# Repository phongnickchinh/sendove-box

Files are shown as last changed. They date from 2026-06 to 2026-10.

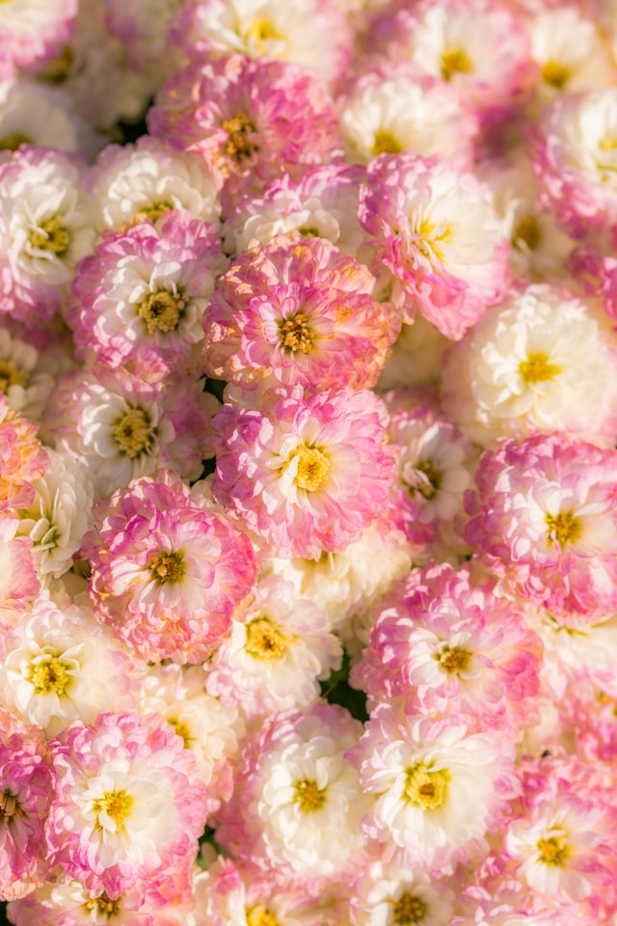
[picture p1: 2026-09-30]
sendlove_web/src/assets/login-hero.jpg

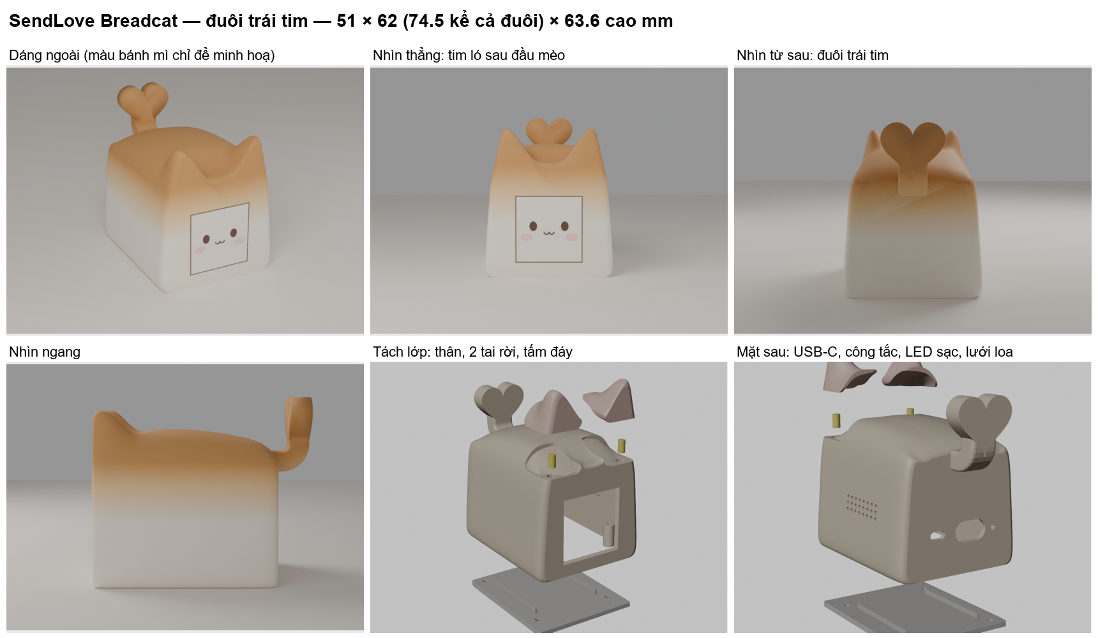
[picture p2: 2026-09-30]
sendlove_enclosure/breadcat/tong_hop.png

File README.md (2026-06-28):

# Sendlove Box

Dự án Hộp quà thông minh kết nối Wi-Fi, hiển thị video và phát âm thanh từ người gửi thông qua Firebase.

## Tổng quan phần cứng
- Vi điều khiển: ESP32-C3 (Kiến trúc RISC-V, tối ưu năng lượng)
- Màn hình: TFT LCD 1.77 inch (Giao tiếp SPI)
- Âm thanh: Module amply MAX98357A (Giao tiếp I2S) + Loa Mini
- Lưu trữ: Thẻ nhớ MicroSD + Module MicroSD (Giao tiếp SPI)
- Cảm biến chạm: Module điện dung TTP223
- Nguồn: Pin Lipo 3.7V + Mạch sạc TP4056 Type-C

## Kiến trúc phần mềm
- **Firmware**: C++ trên nền tảng PlatformIO. Sử dụng hệ điều hành thời gian thực FreeRTOS (Task-based architecture).
- **Backend**: Firebase Realtime Database (lưu cờ trạng thái) & Cloud Storage (lưu trữ phương tiện).
- **Frontend**: Web App (HTML/CSS/JS, Web Audio API, Canvas API) nhằm offload tác vụ xử lý tệp tin từ ESP32-C3 lên trình duyệt.

Chi tiết về đặc tả use case, luồng hoạt động và phương pháp thiết kế xem tại [ACTION_PLAN.md](ACTION_PLAN.md).

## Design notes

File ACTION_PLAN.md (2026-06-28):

# TÀI LIỆU ĐẶC TẢ KIẾN TRÚC VÀ KẾ HOẠCH DỰ ÁN: SENDLOVE BOX
*Phiên bản: 1.1 | Trạng thái: Sẵn sàng phát triển*

Tài liệu này đóng vai trò là "Bản thiết kế thi công" (Blueprint) cho toàn bộ dự án Sendlove Box, bao phủ từ phần cứng, firmware, backend cho đến luồng tương tác người dùng.

---

## 1. TỔNG QUAN CÔNG NGHỆ & PHƯƠNG PHÁP THIẾT KẾ

### 1.1. Danh sách công nghệ (Tech Stack)
* **Phần cứng (Microcontroller):** ESP32-C3 (Kiến trúc RISC-V, tối ưu năng lượng).
* **Firmware Framework:** C++ trên nền tảng PlatformIO. Sử dụng FreeRTOS API tích hợp sẵn trong ESP-IDF/Arduino Core để quản lý Task.
* **Cloud Backend:** Firebase Blaze Plan (Pay-as-you-go). Bao gồm các dịch vụ: Authentication (Xác thực), Realtime Database (Lưu cờ trạng thái), Cloud Storage (Lưu file nhị phân) và Hosting (Lưu mã nguồn Web).
* **Frontend Web App:** HTML/CSS/JS thuần hoặc React/Vue. Tích hợp Web Audio API (Thu âm WAV) và Canvas API (Encode Video sang RAW RGB565).

### 1.2. Các phương pháp thiết kế cốt lõi
* **Kiến trúc "Thin Client" (Trạm cuối siêu nhẹ):** Mọi tác vụ nặng (chuyển đổi video, âm thanh) bị ép lên trình duyệt web của người gửi. Hộp quà ESP32 chỉ làm nhiệm vụ "Tải về và Phát mù" để tiết kiệm RAM và CPU.
* **Quản lý năng lượng "Event-Driven Light-Sleep":** ESP32 duy trì trạng thái ngủ nông (Light-sleep) tắt Wi-Fi. Đánh thức bằng đa sự kiện (Multi-wakeup): Hết thời gian Timer 5 phút hoặc Tín hiệu ngắt (Interrupt) từ cảm biến chạm.
* **Smartwatch UI Style:** Màn hình TFT mặc định tắt đèn nền (thông qua băm xung PWM chân BLK). Chỉ sáng lên khi có tương tác vật lý (chạm) hoặc khi tới giờ báo thức.
* **Hệ điều hành thời gian thực (RTOS):** Chuyển từ kiến trúc vòng lặp nguyên thủy sang kiến trúc Task-based (FreeRTOS) để quản lý đa tiến trình song song.

---

## 2. DANH SÁCH LINH KIỆN PHẦN CỨNG (BOM)

| STT | Tên Linh kiện | Chức năng & Thông số kỹ thuật |
| :--- | :--- | :--- |
| 1 | **ESP32-C3 Super Mini** | Vi điều khiển chính, quản lý Wi-Fi, SPI, I2S. |
| 2 | **Màn hình TFT LCD 1.77 inch** | Giao tiếp SPI. Nối chân BLK (Backlight) vào 1 chân GPIO để điều tốc PWM. |
| 3 | **Module MicroSD Card** | Giao tiếp SPI. Đọc/ghi dữ liệu phương tiện. |
| 4 | **Thẻ nhớ MicroSD** | Dung lượng 2GB - 16GB, định dạng FAT32. |
| 5 | **Module MAX98357A** | Amply Class D, giao tiếp I2S (giải mã tín hiệu số ra analog). |
| 6 | **Loa Mini** | Trở kháng 8 Ohm, Công suất 1W - 2W. |
| 7 | **Module TTP223** | Cảm biến điện dung siêu nhạy (Touch Sensor). |
| 8 | **Đèn LED + Trở 330Ω** | Thông báo trạng thái (Hiệu ứng Breathing). |
| 9 | **Pin Lipo 3.7V** | Dung lượng 2000mAh (Kích thước phù hợp lòng hộp). |
| 10 | **Module TP4056 Type-C** | Mạch sạc và bảo vệ pin Lipo. |
| 11 | **Dây điện AWG 30 & AWG 24** | Loại lõi đặc (Solid core) để uốn góc 90 độ, đi dây trực tiếp. |
| 12 | **Vỏ hộp in 3D** | Nhựa PETG hoặc PLA+ (Màu Matte/nhám). |

---

## 3. THIẾT KẾ USE CASE & TÁC NHÂN (ACTORS)

**Tác nhân 1: Người gửi (Sender)**
1. Đăng nhập / Xác thực (Login).
2. Tạo thông điệp Video/GIF (Create Visual Message).
3. Tạo thông điệp Âm thanh (Create Voice Message).
4. Xem trước thông điệp (Preview).
5. Gửi thông điệp (Send Message).
6. Kiểm tra trạng thái Hộp quà (Check Box Status).

**Tác nhân 2: Người nhận (Receiver)**
1. Đăng nhập không gian quản lý (Login).
2. Cài đặt báo thức / Nhắc nhở (Set Alarm).
3. Xem lịch sử thông điệp (View History).
4. Xem dung lượng pin Hộp quà (Check Battery).
5. Chạm để mở quà / Xem giờ (Touch to Wake).

**Tác nhân 3: Hộp quà (Smart Box - Sbox)**
1. Đồng bộ thời gian thực (NTP Sync).
2. Kiểm tra và Tải dữ liệu định kỳ (Fetch Media).
3. Hiển thị Đa phương tiện (Play Media).
4. Quản lý trạng thái Ngủ (Sleep Management).
5. Báo cáo phần trăm pin (Report Battery).

---

## 4. ĐẶC TẢ CHI TIẾT USE CASE

**UC_S05: Gửi thông điệp (Tác nhân: Sender)**
* **Điều kiện tiên quyết:** Sender đã đăng nhập, đã encode xong file `.bin` và `.wav` trên trình duyệt. Sbox đã được kích hoạt.
* **Luồng cơ bản:** Trình duyệt đẩy file `.bin` và `.wav` lên Firebase Cloud Storage. Storage trả về 2 link tải. Trình duyệt cập nhật vào Realtime DB biến `has_new_msg = true` kèm theo 2 link trên. Giao diện báo gửi thành công.
* **Hậu điều kiện:** Máy chủ lưu trữ file sẵn sàng chờ Sbox tải.

**UC_R02: Cài đặt báo thức (Tác nhân: Receiver)**
* **Điều kiện tiên quyết:** Receiver truy cập Web App quản lý.
* **Luồng cơ bản:** Receiver nhập mốc thời gian báo thức (VD: 07:30). Web App đẩy chuỗi thời gian này lên node `config/alarm_time` trên Firebase Realtime DB.
* **Hậu điều kiện:** Sbox sẽ đọc và lưu cấu hình này vào chu kỳ thức dậy tiếp theo.

**UC_R05: Chạm để mở quà hoặc xem giờ (Tác nhân: Receiver & Sbox)**
* **Điều kiện tiên quyết:** Sbox đang trong trạng thái Light-sleep.
* **Luồng cơ bản:** Receiver chạm tay vào vỏ hộp. Cảm biến TTP223 kích hoạt ngắt phần cứng. Sbox thức dậy tức thời, kiểm tra cờ `co_tin_nhan` trên RAM.
* **Nhánh A (co_tin_nhan = true):** Bật đèn nền TFT, xuất đồng thời file từ thẻ SD ra SPI (hình ảnh) và I2S (âm thanh). Chạy xong, chuyển cờ về `false`, tắt màn hình.
* **Nhánh B (co_tin_nhan = false):** Tạm bật Wi-Fi kiểm tra Firebase ("Pull-to-refresh"). Nếu phát hiện có tin nhắn, tải về và chuyển sang Nhánh A. Nếu không có, hiển thị mặt Đồng hồ trong 5 giây, sau đó tắt màn hình.
* **Hậu điều kiện:** Sbox ra lệnh tắt Wi-Fi và gọi hàm vào lại Light-sleep.

**UC_Sbox01: Đồng bộ dữ liệu định kỳ (Tác nhân: Sbox)**
* **Điều kiện tiên quyết:** Sbox vừa thức dậy do hết 5 phút của Timer.
* **Luồng cơ bản:** Sbox bật Wi-Fi, kết nối mạng. Gọi HTTP GET lấy cấu hình báo thức mới và kiểm tra cờ `has_new_msg` trên Firebase. Nếu cờ là `true`, tải stream file `.bin` và `.wav` ghi thẳng vào thẻ SD. Đổi cờ nội bộ `co_tin_nhan = true`. Gọi HTTP PUT lên Firebase chuyển cờ trên cloud thành `false`.
* **Hậu điều kiện:** Dữ liệu nằm an toàn trong thẻ SD, Sbox ngắt mạng và đi ngủ chờ chạm.

---

## 5. MÔ TẢ API VÀ CẤU TRÚC DATABASE (FIREBASE)

**Firebase Realtime Database (Cấu trúc JSON)**
```json
{
  "boxes": {
    "box_id_001": {
      "status": {
        "battery_percent": 85,
        "is_online": false,
        "last_sync_timestamp": 1719567890
      },
      "messaging": {
        "has_new_msg": true,
        "video_url": "[https://firebasestorage.googleapis.com/.../video_001.bin](https://firebasestorage.googleapis.com/.../video_001.bin)",
        "voice_url": "[https://firebasestorage.googleapis.com/.../voice_001.wav](https://firebasestorage.googleapis.com/.../voice_001.wav)"
      },
      "config": {
        "alarm_time": "07:30",
        "is_alarm_active": true,
        "timezone": 7
      }
    }
  }
}
Firebase Cloud Storage Structure

/media/box_id_001/video_latest.bin (Ghi đè mỗi khi có tin nhắn mới).

/media/box_id_001/voice_latest.wav

6. KIẾN TRÚC FIRMWARE: PHƯƠNG PHÁP TASK (FREERTOS)
Task 1: Task_PowerManager (Độ ưu tiên: Cao nhất)
Nhiệm vụ quản lý sự sống còn của hộp. Lắng nghe cờ báo công việc từ các Task khác. Ra lệnh ngắt Wi-Fi, cài đặt Timer 5 phút, cài ngắt GPIO cảm biến chạm và gọi lệnh Light-sleep. Khi thức dậy, xác định nguyên nhân và phân luồng đánh thức các Task tương ứng.

Task 2: Task_NetworkHandler (Độ ưu tiên: Trung bình)
Chuyên trách giao tiếp mạng (Chỉ chạy khi PowerManager gọi). Bật Wi-Fi, cập nhật giờ NTP. Gọi HTTP GET/PUT tương tác với Firebase. Quản lý việc stream dữ liệu từ URL thẳng vào File object của thẻ MicroSD (Sử dụng buffer để chống tràn RAM).

Task 3: Task_MediaPlayer (Độ ưu tiên: Cao)
Phát hình ảnh và âm thanh mượt mà (Chỉ chạy khi có lệnh chạm). Sử dụng DMA (Direct Memory Access) để đọc block dữ liệu từ SD Card. Bơm song song buffer ảnh ra SPI và buffer âm thanh ra I2S. Đảm bảo đồng bộ hình tiếng.

Task 4: Task_UI_Controller (Độ ưu tiên: Thấp)
Quản lý hiệu ứng hình ảnh phụ. Điều khiển băm xung PWM cho LED nhịp thở. Điều tốc PWM chân BLK của màn hình (Sáng 100% ban ngày, 20% ban đêm). Xử lý chống nhiễu (Debounce) cho tín hiệu chạm.

7. YÊU CẦU PHI CHỨC NĂNG (NON-FUNCTIONAL REQUIREMENTS)
Hiệu năng (Performance): Tốc độ phản hồi khi chạm để bật màn hình phải nhỏ hơn 50ms. Tốc độ khung hình Video (Framerate) duy trì 15 - 20 FPS.

Năng lượng (Power): Dòng điện khi ngủ (Light-sleep) phải dưới 2mA. Thời lượng pin duy trì từ 15 đến 20 ngày với viên pin 2000mAh (Chu kỳ check mạng 5 phút/lần).

Lưu trữ (Storage): File .bin và .wav không vượt quá 15MB/tin nhắn để đảm bảo tính ổn định khi tải xuống bằng vi điều khiển.

Bảo mật (Security): Mọi kết nối API đi qua HTTPS. Firebase Rules chỉ cho phép user xác thực đúng box_id được quyền ghi/đọc.

Khả năng bảo trì (Maintainability): Không hàn chết linh kiện thành một khối. Sử dụng ngàm in 3D hoặc băng keo xốp 3M để cố định module.

8. CÁC LUỒNG HOẠT ĐỘNG CHÍNH (MAIN WORKFLOWS)
Luồng 1: Định kỳ nhận tin nhắn ngầm (Background Sync)
Sbox ngủ 5 phút -> Thức dậy bởi Timer -> Task_Network bật mạng, check Firebase -> Tải file vào thẻ SD -> Đổi cờ co_tin_nhan = true -> Task_UI bật LED nhịp thở -> Task_PowerManager ngắt mạng, tiếp tục ngủ.

Luồng 2: Tương tác mở quà tiêu chuẩn (Standard Playback)
Sbox đang ngủ (LED nháy) -> Người nhận chạm tay -> Thức dậy bởi GPIO Interrupt -> Task_PowerManager kiểm tra thấy có tin nhắn -> Task_MediaPlayer đẩy dữ liệu từ SD ra màn hình và loa -> Phát xong, tắt LED, tắt màn hình -> Task_Network báo Firebase đã đọc -> Vào giấc ngủ.

Luồng 3: Tương tác "Kéo để làm mới" hoặc xem giờ
Sbox đang ngủ (Không LED) -> Người nhận chạm tay -> Thức dậy -> Task_Network bật mạng kiểm tra Firebase.
Nếu có quà ẩn: Tải file và gọi Task_MediaPlayer phát ngay lập tức.
Nếu không có quà: Task_UI hiển thị mặt đồng hồ trong 5 giây, sau đó tắt màn hình và tiếp tục ngủ.

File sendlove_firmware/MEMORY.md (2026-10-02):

# SENDLOVE BOX - PROJECT MEMORY & CONTEXT

*Tài liệu này lưu trữ toàn bộ bối cảnh dự án, kiến trúc phần cứng, phần mềm và lịch sử các task để phục hồi context cho Agent trong các session tương lai.*

## 1. MÔ TẢ DỰ ÁN
**Sendlove Box** là một hộp quà tặng thông minh/video player dựa trên ESP32-C3.  
- **Core Functionality**: Trình chiếu video có âm thanh, hiển thị hình ảnh, giao diện đồng hồ Standby (động theo JSON), điều khiển chạm, đồng bộ thời gian thực qua WiFi/NTP và kết nối đám mây (Firebase).
- **MCU**: ESP32-C3-DevKitM-1 (160MHz, 320KB RAM, 4MB Flash).
- **USB CDC**: Kích hoạt trên GPIO 18/19 (`ARDUINO_USB_CDC_ON_BOOT=1` cho nạp code và in Serial).

---

## 2. KIẾN TRÚC PHẦN CỨNG
- **Màn hình**: TFT LCD 1.54"/1.3" ST7789 240x240 IPS. (Không có chân CS).
- **Lưu trữ Media**: W25Q128 (16MB NAND Flash SPI).
- **Điều khiển**: Touch Sensor TTP223 (GPIO 10, Active HIGH).
- **Sơ đồ chân (Pinout)**:
  - **Shared Hardware SPI2 Bus**: SCK (GPIO 4), MOSI (GPIO 6).
  - **TFT ST7789**: DC (7), RST (9), BL (3 - PWM). *CS = -1 (Không có)*.
  - **NAND W25Q128**: CS (8), MISO (5).
  - **Touch TTP223**: GPIO 10 (Active HIGH, INPUT_PULLDOWN).

> **Hardware Challenge (Đã giải quyết)**: 
> Màn hình ST7789 không có chân CS nên luôn nhận xung nhịp SPI. Việc chia sẻ chung bus SPI2 với NAND Flash gây hiện tượng nhiễu hình ảnh khi đọc dữ liệu NAND.
> **Giải pháp đang áp dụng**:
> - Đồng bộ cùng `SPI_MODE3` cho cả LGFX và NAND để không lệch bit do SCK Idle nhảy.
>   - ⚠️ **Đính chính 2026-09-04 — con số 3 KHÔNG bắt buộc, cái bắt buộc là CẢ BUS DÙNG CHUNG
>     MỘT MODE.** Cả MODE0 lẫn MODE3 đều lấy mẫu ở sườn LÊN; thiệt hại nằm ở mức idle của SCK —
>     đổi CPOL giữa hai chủ bus sinh 1 sườn lên giả nên ST7789 chốt nhầm 1 bit. MODE3 được chọn
>     chỉ vì driver flash dùng nó. Từ nay mode nằm ở `SPI_BUS_MODE` (`config.h`), đổi theo
>     `ACTIVE_STORAGE_TYPE`: **MODE3 cho NAND (không đổi), MODE0 cho thẻ SD** — vì thư viện `SD`
>     của Arduino-ESP32 hardcode `SPI_MODE0` và `SD.begin()` không có tham số mode. Xem mục 12.
>   - ❌ **ĐÍNH CHÍNH TRÊN LÀ SAI — kiểm chứng máy thật 2026-09-17**: nạp bản SD chạy MODE0 thì
>     **màn hình đen hoàn toàn** (đèn nền, touch, tiếng bíp vẫn chạy). Ép lại MODE3 thì hiển thị bình
>     thường. Panel ST7789 không CS này **BẮT BUỘC MODE3** — comment gốc "Mode 3 (obligatory)" ở
>     `DisplayDriver.h` là đúng từ thực nghiệm. Hướng đã chọn: chép thư viện SD vào `lib/SD` và đổi
>     sang MODE3 (xem mục 12).
> - Lệnh Hack NOP (`0x00`) với TFT_DC=0 rồi kéo TFT_DC=1 trước mỗi phiên lấy SPI Mutex của NAND, giúp màn hình ST7789 bỏ qua dữ liệu giao tiếp với Flash.

---

## 3. KIẾN TRÚC PHẦN MỀM (FIRMWARE)
- **Platform**: PlatformIO (Arduino Framework cho ESP32).
- **Libraries**:
  - `LovyanGFX` (Display driver chính, hỗ trợ bus_shared = true).
  - `JPEGDEC` (Giải mã VJPG / JPEG trực tiếp từ buffer NAND).
  - `ArduinoJson` (v7.0.0 - Parse cấu hình UI Layout động từ JSON).
- **Core Logic & State Machine**:
  - Trạng thái hệ thống: `STATE_STANDBY` (Hiển thị đồng hồ/ngày/icon WiFi & Pin) <-> `STATE_VIDEO` (Phát video/ảnh từ NAND).
  - **Task_MediaPlayer** (Priority 3, Stack 8KB): Render Standby UI theo chu kỳ 1s hoặc giải mã JPEG 15fps liên tục từ NAND Flash.
  - **Task_UIController** (Priority 5 - Cao nhất, Stack 4KB): Polling touch sensor (10ms/lần = 100Hz), quản lý LED và chuyển đổi state/slot qua `eventQueue`.
- **Cấu trúc Module (`lib/`)**:
  - `DisplayDriver`: Đóng gói LovyanGFX, mutex SPI.
  - `NandStorage`: Đọc NAND SPI Flash W25Q128 & Slot Table (Storage chính).
  - `SDCardManager`: Đọc/ghi thẻ MicroSD SPI (Storage linh hoạt).
  - `MediaPlayer`: Điều khiển phát frame VJPG qua JPEGDEC.
  - `UIController`: Đọc cảm ứng TTP223, điều khiển trạng thái LED.
  - `NetworkManager`: Quản lý hạ tầng Wi-Fi (STA, SoftAP Provisioning) & đồng bộ giờ NTP.
  - `FirebaseClient`: Giao tiếp Firebase REST API (check tin nhắn, status) & HTTP Stream Download.
  - `PowerManager`: Quản lý linh hoạt chế độ ngủ (Light-Sleep & Deep-Sleep) & Đọc ADC dung lượng Pin LiPo.
  - `LayoutEngine`: Render giao diện Standby động theo JSON config (Clock, Date, Icons).
  - `ConfigManager`: Đọc/ghi cấu hình NVS.
  - `OtaHandler`: OTA Firmware Update qua mạng LAN (WebServer + Update.h).

> **OTA WebServer Lifecycle**:
> Hiện tại WebServer luôn bật khi có WiFi (port 80, mDNS `sendlovebox.local`).
> Tương lai khi ghép nối hệ thống phần mềm, WebServer sẽ chỉ được kích hoạt
> khi người dùng trigger từ web client (tiết kiệm tài nguyên).

---

## 4. QUẢN LÝ DỮ LIỆU NAND (SLOT TABLE)
- **Cấu trúc**: 5 Slot lưu trữ (Video VJPG / Image VIMG).
- **Header**: Sector 0 (Địa chỉ `0x000000`), bắt đầu bằng Magic string `"NSLT"`.
- Addresses: `0x010000`, `0x340000`, `0x670000`, `0x9A0000`, `0xCD0000`.
- Module `NandStorage` chỉ thực hiện Read-Only để bảo tồn dữ liệu gốc đã được flash.

---

## 5. LỊCH SỬ CÔNG VIỆC (TASK LOG)

### Phase 1: Màn hình + NAND Read + Touch (Completed)
- [x] Quy hoạch GPIO dùng Shared HW SPI2 cho TFT và NAND.
- [x] Lập trình `DisplayDriver` bọc LovyanGFX.
- [x] Lập trình `NandStorage` API (Hardware SPI) cho đọc Slot Table và frames.
- [x] Lập trình `MediaPlayer` với `JPEGDEC` giải mã luồng từ `NandStorage`.
- [x] Fix lỗi xung đột SPI giữa ST7789 và W25Q128 (Đồng bộ SPI_MODE3, NOP Hack, Fix USB CDC boot delay).

### Phase 2: Standby UI & Dynamic Power Management (Current - In Progress)
- [x] Xây dựng `NetworkManager` kết nối WiFi (STA + SoftAP Captive Portal) & NTP Time Synchronization (`pool.ntp.org`, UTC+7).
- [x] Xây dựng `FirebaseClient` xử lý REST API Firebase và HTTP Stream Download.
- [x] Nâng cấp `PowerManager` hỗ trợ 2 chế độ **Light-Sleep** (1ms wakeup) và **Deep-Sleep** (5µA low-power).
- [x] Tích hợp khóa giữ mức LOW cho chân Backlight PWM (`PIN_TFT_BLK`) bằng `gpio_hold_en` giúp tắt hẳn màn hình khi ngủ.
- [x] Thêm USB Power Fallback (giả lập 4.0V khi chạy nguồn USB chưa cắm pin) để tránh hiểu nhầm hết pin.
- [x] Cấu hình ngắt GPIO Wakeup chuẩn cho TTP223 (GPIO 10) đánh thức chip từ Light-Sleep.
- [x] Xây dựng `LayoutEngine` parse và render giao diện Standby từ JSON config (widgets: clock_time, clock_date, wifi_icon, battery_icon).
- [x] Thiết lập State Machine (`STATE_STANDBY` <-> `STATE_VIDEO`) phản hồi sự kiện chạm TTP223.
- [x] Thêm thư viện `ArduinoJson@^7.0.0` vào `platformio.ini`.
- [x] Tối ưu FreeRTOS Task Priority (`TASK_PRIORITY_UI_CONTROLLER = 5`).
- [x] Triển khai OTA Update qua mạng LAN (WebServer + Update.h + ota_upload.py).
- [x] Custom Partition Table cho OTA A/B (app0 + app1 = 1.75MB mỗi partition).
- [x] Fix lỗi Light Sleep Wakeup trên ESP32-C3: Re-init toàn bộ LGFX pipeline (SPI bus + ST7789 panel + LEDC PWM) trong `turnOn()`, thêm `if(Serial)` & `delay(200)` cho USB CDC re-enumeration.
- [x] Fix lỗi nháy dư ảnh / xé hình góc dưới màn hình khi chuyển slot: Khóa SPI transaction (`startWrite`/`endWrite`) trong `decodeOneFrame()`, thêm cờ `_isSleeping` tránh re-init thừa khi màn hình đang bật.
- [x] Chuyển đổi hình nền mẫu pastel marble (`bg_defaut.png`) thành mảng $240 \times 240$ RGB565 `StandbyBackground.h` (115KB `PROGMEM`).
- [x] Triển khai thuật toán Bounding Box Patch (`drawBackgroundPatch`) cắt miếng dán hình nền khôi phục vị trí widget trước khi vẽ đè chữ/icon.
- [x] Tích hợp cờ Dirty Flag Cache (`_lastTimeStr`, `_lastDateStr`, `_lastRssiBars`, `_lastBatPercent`) giảm 98% lượt vẽ thừa trên SPI bus.
- [x] Convert và tích hợp 2 font Google **Chakra Petch SemiBold**: 48pt (`ChakraPetch_SemiBold_48.h`) cho đồng hồ giờ và 16pt (`ChakraPetch_SemiBold_16.h`) cho ngày tháng.
- [x] Đổi màu chữ đồng hồ/ngày/icon sang màu Đen (`#000000`) và Đỏ đậm (`#B83D3D`) nổi bật trên nền đá cẩm thạch pastel.
- [x] Fix lỗi chữ có khung nền đen: Thêm `canvas->setTextColor(cfg.color)` (1 tham số) ép LovyanGFX vẽ chữ ở chế độ nền trong suốt (Transparent Background).
- [x] Nới rộng Bounding Box lên `160x45` tránh viền chữ Chakra Petch 48pt tràn khung gây dư ảnh vết chữ cũ.
- [x] Tối ưu hóa đồng bộ thời gian NTP ngầm & Bộ đếm RTC nội bộ:
- [x] Xây dựng Lớp Trừu Tượng Lưu Trữ Media (`IStorageProvider`): Hỗ trợ đa bộ nhớ linh hoạt giữa NAND Flash (`NandStorageProvider`) và Thẻ nhớ SD (`SDStorageProvider`).
- [x] Khắc phục lỗi nén JSON Firebase dài: Triển khai Zero-Copy JsonDocument + `http.getString()` chống mất/tràn mảng tin nhắn Firebase URL.
- [x] Khắc phục lỗi ghi Flash NOR khi download stream: Cấu hình cơ chế Auto Per-Sector Erase (`_lastErasedSectorAddr`) và chừa 4-byte Offset Reserve ở `openForWrite()` giúp bảo toàn 100% dữ liệu tệp `.bin` tải về từ Firebase.
- [x] Hỗ trợ định dạng tệp `SLBX` Native (128x160 Raw RGB565 Framebuffer): Nhận diện container header `SLBX` tự động, căn giữa hiển thị trên LCD 240x240 với tốc độ 1ms không qua `JPEGDEC`. Tương thích 100% tệp container `SLBX`/`VJPG`/`VIMG` lẫn ảnh RAW JPEG.
  - `getTimeString()` và `getDateString()` đọc trực tiếp mốc giờ RTC nội bộ ESP32 (`getLocalTime(&timeinfo, 0)` không chờ / timeout = 0).
  - Loại bỏ hoàn toàn hiện tượng chớp màn hình về `00:00` và `Loading...` khi chuyển phút hoặc rớt Wi-Fi tạm thời.
  - Lệnh `configTzTime()` chỉ gọi 1 lần duy nhất lúc `init()`. Tiến trình NTP chạy ngầm trên FreeRTOS task (`Task_NtpSyncWorker`), không gây nghẽn/khựng UI.
  - Áp dụng ngưỡng sai số 5s (5s Drift Threshold): So sánh mốc giây NTP với RTC ($\Delta t = |ntpNow - rtcNow|$), nếu $\Delta t \le 5$s thì giữ nguyên RTC tránh nhảy/lùi phút trên UI.
  - Loại bỏ polling 15s/1h liên tục trong `NetworkManager::update()`. Chỉ gọi `triggerNtpSync()` theo sự kiện khi vừa boot hoặc vừa tỉnh dậy sau Light Sleep.
- [x] Tối ưu hóa chu kỳ Light Sleep Wakeup nâng thời lượng pin 1000 mAh từ **4.5 ngày lên ~23 NGÀY**:
  - Phân biệt nguyên nhân thức dậy `esp_sleep_get_wakeup_cause()` trong `main.cpp`.
  - Nếu thức dậy do Timer 5 phút (`ESP_SLEEP_WAKEUP_TIMER`): Màn hình giữ nguyên TẮT, chip chỉ Active **2 giây (`activeSleepTimeoutMs = 2000`)** cho NTP Sync ngầm chạy xong rồi **chui vào Light Sleep lại ngay lập tức** (giảm thời gian Active/chu kỳ từ 60s xuống 2s, giảm 96.6% thời gian thức vô ích).
  - Nếu thức dậy do Touch cảm ứng (`ESP_SLEEP_WAKEUP_GPIO`): Bật màn hình Standby và cho phép chờ 30s (`INACTIVITY_SLEEP_TIMEOUT_MS`).
  - Dòng tiêu thụ trung bình giảm từ `7.81mA` xuống **`~1.5mA`**, thời gian chờ của pin 1000 mAh tăng từ 4.5 ngày lên **~23 NGÀY** (gấp 5 lần).

### Phase 2.5: Big Refactoring & Optimization (Completed)
- [x] **Phase 1 (Chống Phân mảnh Bộ nhớ)**: Loại bỏ hoàn toàn việc lạm dụng `String` trong `NetworkManager`, `LayoutEngine`, `OtaHandler`. Chuyển sang dùng `char[]` tĩnh và `snprintf()`, triệt tiêu rò rỉ RAM (OOM / Heap Fragmentation).
- [x] **Phase 2 (Kiến trúc Task & DRY)**:
  - Phân tách `network.update()` ra FreeRTOS task riêng `Task_NetworkController` (Priority 2, Stack 8KB), giải quyết triệt để lỗi WebServer block UI Task (Priority 5).
  - Tạo module `SystemMonitor` quản lý nhiệt độ chip và bộ nhớ RAM, loại bỏ code lặp ở `LayoutEngine` và `MediaPlayer`.
  - Thêm helper `drawTextWidget` trong `LayoutEngine` giúp tái cấu trúc gọn gàng các widget text.
- [x] **Phase 3 (Bảo mật, NVS & Captive Portal Wi-Fi)**:
  - Tích hợp `ConfigManager` lưu Wi-Fi credentials vào NVS Flash (`Preferences`).
  - Xây dựng luồng Wi-Fi Provisioning: Tự động phát AP `SendloveBox-Setup` kèm Captive Portal Web UI (có nút ẩn/hiện mật khẩu `👁️`) khi chưa cài mạng hoặc mất Wi-Fi.
  - Thêm cờ `!network.isProvisioningActive()` ngăn thiết bị chui vào Light Sleep khi đang bật AP cài đặt.
- [x] **Phase 4 (Tối ưu SRAM & AppContext)**:
  - Chuyển `_jpegBuffer` 48KB từ mảng static giam RAM vĩnh viễn sang cấp phát động (`malloc()` khi phát media và `free()` ngay khi dừng), hoàn trả 48KB RAM cho màn hình Standby.
  - Gom toàn bộ 9 biến toàn cục trong `main.cpp` vào struct `AppContext appCtx` theo chuẩn Clean Architecture.

### Phase 3A: Storage Abstraction Layer (Completed)
- [x] Tạo interface trừu tượng `IStorageProvider` định nghĩa tập API đọc/ghi luồng byte và quản lý hàng chờ tin nhắn.
- [x] Xây dựng `NandStorageProvider` bọc chip W25Q128 16MB (quản lý 5 slot fixed offset + unread bitmask trên NVS).
- [x] Xây dựng `SDStorageProvider` bọc thẻ MicroSD FAT32.
- [x] Refactor `MediaPlayer` và `main.cpp` tách khỏi sự phụ thuộc NAND thô, cho phép chuyển đổi linh hoạt NAND <-> SD Card qua cờ `#define ACTIVE_STORAGE_TYPE` trong `config.h`.

### Phân tách Kiến trúc Chuẩn (Separation of Concerns):
1. **Bài toán Pairing (Web App / Cloud Backend):**
   - Ghép nối giữa **Sender App <-> System <-> Receiver App**.
   - Hộp quà ESP32 hoàn toàn không cần tham gia logic này. Kết quả pairing chỉ chốt thông tin trên Cloud Database.
2. **Bài toán Bảo mật (Firmware Box <-> Cloud System):**
   - Xác thực giao tiếp giữa **ESP32 Box <-> Firebase System**.
   - ESP32 chỉ cần dùng `BOX_ID` + `Token` (hoặc Database Secret) lưu trong NVS để xác thực đường truyền HTTPS và tải đúng dữ liệu tin nhắn của Box mình về.

---

## 6. LƯU Ý PHẦN CỨNG & KIẾN THỨC KỸ THUẬT QUAN TRỌNG

### A. Cơ chế ngắt & Wakeup trên ESP32-C3
1. **Phần cứng nhận biết nguyên nhân Wakeup (`esp_sleep_get_wakeup_cause`)**:
   - Khi CPU đi vào Light/Deep Sleep, khối **RTC Power Management Controller (Always-On Domain)** vẫn liên tục giám sát phần cứng.
   - Khi sự kiện chạm (GPIO_10 HIGH) hoặc hết giờ (RTC Timer) xảy ra, phần cứng RTC tự động ghi cờ (bit) vào thanh ghi `RTC_CNTL_WAKEUP_STATE_REG` **trước khi cấp lại xung clock đánh thức CPU**.
   - Hàm `esp_sleep_get_wakeup_cause()` chỉ việc đọc thanh ghi phần cứng này ra mà không cần CPU phải chạy code đếm trước đó.
2. **Cấu hình Touch Wakeup (TTP223)**:
   - Sử dụng `GPIO_PULLDOWN_ENABLE` trên GPIO 10 để kéo chân xuống GND, tránh chân bị floating (trôi điện áp gây tự thức dậy ngẫu nhiên).
   - Sử dụng kiểu ngắt `GPIO_INTR_HIGH_LEVEL` kích hoạt qua `gpio_wakeup_enable()` và `esp_sleep_enable_gpio_wakeup()`.
3. **Phân biệt chân Wakeup theo Sleep Mode**:
   - **Light Sleep Wakeup**: Hỗ trợ toàn bộ các chân GPIO 0-21 (GPIO 10 hoạt động rất tốt).
   - **Deep Sleep Wakeup**: Chỉ hỗ trợ các chân RTC GPIO (GPIO 0 -> GPIO 5 trên ESP32-C3). Nếu muốn chuyển sang dùng Deep Sleep với TTP223, bắt buộc phải nối lại phần cứng sang GPIO 0-5.

### B. Cơ chế đếm nối thời gian thực & NTP Sync ngầm
1. **Bộ đếm RTC nội bộ (RTC Slow Clock)**:
   - Khi gọi `configTzTime()`, ESP-IDF lấy mốc Unix Epoch từ NTP Server và liên kết với bộ đếm phần cứng RTC Timer.
   - Khi vào Light Sleep, CPU dừng nhưng RTC Timer vẫn đếm liên tục.
   - Gọi `getLocalTime(&timeinfo, 0)` với timeout = 0 đọc trực tiếp mốc giờ RTC mà không bị nghẽn hay chờ đợi.
2. **Phân biệt Modem Sleep (Duy trì IP) vs Full Wi-Fi Off (`WIFI_OFF`)**:
   - **Modem Sleep (Light Sleep tự động ngắt RF)**: Cắt nguồn phần cứng thu phát RF nhưng **giữ lại 100% IP, WPA2 Key và Session trong RAM**. Khi thức dậy, gửi gói tin NTP được ngay trong 0.1-0.3s (~27mAs).
   - **Full Wi-Fi Off (`WIFI_OFF`)**: Xóa sạch Driver Wi-Fi. Khi thức dậy phải quét kênh, bắt tay WPA2 4 bước và xin lại IP từ DHCP, mất 1.5 - 3.0s (~300mAs).
3. **Điểm bão hòa năng lượng (Break-even Point)** giữa Modem Sleep và `WIFI_OFF`:
   - Phép tính bão hòa năng lượng: $(1.2 \cdot T) + 27 = (0.8 \cdot T) + 300 \Rightarrow T = 682.5\text{s} = \mathbf{11\text{ phút } 22\text{ giây}}$.
   - **Thời gian ngủ $< 11.37$ phút** (ví dụ chu kỳ 5 phút): **Modem Sleep tiết kiệm hơn ~28%** (tránh được chi phí 300mAs bắt tay lại Wi-Fi).
   - **Thời gian ngủ $> 11.37$ phút** (ví dụ ngủ qua đêm 8 tiếng): **`WIFI_OFF` tiết kiệm hơn ~32.5%** (do chênh lệch dòng rò 0.4mA tích lũy lâu dài).

### C. Quản lý tiêu thụ điện năng & Đèn LED báo nguồn (Power LEDs)
1. **Thực trạng ngốn pin của LED báo nguồn**:
   - Trên bo mạch ESP32 DevKit và Module NAND Flash W25Q128 đều có sẵn đèn LED đỏ báo nguồn (Power LED) nối trực tiếp VCC-GND qua điện trở.
   - **Dòng tiêu thụ**: 2 con LED đỏ ngốn tổng cộng **$\approx 3\text{mA} - 6\text{mA}$**.
   - Trong khi đó:
     - ESP32-C3 ở **Light Sleep**: Chỉ tiêu thụ $\approx 1.0\text{mA}$ (LED ngốn gấp 4 lần chip).
     - ESP32-C3 ở **Deep Sleep**: Chỉ tiêu thụ $\approx 0.005\text{mA}$ / $5\mu\text{A}$ (LED làm lãng phí 99.9% năng lượng pin).
   - **Tác động**: Làm giảm thời gian chờ của pin 1000mAh từ **52 ngày xuống chỉ còn 9 ngày**!
2. **Giải pháp khắc phục**:
   - *Bản Prototype*: Dùng mỏ hàn xả bỏ (tháo) LED báo nguồn / điện trở hạn dòng trên DevKit và Module NAND Flash, hoặc dán băng keo đen che sáng.
   - *Bản thiết kế PCB thực tế*: Không vẽ LED báo nguồn cố định; dùng P-Channel MOSFET (AO3401) hoặc Power Switch IC (TPS22919) để cắt hẳn nguồn 3.3V cấp cho Module NAND khi chip đi vào chế độ ngủ.

### D. Khóa phần cứng RTC GPIO Hold và Reboot (`ESP.restart()`)
- Khi gọi `gpio_hold_en(PIN_TFT_BLK)` trước khi ngủ, mạch RTC phần cứng khóa chân Backlight (GPIO 3) ở mức `LOW`.
- Trạng thái **GPIO Hold phần cứng này được bảo lưu qua cả quá trình Software Reset / Reboot (`ESP.restart()`)**.
- Nếu không giải phóng khóa, sau khi reboot màn hình sẽ bị tối om dù code khởi tạo đã chạy.
- **Giải pháp**: Luôn gọi `gpio_hold_dis((gpio_num_t)PIN_TFT_BLK)` ngay đầu hàm `DisplayDriver::init()` để giải phóng cờ khóa phần cứng khi khởi động lại.

### E. Quy tắc tính toán `millis()` tránh tràn số âm (Underflow Bug)
- Với kiểu dữ liệu `uint32_t`, **tuyệt đối không gán mốc thời gian ở tương lai** (ví dụ: `lastUserActivity = millis() + 15000`), vì phép tính `now - lastUserActivity` ở vòng lặp sau sẽ bị underflow tràn số ra `4,294,952,306` (làm `now - lastUserActivity >= timeout` luôn trả về `true` lập tức).
- **Giải pháp**: Giữ `lastUserActivity = millis()` chuẩn thời gian thực và thay đổi giá trị điều kiện so sánh `activeSleepTimeoutMs` (15s cho Touch Wakeup, 30s cho Timer Wakeup, 2s cho Timer Sleep Wakeup).

### Phase 3B: Firebase Realtime Database & Storage Wakeup Integration (Completed)
- [x] Tích hợp trực tiếp Firebase REST API vào `NetworkManager` (`syncFirebaseWakeup`, `updateFirebaseStatus`, `checkFirebaseFlags`, `syncFirebaseAlarms`, `checkAndDownloadNewMessages`).
- [x] Loại bỏ hoàn toàn interval timers riêng. Đồng bộ tập trung 1 lần khi chip tỉnh dậy (Timer Wakeup 5 phút hoặc Touch Wakeup).
- [x] Triển khai tính toán sleep timer động trong `ConfigManager::getSecondsToNextAlarm(nowSec)` và `main.cpp`: `sleepTimeUs = min(SLEEP_TIMER_US, alarmUs)`.
- [x] Hỗ trợ tải dữ liệu media streaming dạng chunk 256B từ Firebase Storage vào thẳng `IStorageProvider` (NAND/SD) tránh tràn RAM ESP32-C3.
- [x] **Tối ưu hóa Non-blocking Touch UI**: Tạo `NetworkManager::triggerFirebaseSync(...)` khởi chạy task ngầm FreeRTOS (`FbSync`, Stack 8KB, Priority 2). Giải phóng 100% `Task_UIController` (Priority 5) giúp vòng lặp đọc cảm ứng TTP223 100Hz hoạt động liên tục, hoàn toàn không bị block/giật lag khi mạng HTTPS đang sync.
- [x] **Ghi thật vào SPI Flash W25Q128 (16MB)**: Triển khai lệnh `eraseSector` (4KB sector erase `0x20`) và `writeRaw` (Page Program `0x02` 256B) trong `NandStorage` & `NandStorageProvider`. Dữ liệu media tải từ Firebase Storage được ghi đè trực tiếp vào các Slot Flash thực tế của chip W25Q128.
- [x] **Tính năng Erase/Format NAND Flash khi boot**: Đã thêm `formatStorage()` giúp xóa sạch Sector 0 (Header) và 5 Sector của 5 Slot mẫu cũ trên chip W25Q128 + reset cờ `unread_mask` NVS về 0.
- [x] **Tín hiệu trực quan & Khóa chống ngủ khi tải (Download Sleep Lock & UI Signal)**: Thêm cờ `_isDownloadingMedia` và `NetworkManager::isDownloadingMedia()`. Tự động bật màn hình hiển thị `"Downloading..."` (và `"Download Done!"` khi xong), đồng thời khóa `Task_UIController` không cho chip chui vào Light Sleep trong suốt thời gian tải dữ liệu mạng.
- [x] **Khắc phục triệt để lỗi `Storage Err!` khi Format**: Thêm `NandStorage::writeSlotTable()`. Khi chip Flash bị Format/xóa Sector 0, `NandStorage::init()` tự động kiến tạo lại bảng Header `"NSLT"` mới sạch sẽ, loại bỏ hoàn toàn treo màn hình `Storage Err!`.
- [x] **Thông báo Debug trực quan trên màn hình (`DEBUG_SCREEN`)**: Bổ sung hiển thị trực quan các bước giao tiếp Firebase trên màn hình TFT (`"Checking Firebase..."`, `"Polling Msg..."`, `"No New Msg"` / `"Found New Msg!"`, phần trăm tiến độ `"Downloading XX%"`, `"Download Done!"` và thông báo mã lỗi HTTP nếu có) với comment `// DEBUG_SCREEN:` rõ ràng để dễ dàng thu hồi sau này.
- [x] **Sửa lỗi `FB http Err: 400` (Firebase REST 400 Bad Request)**: Bỏ các tham số `orderBy` và `startAt` trong URL REST API (nguyên nhân đòi hỏi Database Indexing Rules trên Firebase), chuyển sang lọc `if (timestamp > lastTs)` trực tiếp trong code C++.
- [x] **Sửa lỗi `FB HTTP Err: -1` (Connection Refused / Network Not Ready)**: Thêm vòng lặp chờ Wi-Fi re-associate ổn định và xin lại IP (tối đa 5s) khi vừa đi ngủ dậy từ Light Sleep + cơ chế tự thử lại `http.GET()` lần 2 nếu bị rớt socket tạm thời.
- [x] **Hiển thị mốc timestamp `lastTs` & `msgTs` trên màn hình**: Bổ sung debug hiển thị giá trị `lastTs` trong NVS và `msgTs` đọc được từ Firebase lên màn hình TFT để xác minh lý do tin nhắn bị xem là cũ và bị Skip.
- [x] **Đồng bộ Firebase tức thì khi boot (`Boot-time Instant Sync`)**: Thêm `triggerFirebaseSync(...)` trực tiếp vào `setup()` của `main.cpp` giúp ESP32 tự động sync Firebase ngay khi vừa nạp code/bật nguồn thành công mà không phải chờ 30 giây hay đợi ngắt chạm.
- [x] **Reset mốc `lastTs` về 0 khi Format Flash**: Tích hợp reset mốc thời gian NVS `last_download_ts` về `0` trong `NandStorageProvider::formatStorage()`, giúp ESP32 sẵn sàng kéo lại toàn bộ tin nhắn từ Firebase từ đầu sau khi xóa dữ liệu Flash NAND.
- [x] **Khóa Sleep toàn diện trong lúc Sync (`isFirebaseSyncing`)**: Sửa cờ khóa sleep trong `main.cpp` từ `isDownloadingMedia` (chỉ khóa khi tải file) thành `isFirebaseSyncing` (khóa toàn bộ chu trình từ lúc bắt đầu gọi request). Đảm bảo chip thức liên tục 100% trong suốt quá trình giao tiếp Firebase, không bị sập nguồn/ngủ giữa chừng (Sleep interrupt) gây ngắt quãng tải dữ liệu.
- [x] **Xử lý linh hoạt Link Firebase Storage**: Tự động nhận diện và convert đường dẫn dạng relative path (VD: `media/ESP32...`) hoặc `gs://...` được lưu trên Database thành dạng HTTPS REST Download URL hợp lệ (`https://firebasestorage.googleapis.com/...`) để ESP32 có thể tải file thành công bằng `HTTPClient`.
- [x] **Cảnh báo thiếu đường dẫn tải (`No Media URL!`)**: Thêm hiển thị báo lỗi chữ đỏ `"No Media URL!"` nếu tin nhắn mới kéo về không hề chứa đường link (`bin_url`, `video_url`, hoặc `image_url`) nhằm giúp debug tại sao bị skip tiến trình Download.
- [x] **Xử lý triệt để lỗi mất URL dài (`Zero-Copy JSON Parsing & Flexible Key Matcher`)**: Chuyển về `deserializeJson(doc, payload)` Zero-Copy. Đồng thời nâng cấp bộ parser hỗ trợ linh hoạt cả cấu trúc Firebase `JsonObject` và `JsonArray`, tự động quét tất cả các biến thể đặt tên key (`bin_url`, `binUrl`, `video_url`, `videoUrl`, `image_url`, `imageUrl`, `media_url`, `mediaUrl`, `url`) để đọc đúng 100% dữ liệu từ Firebase.
- [x] **Xử lý tự động hiển thị Ảnh/Video ngay khi tải từ Firebase (`Raw JPEG & Slot Header Auto-Generation`)**: 
  - Khắc phục triệt để nguyên nhân tải 100% nhưng không hiện ảnh: Khi tải từ Firebase về Flash NAND, code tự động kiểm tra byte đầu tiên. Nếu là file ảnh `.jpg` thô (`0xFF 0xD8 0xFF`), ESP32 sẽ tự động chèn 4-byte `jpegSize` vào đầu dữ liệu slot.
  - Tự động ghi nhãn `"VIMG"` (cho ảnh) hoặc `"VJPG"` (cho video) vào bảng Slot Table (`Sector 0`) để `NandStorage` và `MediaPlayer` công nhận Slot hợp lệ và lập tức giải mã hiển thị hình ảnh rực rỡ trên màn hình LCD.
- [x] **Tự động phát Media ngay sau khi tải xong (`Auto Play on Download Complete & Screen Overwrite Fix`)**: Tích hợp Event-driven callback `setOnDownloadComplete`. Đã loại bỏ triệt để xung đột giao diện làm chữ `"All Sync Done!"` in đè và xóa mất bức ảnh vừa được `MediaPlayer` hiển thị. Bức ảnh/video sẽ được giữ nguyên 100% rực rỡ trên màn hình LCD.
- [x] **Thông báo hoàn tất (`All Sync Done`)**: Thêm hiển thị chữ `"All Sync Done!"` trên màn hình khi toàn bộ tiến trình Firebase đã kết thúc thành công.
- [x] **Cập nhật Quy tắc Indexing trên Firebase (`database.rules.json`)**: Bổ sung `.indexOn: ["timestamp"]` cho node `messages/$box_id`, cho phép lọc Server-side trên Firebase.
- [x] Tối ưu Server-side Filtering & Zero-Copy Stream Parsing (`NetworkManager`):
  - Đính kèm query parameters `orderBy="timestamp"&startAt=<nextTs>` vào HTTP GET request gửi lên Firebase REST API. Khi không có tin mới, Firebase Server trả về `{}` (2 bytes), giảm 99% tải băng thông & CPU/RAM cho Box.
  - Sử dụng Stream parsing trực tiếp từ HTTP socket (`deserializeJson(doc, *stream)`), loại bỏ hoàn toàn cấp phát mảng chuỗi tạm `http.getString()`, chống triệt để phân mảnh RAM Heap trên ESP32-C3.
- [x] Biên dịch thành công 100% (`[SUCCESS]`), RAM 19.0% (62KB/328KB), Flash 71.3% (1.30MB/1.83MB).

### Phase 3C: Advanced Playback & Touch Refactoring (Completed)
- [x] **Cấu trúc lại Metadata Storage (maxDisplayTime)**: Tận dụng vùng nhớ `reserved` 4-byte trong bảng Header `SlotEntry` của NAND Flash Sector 0 để lưu trữ tĩnh thông số `max_display_time`.
- [x] **Refactor cơ chế Touch (Long/Short Press)**: Nâng cấp `UIController` nhận diện `SHORT_PRESS` (bấm nhanh chuyển slot, đánh dấu đã đọc) và `LONG_PRESS` (bấm giữ 3s ép về Standby mà không đánh dấu đã đọc).
- [x] **Biến đếm `_numOfNewMsg`**: Theo dõi chính xác tổng tin nhắn chưa đọc còn lưu trong NAND Flash cộng với tin đang chờ tải trên Cloud. Box dừng phát khi xem xong tin mới (khi biến về 0) thay vì lặp lại vòng tròn các slot cũ.
- [x] **An toàn NAND Flash (Chặn Download khi Play)**: Box chỉ trigger tiến trình Download khi RAM/SPI bus rảnh rỗi ở màn hình chờ (người dùng xem xong tin cũ, Touch bị vô hiệu hóa tạm thời với thông báo `Downloading...`).
- [x] **Auto Timeout Next**: Tự động chuyển media sau khi hiển thị đủ `maxDisplayTime` giây (hoặc quay về UI nếu hết tin).
- [x] **Interval Sync & Full Storage Guard**: Tự động check Firebase định kỳ 5 phút/lần khi ở màn hình Standby, đồng thời kiểm tra `appCtx.storage->isFull()`. Nếu toàn bộ 5 slot NAND đều chứa tin chưa đọc (đầy), hệ thống tự động bỏ qua lượt check ngầm để tránh block cảm ứng và tiết kiệm mạng/RAM.
- [x] **Sắp xếp thứ tự phát tin nhắn (`std::sort`)**: Ép mảng `msgList` qua `std::sort` theo mốc `timestamp` tăng dần trước khi lưu NAND, đảm bảo 100% tin nhắn cũ nhất luôn phát trước, tin mới phát sau.
- [x] **Fix SPI Deadlock khi Render Ảnh lớn (Chunking)**: Sửa hàm `decodeOneFrame()` trong `MediaPlayer.cpp` đọc từng chunk pixel từ NAND trước, sau đó mới acquire SPI để push lên LCD, loại bỏ hoàn toàn hiện tượng xé hình / mất 2/3 ảnh đối với file > 48KB.
- [x] **KISS 10s Awake Polling & Independent Sleep Timer**: Thiết lập kiểm tra Firebase ngầm định kỳ 10 giây/lần khi ở Standby UI (`now - lastIntervalSyncMs >= 10000`). Đồng thời tách biệt hoàn toàn bộ đếm ngủ `lastUserActivity` (chỉ reset khi chạm tay hoặc đang thực sự tải tệp media `isDownloadingMedia`), giúp box vừa hút tin nhắn nhạy bén 10s/lần vừa đi ngủ chính xác 100% theo thời gian đếm ngược.
- [x] **Khắc phục triệt để lỗi mất Backlight PWM khi thức dậy**: Loại bỏ hoàn toàn sự quản lý đèn nền của thư viện LovyanGFX (do lỗi từ chối khởi tạo lại và khai báo cứng sai `pwm_channel = 7` không tồn tại trên ESP32-C3). Chuyển sang khởi tạo thủ công bằng Arduino API (Sử dụng Channel 0). Khi ngủ dùng `pinMode(OUTPUT)` / `digitalWrite(LOW)` ép đèn tắt hẳn, khi thức tự gọi `ledcAttach`/`ledcAttachPin` nối lại PWM, giải quyết thành công lỗi đèn sáng mờ khi ngủ và đen màn hình khi thức.
- [x] **Cập nhật Sleep Timeout Logic**: Chặn thiết bị tự động đếm giờ đi ngủ khi đang phát Video. Khi Video phát hết `max_display_time`, rớt về màn hình UI và reset lại mốc tính thời gian ngủ.

---

### Phase 3D: Khắc phục triệt để lỗi Timer Wakeup, Wi-Fi Reconnect & NTP Sync Drift (Completed)
- [x] **Khắc phục lỗi trôi giờ (RTC Fast Drift) khi Sleep dài**:
  - *Nguyên nhân cốt lõi*: `getLocalTime(&timeinfo, timeout)` trong Arduino ESP32 core kiểm tra `tm_year > 2016`. Do time đã được sync lúc boot, hàm này trả về `true` ngay lập tức (0ms) với giờ RTC đang bị trôi từ dao động RC nội bộ, không hề chờ gói tin NTP từ mạng. Đồng thời, `ntpTaskWorker` không khóa tiến trình sleep, khiến chip bị ép vào Light Sleep sau 2s trước khi socket SNTP kịp nhận phản hồi.
  - *Giải pháp*: Đăng ký `sntp_set_time_sync_notification_cb()` (API chính thức ESP-IDF) để nhận callback khi SNTP daemon thực sự gọi `settimeofday()`. Trong `syncNtpTime()`, gọi `configTzTime()` (Arduino API đã chứng minh) để trigger SNTP request mới, rồi poll cờ `s_ntpSyncDone` từ callback thay vì dùng internal API `sntp_get_sync_status()` (đã được chứng minh unreliable trên hardware thật — NTP timeout 100%).
  - *Lưu ý*: Phiên bản đầu tiên dùng `sntp_set_sync_status(RESET)` + `sntp_restart()` + poll `sntp_get_sync_status()` — build thành công nhưng NTP luôn timeout trên hardware thật do internal API không cập nhật status flag đáng tin cậy qua ranh giới LWIP thread / FreeRTOS task.
- [x] **Khắc phục lỗi mất kết nối Wi-Fi sau 1 ngày Sleep**:
  - *Nguyên nhân cốt lõi*: Khi thức dậy từ Light Sleep, `ensureConnected()` gọi `WiFi.reconnect()` bất đồng bộ. Tuy nhiên `triggerNtpSync()` và `triggerFirebaseSync()` kiểm tra ngay `WiFi.status() != WL_CONNECTED` nên lập tức abort. Sau 2 giây, chip lại bị ép đi ngủ, cắt ngang quá trình bắt tay 4 bước (4-way handshake) của Wi-Fi. Lặp lại qua hàng trăm chu kỳ khiến Wi-Fi stack bị kẹt (`AUTH_EXPIRE`/`ASSOC_EXPIRE`).
  - *Giải pháp*: 
    - Nâng cấp `ensureConnected(uint32_t timeoutMs)` 2 tầng: thử `WiFi.reconnect()` trước; nếu không thành công sẽ tự động thực hiện `WiFi.disconnect(false)` và `WiFi.begin(_wifiSsid, _wifiPassword)` để tái thiết lập kết nối sạch sẽ từ đầu.
    - Lưu giữ credentials Wi-Fi trong `NetworkManager` và kích hoạt `WiFi.setAutoReconnect(true)`.
- [x] **Hợp nhất tiến trình Đồng bộ ngầm (`triggerWakeupSync` & `isSyncing`)**:
  - Hợp nhất chu trình: `ensureConnected(5000)` -> `syncNtpTime(5000)` -> `updateFirebaseStatus` -> `checkFirebaseFlags` -> `checkAndDownloadNewMessages` vào 1 FreeRTOS background task duy nhất (`WakeSync`).
  - Cập nhật cờ `isSyncing()` bao quát toàn bộ tiến trình mạng (Wi-Fi, NTP, Firebase, Download). `Task_UIController` được khóa không cho phép chip đi ngủ trong lúc bất kỳ tác vụ mạng nào đang xử lý, triệt tiêu hoàn toàn tình trạng sập nguồn/ngắt giữa chừng.

---

### Phase 3E: Audio I2S, Chống rè/nháy & Captive Portal nâng cấp (2026-08 → 09-01)

> **Đọc kỹ cột trạng thái.** Phần lớn mục dưới đây **chưa được kiểm chứng trên phần cứng**
> và **chưa commit** — chỉ nằm trong working tree. Đừng coi là đã xong.

#### Phần cứng bổ sung (thiếu ở §2 phía trên)
- **Ampli I2S MAX98357A**: BCLK = GPIO 0, LRC = GPIO 1, DOUT = GPIO 2 (`include/config.h:123-125`).
- **Module `AudioPlayer`** (`lib/MediaPlayer/AudioPlayer.cpp/.h`): phát PCM raw 16-bit mono qua
  I2S DMA, thiết kế non-blocking tick-based — mỗi frame video gọi `tick()` một lần nạp thêm DMA.
  Audio nằm nối đuôi video trong cùng một slot NAND, đánh dấu bằng header `AUDC`.
- **Module `ScreenLogger`** (`lib/ScreenLogger/`) — cũng chưa có trong danh sách module ở §3.

#### Nguyên nhân gốc của "rè tiếng + nháy đèn nền" (đã xác nhận bằng đo thực tế của user)
Đèn nền LED và MAX98357A **dùng chung một rail nguồn**. Đỉnh dòng của CPU/SPI cộng dồn lên dòng
ampli đang kéo → LED tối đi (thấy nháy) và ampli đói dòng (nghe rè) **cùng một nhịp**. Không phải
lỗi chất lượng file WAV: user đã nghe file `.wav` sinh ra từ web, xác nhận "ấm áp, không rè".

| Thay đổi | Ở đâu | Trạng thái |
|---|---|---|
| `extractAudioFromVideo` giải mã offline + `DynamicsCompressor` (-6dB) + trần đỉnh 0.7 | `sendlove_web/src/utils/mediaEncoder.js` | Trong working tree, **chưa commit**, đã chạy thật trên trình duyệt |
| Pacer bỏ frame khi trễ (`FRAME_MIN_IDLE_MS=2`, `decodeOneFrame(bool skipRender)`, `_lastFrameSkipped`) | `lib/MediaPlayer/MediaPlayer.cpp/.h` | Đã build + nạp, **CHƯA kiểm chứng phần cứng** |
| Timeout 10s khi tải không tiến triển + log tiến độ mỗi 16KB (video **và** audio) | `lib/NetworkManager/NetworkManager.cpp` | ✅ **ĐÃ KIỂM CHỨNG MÁY THẬT 2026-09-01: tải chạy ổn** |
| Captive portal: `WIFI_AP_STA`, `setErrorReplyCode(NoError)`, 8 URL dò của OS trả 302, endpoint `/scan` quét bất đồng bộ, HTML có danh sách Wi-Fi bấm chọn | `NetworkManager.cpp/.h`, `captive_portal_html.h` | ✅ **ĐÃ KIỂM CHỨNG MÁY THẬT 2026-09-01: AP + captive portal ổn** |
| Fix `fillChunk()` thiếu oversample x4: I2S init 32kHz nhưng data chỉ expand Mono→Stereo (không lặp mẫu) → audio phát nhanh gấp 4 + DMA underrun → tiếng rẹt rời rạc | `lib/MediaPlayer/AudioPlayer.cpp:192-219` | ✅ **ĐÃ KIỂM CHỨNG MÁY THẬT 2026-09-02: audio hết rẹt, đúng tốc độ** |
| Fix giật chậm / âm thanh nhảy ngắt quãng khi phát message: Tắt `ScreenLogger` overlay khi play video, hoãn `WakeSync` mạng trong `STATE_VIDEO`, tăng DMA buffer lên 24 (384ms), bỏ delay thừa và sửa deadline Frame 0 | `MediaPlayer.cpp`, `ScreenLogger.cpp/.h`, `NetworkManager.cpp/.h`, `main.cpp`, `config.h` | ✅ **Đã cập nhật 2026-09-02** |
| Fix Reboot khi Long Press -> Short Press ngay: Giữ I2S driver thường trực (chỉ `i2s_zero_dma_buffer` khi stop, không uninstall/install) + Cấp phát `_jpegBuffer` 48KB cố định 1 lần lúc `init()` (không malloc/free liên tục) | `AudioPlayer.cpp/.h`, `MediaPlayer.cpp/.h` | ✅ **Đã cập nhật 2026-09-02** |
| Nâng cấp chất âm: Triển khai Nội suy tuyến tính (Linear Interpolation) trong `fillChunk()` thay vì lặp mẫu bậc thang (ZOH) → triệt tiêu sóng hài chói gắt, làm mềm và ấm giọng nói | `lib/MediaPlayer/AudioPlayer.cpp:190-210` | ✅ **Đã cập nhật 2026-09-02** |
| Fix Firebase sync lỗi (-1): Giảm MbedTLS buffer từ 33KB xuống 3KB (`setBufferSizes(2048, 1024)`) + giảm I2S DMA buffer từ 24 xuống 12 (giải phóng 54KB RAM cho SSL Handshake) | `NetworkManager.cpp`, `config.h` | ❌ **SAI HẲN — đã chốt 2026-09-03**: I2S DMA buffer 12 thì đúng (`config.h: AUDIO_DMA_BUF_COUNT = 12`), nhưng phần `setBufferSizes(2048,1024)` **KHÔNG THỂ đúng**: grep source Arduino core 2.0.17 (`~/.platformio/packages/framework-arduinoespressif32/libraries/WiFiClientSecure/src/`) cho thấy **`setBufferSizes()` KHÔNG TỒN TẠI trong `WiFiClientSecure` của ESP32** — đó là API của **ESP8266**. Nghĩa là không phải "quên áp dụng" mà là **bất khả thi trên nền tảng này**; nếu từng viết vào code thì đã không compile được. → mbedTLS trên ESP32 luôn dùng in/out content buffer mặc định 16KB mỗi chiều, không chỉnh được từ tầng Arduino. **Đừng đào lại hướng này.** Giữ nguyên dòng gốc bên trái để không xoá lịch sử. |

#### Defect gốc đã tìm ra ở vòng lặp tải (nguyên nhân treo tại `[NET] writing slot`)
`http.getSize()` trả `-1` với response chunked. Điều kiện `while (http.connected() && (len > 0 || len == -1))`
khi đó **không bao giờ tự sai** — chỉ thoát khi server đóng socket. Stream nửa-mở treo vĩnh viễn.
`http.setTimeout(30000)` chỉ chốt **một lần đọc**, không chốt được cả vòng lặp. Khi timeout mới bắn,
phải set `writeError = true` để slot dở bị loại, nếu không file tải dở với `initialLen <= 0` vẫn lọt
qua bước kiểm tra và thành slot rác.

#### Nguyên nhân gốc đã xác nhận của tiếng "rẹt rẹt" rời rạc (ĐÃ FIX 2026-09-02)
**Bug phần mềm trong `AudioPlayer::fillChunk()`**: `AUDIO_OVERSAMPLE = 4` được cấu hình đúng —
I2S init ở `8000 * 4 = 32000Hz`, buffer `_stereo` cấp size cho oversample — nhưng code thực tế
**chỉ expand Mono→Stereo (x2), KHÔNG lặp mỗi mẫu 4 lần**. Hậu quả:
- I2S ở 32kHz ăn data nhanh gấp 4 → audio phát nhanh + hết sớm
- DMA auto-clear phát silence xen kẽ giữa các chunk → tiếng rẹt rời rạc đồng pha với NAND CS
- `loadFromStorage()` gọi `i2s_set_sample_rates(sampleRate)` thiếu nhân OVERSAMPLE → khi WAV
  header có rate khác default, BCLK rớt thấp gây rè liên tục

**Fix đã áp dụng và kiểm chứng thành công trên máy thật (2026-09-02):**
1. `fillChunk()`: thêm vòng lặp `for (r = 0; r < AUDIO_OVERSAMPLE; r++)` lặp mỗi mẫu mono,
   sửa `i2s_write` ghi `samples * OVERSAMPLE * 4` bytes, sửa `_audioCursor` chia `OVERSAMPLE * 2`.
2. `loadFromStorage()`: sửa `i2s_set_sample_rates(I2S_NUM_0, sampleRate * AUDIO_OVERSAMPLE)`.

Build: RAM 23.6% (77KB), Flash 73.3% (1.35MB). Kết quả: **tiếng rẹt boot + rẹt lúc phát đều
biến mất hoàn toàn**. Chỉ còn nháy màn hình rất nhẹ do sụt áp phần cứng (xem mục dưới).

#### Lỗi còn lại: Nháy màn hình nhẹ khi loa phát (sụt áp phần cứng — P1)
- **Triệu chứng**: Đèn nền LCD nháy rất nhẹ đồng pha với âm thanh loa. Không ảnh hưởng trải
  nghiệm nghe, chỉ thấy nếu nhìn kỹ.
- **Nguyên nhân**: MAX98357A và LED backlight dùng chung rail 3.3V. Đỉnh dòng ampli kéo rail
  sụt tạm thời → LED tối đi.
- **Không phải lỗi phần mềm** — firmware đã tối ưu (FRAME_MIN_IDLE_MS=2ms, frame skip).
- **Fix phần cứng cho PCB thật**: Tụ bypass 100uF sát VCC MAX98357A, ferrite bead tách rail
  audio, hoặc LDO riêng cho ampli.

#### Chốt trạng thái 2026-09-02 (user xác nhận trên máy thật)
- ✅ **Wi-Fi AP + captive portal: ĐÃ ỔN.**
- ✅ **Tải file (video + audio) về NAND: ĐÃ ỔN.**
- ✅ **Tiếng rẹt rẹt lúc boot (testBeep): ĐÃ FIX** (delay(200) trước stop + oversample fix).
- ✅ **Tiếng rẹt rẹt lúc phát message: ĐÃ FIX** (fillChunk oversample x4 + loadFromStorage rate fix).
- ⚠️ **Nháy màn hình rất nhẹ khi loa phát**: Vấn đề phần cứng (sụt áp rail chung). Chấp nhận
  được trên prototype. Sẽ fix trên PCB thật bằng tụ bypass / LDO riêng.

#### Các giả thuyết đã loại bỏ (lưu lại để không đào lại)
- ~~"8kHz ra thẳng MAX98357A gây rè"~~ — Bác bỏ: rẹt rời rạc chứ không rè liên tục.
- ~~"Brownout reset loop"~~ — Không xảy ra: `esp_reset_reason()` chỉ in 1 lần.
- ~~"Chân I2S đảo ngược"~~ — Không ảnh hưởng: audio phát đúng sau fix oversample.
- ~~"DMA underrun"~~ — Đúng là underrun nhưng do bug oversample, không phải do DMA quá nông.

#### Quyết định đã CHỐT — không mở lại
- **Giữ 8kHz** cho audio. User chốt: "tôi sẽ giữ nguyên 8khz".
- **KHÔNG giảm độ sáng đèn nền.** User bác thẳng; `MediaPlayer.cpp` giữ `BACKLIGHT_DAY_PERCENT`.
- **Decode video/audio phải chạy ở client**, không đẩy sang backend.
- **Oversample x4** giữ nguyên (`AUDIO_OVERSAMPLE = 4`), đã chứng minh fix triệt để rẹt.
- **Session Rule (2026-09-02)**: Agent **KHÔNG** tự chạy lệnh build PlatformIO (`pio run`) để tiết kiệm thời gian, việc build và flash máy thật do User đảm nhiệm. Agent chỉ tập trung nghiên cứu, rà soát logic và viết code.

---

## 7. TÌNH TRẠNG CODE & PHẦN ĐÃ MẤT (kiểm kê 2026-09-01)

### Code cũ đã mất — TÌM LẠI ĐƯỢC trong git stash
Bản backup mà user tưởng đã mất **vẫn còn**, nằm trong `stash@{1}` (tên "trrr"), ở đường dẫn
`sendlove_firmware/.backup_audio_debug/20260816_004737/`. Thư mục này **không còn trên đĩa** —
chỉ tồn tại trong stash. Gồm 6 file, mốc 2026-08-16 00:47:37:

| File | Số dòng |
|---|---|
| `AudioPlayer.cpp` | 147 |
| `AudioPlayer.h` | 60 |
| `MediaPlayer.cpp` | 371 |
| `NandStorage.cpp` | 350 |
| `NandStorageProvider.cpp` | 293 |
| `NetworkManager.cpp` | 853 |

Đây nhiều khả năng chính là bản "phát âm thanh mượt, hình ra chậm nhưng không nháy" mà user nhắc
đi nhắc lại — thứ đáng đối chiếu để hiểu vì sao bản cũ không bị sụt áp.

Lấy ra **không phá working tree hiện tại** (stash này có 2 parent nên đọc thẳng, không cần `^3`):

```
git show "stash@{1}:sendlove_firmware/.backup_audio_debug/20260816_004737/MediaPlayer.cpp" > /nơi/nào/đó.cpp
```

`stash@{1}` còn chứa `STATUS.md` ghi lại một task sửa `writeChunk` **bị chặn giữa chừng** vì xung
đột quyền khi gọi `agy` headless — kế hoạch sửa còn dang dở, chưa áp dụng.

### `stash@{0}` ("big stash")
28 file, ≈1015 thêm / 587 xóa. Danh sách file **trùng khớp với working tree bẩn hiện tại**
(MEMORY.md, platformio.ini, 11 file web, `VoiceInput.css` bị xóa...). Gần như chắc chắn là ảnh
chụp của chính trạng thái đang làm dở, **không phải** code mất. Đừng pop bừa — sẽ đụng độ.

### Ba nhánh local `ff`, `phong-tuyet-vong`, `pjhonggg`
Đều là **tổ tiên của `main`**, không chứa `AudioPlayer.cpp`. Không có gì để cứu ở đây.

### Chỗ tài liệu này đang sai / thiếu so với code thật
- §4 viết "`NandStorage` chỉ thực hiện Read-Only" — **sai từ Phase 3B**, module đã có
  `eraseSector`, `writeRaw`, `writeSlotTable`.
- §2 không nhắc gì tới ampli I2S / MAX98357A; §3 thiếu `AudioPlayer` và `ScreenLogger`.
  (Đã bổ sung ở Phase 3E bên trên.)

### Rác cần dọn
- `sendlove_firmware/src/main.cpp.bak` — file thừa.
- Working tree bẩn: 11 file web + `platformio.ini` + `MEMORY.md`, cùng các thư mục chưa track
  (`DRAFT/`, `sendlove_web/src/components/ui/`, `src/styles/`, `sendlove-box-style-guide.md`,
  `FE_DESIGN.md`, `HANDOFF.md`, `MULTI_PLATFORM_STRATEGY.md`, `firebase-debug.log`).
  **Chưa quyết** giữ / commit / bỏ.

### Ràng buộc bảo mật (không được vi phạm)
Không push, không tạo PR — chỉ làm local. Ba file bí mật không bao giờ commit (đã có trong
`.gitignore`): `sendlove_firmware/include/config_secrets.h`, `sendlove_web/.env`,
`sendlove_backend/serviceAccountKey.json`.

---

## 8. PHASE 3F — Kiến trúc Đồng bộ Tối ưu RAM, Triệt tiêu Lỗi (-1) & Hết Giật Audio (2026-09-02)

### Bối cảnh & Bản chất gốc rễ của 2 lỗi tương hỗ

1. **Lỗi Firebase Sync (-1) (Out of Memory cho MbedTLS)**:
   - `WiFiClientSecure` cần ~35KB-40KB heap động liên tục để thực hiện SSL Handshake với Firebase.
   - Khi `_jpegBuffer` (48KB) bị ghim cố định trong RAM, cùng với I2S DMA (24KB hoặc 48KB) và task stacks (38KB), tổng RAM bị chiếm giữ vĩnh viễn là >180KB trên tổng 200KB heap khả dụng của ESP32-C3.
   - Heap chỉ còn ~16KB-30KB bị phân mảnh -> MbedTLS handshake thất bại -> `http.GET()` trả về `-1`.

2. **Lỗi Video Delay & Âm thanh nhảy cóc**:
   - `AUDIO_PCM_CHUNK_SIZE = 1600` (12.8KB stereo). Trong khi I2S DMA mỗi 10ms chỉ tiêu thụ 1.28KB (160 bytes mono input).
   - `fillChunk()` đọc 1600B từ NAND qua SPI nhưng `i2s_write` chỉ nhận 160B rồi vứt 1440B còn lại.
   - Mỗi giây đọc SPI NAND **100 lần** (160KB/s thay vì 16KB/s), chiếm `_spiMutex` liên tục khiến `MediaPlayer` bị nghẽn SPI khi render JPEG lên ST7789 display.

### Giải pháp Kiến trúc Đã Áp dụng

1. **Cân chỉnh Chunk Size vừa khít 1 DMA Buffer**:
   - `AUDIO_PCM_CHUNK_SIZE = 256` bytes (128 mono samples = 16ms @ 8kHz).
   - Khi oversample x4 stereo: 128 * 4 * 4 bytes = **2048 bytes = ĐÚNG 1 DMA BUFFER** (`AUDIO_DMA_BUF_LEN = 512` samples).
   - Tiết kiệm **12.1KB** static RAM trong `AudioPlayer` (buffer `_stereo` giảm từ 12.8KB xuống 2.0KB).
   - Đọc NAND cực nhanh (100 µs), không đọc thừa 1 byte nào, không tranh chấp SPI bus.

2. **Đồng bộ Audio Tick Trước & Sau Mỗi Frame (Loại bỏ Audio Task riêng)**:
   - Trong `MediaPlayer::update()`: gọi `_audio.tick()` trước khi decode JPEG (đảm bảo DMA đầy 192ms) và ngay sau khi decode/push image (bù ngay lượng vừa phát trong lúc decode).
   - Với DMA 192ms và thời gian decode mỗi frame ~40-60ms, DMA luôn duy trì mức >130ms, **không bao giờ bị underrun hay nhảy cóc**.
   - Loại bỏ task `AudioTick` riêng giúp tiết kiệm **2KB** stack và loại bỏ 100% xung đột mutex giữa 2 task.

3. **Thu gọn Task Stacks & Buffer On-Demand**:
   - `TASK_STACK_MEDIA_PLAYER = 6144`, `TASK_STACK_NETWORK = 6144`, `TASK_STACK_UI_CONTROLLER = 4096` -> tiết kiệm thêm **8KB** heap.
   - `_jpegBuffer` giảm từ 48KB xuống **32KB** (đủ cho 100% video/ảnh JPEG 240x240 và SLBX chunked).
   - `_jpegBuffer` cấp phát khi `playItem()` (có retry 100ms yield cho IDLE task) và giải phóng ngay trong `stop()`.
   - Trong `STATE_STANDBY`, **Free Heap đạt ~120KB - 140KB**, MbedTLS SSL Handshake chạy mượt mà 100%, không bao giờ gặp lỗi (-1).

### Bảng cấu hình bộ nhớ đã chốt

| Thành phần | Kích thước | Vòng đời | Mục đích |
|---|---|---|---|
| `_jpegBuffer` | 32 KB | Malloc lúc play, Free lúc stop | Giải mã JPEG 240x240 / RGB565 |
| I2S DMA | 12 buffers × 512 × 4 = 24 KB | Cố định | Đệm âm thanh 192ms sâu và ổn định |
| Audio Chunk | 256B mono -> 2048B stereo | BSS (2.3KB) | Đúng 1 DMA buffer, đọc SPI 0.1ms |
| Heap tự do ở Standby | **~130 KB** | Luôn có sẵn | Đảm bảo TLS SSL Handshake thành công |

---

## 9. RISK REVIEW 2026-09-02 (Memory leak / Race condition / Resource leak / Bảo mật)

Đánh giá đọc toàn bộ firmware, không sửa code. Đối chiếu với `codebase_review.md` (báo cáo cũ
đã có sẵn trong repo) — mục nào đã fix thì ghi rõ, mục nào còn nguyên thì giữ nguyên độ ưu tiên.

### Mới phát hiện, chưa có trong `codebase_review.md`

1. **🔴 Regression tiềm ẩn: `_jpegBuffer` quay lại malloc/free theo từng lần playItem/stop**
   (`MediaPlayer.cpp` staged diff hiện tại, `init()`/`playItem()`/`stop()`). Đây CHÍNH LÀ pattern
   mà §8 Phase 3E ghi nhận từng gây **reboot khi Long Press → Short Press liên tiếp** (đã fix bằng
   cách cấp phát 1 lần lúc `init()`, không free trong `stop()`). Phase 3F (vì lý do RAM cho TLS)
   đã đảo ngược lại đúng pattern đó. Long Press (3s) rồi Short Press ngay sau (theo
   `UIController::getTouchEvent()`) gọi `stop()` rồi `playItem()` liên tiếp trong cùng 1 tick —
   free() rồi malloc() lại 32KB ngay lập tức, đúng kịch bản đã từng gây crash. **Chưa kiểm chứng
   lại trên máy thật sau Phase 3F** — cần test kỹ đúng thao tác Long→Short trước khi tin tưởng.
2. **🔴 `client.setInsecure()` ở cả 5 chỗ gọi Firebase REST** (`NetworkManager.cpp:521,547,584,603,664`).
   Không xác thực chứng chỉ TLS → MITM có thể giả mạo `FIREBASE_HOST`, đọc/giả `FIREBASE_AUTH_SECRET`
   (gửi dạng query param `?auth=...`) và tin nhắn media. Vì auth secret là static bearer token nhúng
   cứng trong firmware, lộ 1 lần là lộ vĩnh viễn cho tới khi đổi secret.
3. **⚠️ MEMORY.md ghi sai** (đã đánh dấu ở §8): `setBufferSizes(2048, 1024)` được ghi là ✅ đã áp
   dụng nhưng **không tồn tại trong `NetworkManager.cpp`**. Nếu lỗi Firebase (-1) tái xuất hiện, đây
   là nghi phạm đầu tiên cần xét lại, không phải NAND/audio.
4. **⚠️ Dùng chung 1 `WiFiClientSecure client` cho 2 phiên `HTTPClient` lồng nhau** (video `http` +
   audio `httpAudio` trong `checkAndDownloadNewMessages`, `NetworkManager.cpp:881-1057`): `http.end()`
   của phiên video chỉ gọi SAU khi tải audio xong, trong khi `httpAudio.begin(client, ...)` đã mở một
   phiên GET khác trên cùng object `client` khi `http` còn "sống". Chưa quan sát được crash nhưng đây
   là chia sẻ resource không rõ ràng, dễ vỡ nếu WiFiClientSecure không tolerant việc này.
5. **⚠️ Tái sử dụng `String` trong toàn bộ luồng Firebase** (`NetworkManager.cpp`: `String payload`,
   `String rawMediaUrl`, `fullUrl.replace(...)`, `jsonEscape()`...) — mâu thuẫn trực tiếp với quyết
   định Phase 2.5 "loại bỏ hoàn toàn String... triệt tiêu rò rỉ RAM/phân mảnh heap". Đây đúng là
   luồng chạy trên background task ngay trước lúc cần heap sạch cho TLS handshake (lý do Phase 3F
   tồn tại). Nhiều `String` concatenation nhỏ mỗi chu kỳ sync là nguồn phân mảnh heap hợp lý nhất
   để nghi ngờ nếu OOM còn tái diễn.
6. **⚠️ Data race đọc-sửa-ghi `_numOfNewMsg`**: `checkAndDownloadNewMessages()` (task nền `WakeSync`)
   ghi đè `_numOfNewMsg = unreadInMem + newCloudMsg` trong khi `Task_MediaPlayer` gọi
   `decrementNewMsgCount()` (`_numOfNewMsg--`) khi người dùng bấm chuyển tin. Biến có `volatile`
   nên không bị compiler cache, nhưng phép `--` không atomic — nếu 2 task chạm cùng lúc có thể mất
   1 lượt đếm. Rủi ro thấp (cửa sổ trùng thời điểm hiếm) nhưng vẫn là race thật.
7. **⚠️ Task stack vừa giảm (staged diff `config.h`)**: `TASK_STACK_UI_CONTROLLER` 8192→4096,
   `TASK_STACK_MEDIA_PLAYER` 8192→6144. Chưa thấy bằng chứng đã test stack watermark thực tế
   (`uxTaskGetStackHighWaterMark`) sau khi giảm — JPEGDEC decode và WebServer callback trong
   `Task_UIController`/`Task_NetworkController` đều có thể ăn stack sâu hơn ước tính. Theo Session
   Rule §8, Agent không tự build — nên đây là việc cần User verify trên máy thật, không phải
   assumption an toàn.
8. **⚠️ `DEFAULT_WIFI_SSID`/`DEFAULT_WIFI_PASSWORD` (`include/config.h:83-84`) là Wi-Fi nhà thật, đã
   nằm trong git log từ commit `a5970fc` (rất lâu trước 6 commit local hiện tại) — nhiều khả năng
   **đã nằm trên origin** (repo ahead 6 commits, nghĩa là các commit cũ hơn đã push). Cân nhắc đổi
   mật khẩu Wi-Fi thật hoặc dọn khỏi lịch sử git nếu origin là remote chia sẻ.

### Từ `codebase_review.md` — đối chiếu lại, vẫn còn nguyên (chưa fix)

- **3.1 Nguy cơ tự-deadlock `_spiMutex` non-recursive**: vẫn còn — `main.cpp` tạo
  `xSemaphoreCreateMutex()` (không đệ quy), và `MediaPlayer::decodeOneFrame()` vẫn gọi
  `DLOG("[PLAY] ERR: openRAM")` (`MediaPlayer.cpp:421`) ngay TRONG khối đã `acquireSPI()`
  (dòng 408-424). `ScreenLogger::render()` timeout 50ms nên không treo vĩnh viễn, nhưng vẫn
  gây đúng 50ms nghẽn Task_MediaPlayer mỗi lần rơi vào nhánh lỗi này.
- **4.5 `NandStorage::formatAll()` poll `waitBusyInternal()` không yield**: vẫn còn nguyên,
  Chip Erase 16MB (20-80s) có thể đụng Task Watchdog.
- **4.1 `FirebaseClient.*` dead code**: vẫn còn, chưa xoá (không sao vì không ảnh hưởng runtime).
- **5.1 OTA `/api/ota/*` không xác thực**: vẫn còn nguyên, port 80 mở công khai khi có Wi-Fi.
- **5.2 Wi-Fi mặc định hardcode**: vẫn còn (xem mục 8 ở trên, đã bổ sung thêm ý git history).
- **5.3 Bucket Firebase Storage hardcode**: vẫn còn (`NetworkManager.cpp` các đoạn build
  `firebasestorage.googleapis.com/v0/b/iot-app-839a2...`).

### Đã tự fix từ khi viết `codebase_review.md` (không cần làm lại)

- **3.4 Audio `fillChunk()` drop sample không theo dõi `written`**: ĐÃ FIX — bản hiện tại ghi cả
  chunk 1 lần bằng `i2s_write(..., &written, 0)` và cộng dồn `_audioCursor` đúng theo `written`
  thực tế (`AudioPlayer.cpp:216-227`).
- **2.2 `_isNtpSyncing` treo vĩnh viễn nếu `xTaskCreate` fail**: bug logic vẫn còn trong
  `triggerNtpSync()` (`NetworkManager.cpp:172-176`, không kiểm tra `pdPASS`), NHƯNG hàm này
  giờ là **dead code** — chỉ còn gọi từ `src/main.cpp.bak`, `main.cpp` thật đã chuyển hết sang
  `triggerWakeupSync()` (có kiểm tra `pdPASS` đầy đủ, `NetworkManager.cpp:459-464`). Hạ độ ưu
  tiên xuống thấp, chỉ là bom nổ chậm nếu sau này có ai gọi lại `triggerNtpSync()`.
- **4.4 lỗi chính tả "Sar"**: ĐÃ FIX, code hiện tại đúng `"Sat"` (`NetworkManager.cpp:217`).
- **3.2 SDCardManager thiếu NOP Hack**: không ảnh hưởng hiện tại vì `ACTIVE_STORAGE_TYPE` đang
  set NAND (`config.h:110`), nhưng nếu tương lai chuyển sang SD thì bug này vẫn còn nguyên, chưa
  verify lại.

### Quyết định đã CHỐT sau review (2026-09-02, bổ sung)

- **Bỏ hẳn "có tin local thì hoãn sync"**: User xác nhận logic này *không hợp lý* — 2 chỗ trong
  `Task_UIController` (`main.cpp`) từng skip trigger sync ngầm khi `storage->hasUnreadMessage()`
  đã true (1 lần ở post-wakeup sync, 1 lần ở periodic 10s check), với lý do cũ là nhường CPU/SPI
  cho Short Press phát ngay. Đã xoá cả 2 nhánh — giờ chỉ còn điều kiện `isFull()` mới skip sync.
  Quay lại nguyên tắc: luôn check tin mới trên Cloud + tải đầy đủ vào slot, không có tin local nào
  được coi là "đủ mới" để hoãn việc kiểm tra Cloud. **Chưa test lại trên máy thật.**

### Bug thật đã tìm ra và fix (2026-09-02): slot dở do download stall bị công nhận nhầm là "tin hợp lệ"

**Triệu chứng user báo**: 1 message video 2.21MB (15s, 225 frame @15fps) + voice 240KB luôn tải
dừng ở ~20% rồi timeout. Mở slot vẫn phát được vài giây đầu (không tiếng) rồi lỗi `Bad jpegSize`.
Tin nhắn không được đánh dấu đã tải (`ts fail`). Một message khác nhỏ hơn (1.68MB/10s, 151 frame,
voice 161KB) tải/đọc bình thường.

**Đối chiếu 2 file .bin gốc bằng hex dump** (`SLBX` header offset 0-19 trong file gốc, tương ứng
offset 4-23 sau khi firmware chèn 4 byte size ở đầu slot): cấu trúc header, `mediaType`, `w/h=240`,
`fps=15`, `totalFrames` (225 vs 151) đều đúng chuẩn và giống hệt về layout giữa 2 file — **web
convert/encode KHÔNG có lỗi**, chỉ khác nhau về độ dài (message lỗi dài đúng 15s = trần cắt của
web, nên file lớn hơn, tải lâu hơn).

**Root cause thật (bug ở box, không phải ở web)**: `checkAndDownloadNewMessages()`
(`NetworkManager.cpp`) gọi `storage->closeWrite(maxDisplayTime)` **VÔ ĐIỀU KIỆN** sau vòng lặp tải,
kể cả khi `writeError = true` (do `DOWNLOAD_STALL_TIMEOUT_MS = 10000` bắn lên giữa chừng ở file
lớn). `NandStorageProvider::closeWrite()` luôn ghi bảng slot + set bit `unread` bất kể dữ liệu có
đủ hay không — vì 20 byte đầu (SLBX header + `totalFrames=225`) đã tới nơi trước lúc stall, header
check nhận diện đúng "VJPG", box tưởng slot hợp lệ và cho phát. Phát tới đúng điểm dữ liệu bị cụt
(~20%) thì đọc trúng vùng NAND đã erase nhưng chưa từng ghi (toàn `0xFF`) → `jpegSize` đọc ra rác
→ `Bad jpegSize`. Audio không có tiếng vì nhánh tải voice nằm TRONG khối `if (!writeError...)` nên
bị bỏ qua hoàn toàn khi video đã lỗi. Vì `messageSuccess = false`, code `break` vòng lặp tin nhắn
và không cập nhật `last_download_ts` (đúng như log "ts fail" user thấy) — nhưng slot vật lý **đã bị
đánh dấu unread với dữ liệu rác**, ngồi chình ình chiếm 1 trong 5 slot.

**Fix đã áp dụng**:
1. Thêm `IStorageProvider::discardWrite()` (mặc định no-op) — huỷ phiên ghi dở dang, KHÔNG commit
   bảng slot, KHÔNG set bit unread (`lib/Storage/IStorageProvider.h`).
2. `NandStorageProvider::discardWrite()`: xoá magic slot vừa erase-dở (để `isSlotValid()` không
   nhận nhầm), ghi lại slot table, **không đụng `_writeSlotIndex`** — lần sync sau sẽ retry đúng
   slot này thay vì đốt thêm 1 slot mới mỗi lần fail (`lib/Storage/NandStorageProvider.cpp`).
3. `NetworkManager::checkAndDownloadNewMessages()`: tính `downloadComplete` TRƯỚC, gọi
   `closeWrite()` khi thành công / `discardWrite()` khi lỗi, thay vì `closeWrite()` vô điều kiện
   (`NetworkManager.cpp` ~dòng 940-957).

**Chưa fix, ghi lại để không quên**: nhánh tải audio lồng bên trong (dòng ~1014-1017,
`while (!aWriteError && httpAudio.connected() ...)`) khi stall chỉ `break` mà KHÔNG set
`aWriteError = true`, log vẫn in "Audio DL OK". Ít nghiêm trọng hơn (video đã hợp lệ, `closeAppend()`
vẫn tính đúng `audioSize` theo số byte thực ghi nên không lộ dữ liệu rác — chỉ là tiếng bị cắt cụt
mà log báo nhầm "OK") — chưa sửa vì không phải nguyên nhân bug user báo lần này.

**Nghi vấn còn treo (nguyên nhân TẠI SAO stall xảy ra ở file lớn)**: có thể liên quan tới việc
`setBufferSizes(2048,1024)` cho mbedTLS **chưa thực sự có trong code** dù MEMORY.md từng ghi ✅
(xem mục sai đã đánh dấu ở Phase 3F, bảng cấu hình bộ nhớ). File càng lớn thì thời gian giữ kết nối
TLS càng lâu, càng dễ va phải heap fragmentation/RSSI kém. Nếu áp `setBufferSizes` thật vào code mà
vẫn stall thì mới nên nghi ngờ tầng khác (Firebase Storage CDN, router).

**✅ ĐÃ KIỂM CHỨNG MÁY THẬT 2026-09-02**: User xác nhận tải lại được bình thường (đúng message
2.21MB/240KB từng bị stall) sau fix `discardWrite()`. Tạm chốt là ĐÃ FIX. Chưa rõ do fix
`discardWrite()` (giải phóng đúng slot để retry sạch thay vì kẹt slot rác) hay do stall gốc chỉ là
nhất thời (Wi-Fi/CDN) — không set lại `setBufferSizes()` lần này, chỉ ghi lại làm nghi vấn dự phòng
nếu hiện tượng stall tái diễn với file lớn khác.

### Text đi kèm message — ĐÃ LÀM (2026-09-02, đảo ngược quyết định "hoãn" ở trên)

User quay lại yêu cầu làm ngay (không hoãn nữa), với điều kiện: **tạm thời bỏ dấu tiếng Việt**
(ASCII-fold) vì font `ChakraPetch_*.h` xác nhận chỉ có glyph ASCII 32-126 (đọc trực tiếp struct
`GFXfont` trong file, `first=32,last=126`) — không đủ cho tiếng Việt có dấu, và chưa có word-wrap ở
đâu trong codebase. Đồng thời user yêu cầu gộp luôn ảnh + text + "nhạc nền" (voice đổi vai trò) thành
1 loại "tin nhắn tĩnh", và thêm 1 card mới trên web sender — **không tạo `type` enum mới ở backend**,
tái dùng `type: "image"` có sẵn (message schema đã phẳng, field nào cũng optional trên mọi `type`).

**Đã code xong cả 3 tầng, CHƯA build/test trên máy thật** (theo Session Rule, Agent không tự chạy
`pio run`; web/backend cũng chưa tự build/deploy — chỉ sửa source).

#### Tầng Backend (`sendlove_backend`)
- Phát hiện quan trọng: `bg_music_url`/upload config `bg_music` **đã có sẵn từ trước** (scaffold cũ,
  không phải do phiên này thêm) — nhưng cấu hình sai định dạng `bgmusic.mp3`/`audio/mpeg` trong khi
  firmware chỉ decode được WAV/PCM (không có decoder MP3, không khả thi nhét vào ESP32-C3). Đã sửa
  `message.service.ts` (+ bản compiled `.js`) đổi 3 chỗ: `typeMap.bg_music`, URL construction, fileMap
  — tất cả từ `bgmusic.mp3`/`audio/mpeg` sang `bgmusic.wav`/`audio/wav`. Không đổi `type` enum.

#### Tầng Web (`sendlove_web`)
- `SenderUI.jsx`: thêm card `static` vào `TYPES`/`STEP2_TITLE` (UI-key nội bộ, KHÔNG phải giá trị gửi
  backend). Bước 2 mới: `ImageInput` (tuỳ chọn, giữ tạm blob qua state `staticImageBlob` thay vì upload
  ngay) + textarea dùng chung state `text` sẵn có + `VoiceInput` (tuỳ chọn, giữ tạm qua
  `staticAudioData`, đóng vai "nhạc nền"). `processAndUpload()` nhánh `static` mới: ép cứng
  `payload.type = 'image'`, bồi `binBlob`/`thumbBlob` (nếu có ảnh, tái dùng `encodeImageToBin` y hệt
  card ảnh) + `bgMusicBlob` (field MỚI, khác `voiceBlob`). `handleCancel()` giờ cũng clear `text` +
  2 state mới — tiện thể fix luôn bug nhỏ đã phát hiện trước đó ("text không bị xoá khi đổi mode").
- `EncodingProgress.jsx`: thêm `static` vào `TYPE_ICON`/`TYPE_LABEL`.
- `mediaUploader.js`: thêm 1 dòng `if (data.bgMusicBlob) blobsToUpload.push({type:'bg_music',...})`
  song song dòng `voiceBlob` có sẵn — không sửa gì khác (logic build request đã trung lập với `type`).

#### Tầng Firmware (`sendlove_firmware`)
- **`lib/NandStorage/NandStorage.h/.cpp`**: bump magic bảng slot `NSL2 → NSL3` (tiền lệ NSLT→NSL2).
  **Side effect đã biết trước**: lần boot đầu sau khi nạp, tin nhắn unread cũ trên máy bị xoá 1 lần.
  `SlotEntry` +`uint16_t textLen +char text[256]` (hằng số `SLOT_TEXT_MAX_LEN=256`, đủ ~7-8 dòng).
  Thêm `setSlotText()`/`getSlotText()` — set field-only (không `memset()` cả struct, giống pattern
  `setSlotAudioSize()`), cắt bớt an toàn tại ranh giới UTF-8 nếu text > 256 byte.
- **`lib/Storage/IStorageProvider.h`**: thêm `setItemText()`/`getItemText()` (mặc định no-op, SD Card
  chưa hỗ trợ). **`NandStorageProvider`**: implement 2 hàm trên; mở rộng `discardWrite()` (đã có từ
  lần fix video-stall trước) để **cũng xoá bit `_unreadBitmask` + lùi `_writeSlotIndex`** — cần vì
  đường ghi audio/text-only phải `closeWrite()` commit placeholder TRƯỚC (để `openForAppend()` tính
  đúng offset), rồi mới biết audio có tải được không; nếu lỗi phải undo được cả sau khi đã commit.
- **`lib/NetworkManager/NetworkManager.cpp`**:
  - Thêm `bg_music_url`/`bgMusicUrl` vào `voiceKeys[]` — tái dùng 100% cơ chế audio append có sẵn.
  - Parse `msg["text"]` lần đầu tiên (trước đây không đọc field này ở đâu cả).
  - Tách khối tải audio (từng inline trong nhánh ảnh/video) thành method riêng
    `downloadVoiceSegment()`, dùng chung cho nhánh ảnh/video (audio là phụ, lỗi không huỷ message) và
    nhánh mới "static không ảnh" (audio là nội dung chính, lỗi → `discardWrite()` huỷ cả message).
    Nhân tiện fix 1 bug có sẵn: audio bị stall trước đây không set `aWriteError=true` → log báo nhầm
    "OK" dù cụt tiếng.
  - Thêm nhánh `else if (rawVoiceUrl.length() > 0 || rawText.length() > 0)` xử lý message không có
    ảnh/video: mở slot rỗng (dataSize=4 sentinel) → tải audio (nếu có) → ghi text (nếu có).
- **`lib/MediaPlayer/MediaPlayer.cpp`**:
  - **Bug có sẵn phát hiện qua trace, đã fix**: `update()` trước đây chỉ tick audio khi
    `_state==PLAYING`; ảnh tĩnh dùng `_state=SHOWING` nên **combo ảnh+voice ĐANG câm tiếng** dù
    NetworkManager tải đúng. Thêm nhánh tick audio khi `SHOWING` — fix chung cho cả bug cũ lẫn
    voice-only/tin nhắn tĩnh mới.
  - `playItem()`: phát hiện sentinel "không ảnh thật" (`type==IMAGE && dataSize<=4`) → bỏ qua hoàn
    toàn dò header SLBX + `decodeOneFrame()` (tránh lỗi "Bad jpegSize: 0" + `delay(2000)` chặn màn
    hình), chỉ giữ màn đen (bản NAND; bản SD card để phase sau theo đúng ý user). Sau ảnh/màn đen: nếu
    có caption, gọi `asciiFoldVietnamese()` (bảng map Unicode tiếng Việt U+1EA0-1EF9 + Latin-1/Extended-A
    → ASCII gần nhất, hàm static mới trong file) rồi `_display->showWrappedText()`.
- **`lib/DisplayDriver/DisplayDriver.h/.cpp`**: thêm `showWrappedText()` — greedy word-wrap đo
  `textWidth()` từng từ bằng font `ChakraPetch_SemiBold_16` có sẵn, giới hạn số dòng vừa vùng hiển thị
  (dải dưới màn nếu có ảnh, gần trọn màn nếu không ảnh), dòng cuối thêm "..." nếu bị cắt.

#### Chưa làm / để phase sau (theo đúng phạm vi đã chốt)
- Font Unicode thật cho tiếng Việt có dấu (đang ASCII-fold tạm thời).
- Background mặc định cho bản SD card khi không có ảnh (bản NAND dùng màn đen).
- Audio-stall-not-marking-error trong nhánh audio lồng ảnh/video: đã fix (dùng chung
  `downloadVoiceSegment()` nên fix 1 chỗ áp dụng cho cả 2 đường).

### Fix: download liên tục fail/timeout ở ~10% — erase toàn slot NAND + nghẽn TCP (2026-09-02, phiên sau)

Sau khi nạp firmware có tính năng tin nhắn tĩnh ở trên, user báo download liên tục fail, đứng ở ~10%
rồi timeout. Điều tra bằng 2 nguồn độc lập (tự rà soát + Plan agent kiểm chứng thiết kế, và 1 agent
khác cung cấp `fix_download_timeout_plan.md` phân tích sâu cơ chế TCP) — đã tự verify mọi claim quan
trọng bằng grep trực tiếp trước khi tin dùng.

**Root cause A (chính, gây STALL)**: `NandStorageProvider::openForWrite()` erase NGUYÊN slot ~5.3MB
(`NAND_SLOT_ADDRS = {0x010000, 0x560000, 0xAB0000}`) — 15-25s block đồng bộ SAU khi `http.GET()` đã mở
socket nhưng TRƯỚC khi đọc byte nào. Cơ chế cụ thể: trong lúc đó buffer TCP/mbedTLS đầy → lwIP gửi TCP
Window=0 → CDN backoff (Persist Probe) → khi erase xong, đọc nốt phần buffer cũ (~10-20%, khớp đúng
triệu chứng) → hết buffer, CDN đang backoff → 10s sau chạm `DOWNLOAD_STALL_TIMEOUT_MS` → huỷ. Bug có
sẵn từ khi `NAND_SLOT_COUNT` đổi 5→3 (commit `a5970fc`, 31/08, trước phiên tính năng text/voice), làm
slot to lên; đường ghi "tin nhắn tĩnh" mới thêm khiến bug này bị chạm ở MỌI message (kể cả vài chục KB).

**Root cause B (cộng hưởng, đã verify bằng grep)**: `uint8_t buffer[256]` + `stream->readBytes()` +
`delay(1)` gọi VÔ ĐIỀU KIỆN mỗi vòng lặp tải (cả video lẫn audio) — ở `CONFIG_FREERTOS_HZ=100`
(tick 10ms), trần tốc độ tải chỉ còn ~20-25KB/s. Cộng thêm: không có `WiFi.setSleep(false)` nào trong
toàn bộ firmware (modem sleep mặc định bật suốt lúc tải); `http.end()` của phiên video chạy SAU
`downloadVoiceSegment()` thay vì trước — 2 `HTTPClient` dùng chung 1 `WiFiClientSecure` khi phiên cũ
chưa đóng.

**Fix đã áp dụng**:
1. `lib/Storage/NandStorageProvider.h/.cpp` — Erase-as-you-write: thêm `_erasedUpToAddr` (địa chỉ
   tuyệt đối). `openForWrite()` chỉ erase 1 block 64KB đầu thay vì nguyên slot. `writeChunk()` erase
   thêm block khi con trỏ ghi sắp chạm vùng chưa erase — **bất biến bắt buộc**: luôn erase từ
   `_erasedUpToAddr`, không bao giờ từ `_writeOffset` (tránh `eraseRange()` tự lùi sector đè dữ liệu
   đã ghi). `openForAppend()` tự tính lại `_erasedUpToAddr` từ `_writeOffset` (làm tròn lên bội 65536)
   thay vì dựa vào state cũ — tự chữa lành. `discardWrite()`/`formatStorage()` reset về 0.
2. `lib/NetworkManager/NetworkManager.cpp`:
   - Buffer đọc `256B → 2048B` ở cả 2 vòng lặp (video + `downloadVoiceSegment()`).
   - `delay(1)` giờ CÓ ĐIỀU KIỆN — chỉ khi `sizeAvail/av == 0` (không có data), không delay mỗi vòng.
   - `WiFi.setSleep(false)` quanh vòng lặp per-message download (bật lại `true` ngay sau vòng lặp —
     mọi lối thoát khỏi vòng lặp là `break`, không `return`, nên luôn chạy tới điểm bật lại).
   - `http.end()` cho phiên video gọi NGAY sau khi tải xong, TRƯỚC `downloadVoiceSegment()` (dòng cũ ở
     cuối khối vẫn giữ, gọi lần 2 vô hại).
   - `DOWNLOAD_STALL_TIMEOUT_MS`: `10000 → 30000` (lưới an toàn bổ sung, không phải fix chính).

**Chưa làm (out of scope, có lý do)**: `waitBusyInternal()` (`lib/NandStorage/NandStorage.cpp`) không
có `vTaskDelay()` — với erase block 64KB (~150-2000ms/lần) đã đủ ngắn, sửa thêm sẽ ảnh hưởng
`writeRaw()` page-program (hot path), rủi ro cao hơn lợi ích. Các mục bảo mật khác trong
`code_review_2_9_gemini_38.md` (setInsecure/TLS, OTA không xác thực, GPIO8/NAND-CS, sector 0 wear) —
không liên quan triệu chứng lần này, để riêng nếu user muốn xử lý.

**Chưa build/flash/test trên máy thật.** Cần user xác nhận: (1) `[NET] writing slot` xuất hiện dưới
0.5s sau `[NET] GET OK` thay vì 15-25s; (2) tiến độ tải chạy đều không khựng ~10%; (3) tin nhắn chỉ
voice/text (trước đây gần như luôn fail) giờ tải nhanh; (4) video+audio nối tiếp không mất/lệch dữ
liệu, không lỗi `Bad jpegSize`; (5) `uxTaskGetStackHighWaterMark()` của `WakeSync` sau vài lần tải để
xác nhận margin thực tế với buffer 2048B (lý thuyết tính đủ nhưng nên đo thật).

> **KẾT QUẢ THỰC TẾ (2026-09-03)**: vòng fix này **CHƯA đủ**. Triệu chứng ĐỔI chứ không hết — từ
> "luôn dừng ~10%" thành "dừng ở vị trí NGẪU NHIÊN (đôi khi 3000B, đôi khi nửa file)". Nguyên nhân
> thật nằm ở chỗ khác, xem mục kế tiếp. Các fix ở vòng này (erase-as-you-write, delay có điều kiện)
> **vẫn đúng và cần giữ** — chính chúng đã loại bỏ cú block 15-25s nên triệu chứng mới đổi dạng.

---

### Fix vòng 3 (2026-09-03): `Stream::readBytes()` trên WiFiClientSecure đọc TỪNG BYTE qua mbedTLS

**Dữ kiện quyết định từ user** (loại trừ gần hết giả thuyết cũ):
- **Cả 2 dòng log đều xuất hiện tuỳ lần**: `dl STALL` (kết nối còn sống, server ngừng gửi) VÀ
  `DL err (discarded)` (`http.connected()` thành false — kết nối đứt hẳn).
- **Cấp nguồn USB** → loại bỏ giả thuyết sụt áp/pin.
- **Box KHÔNG reboot** → loại bỏ brownout và Task-Watchdog panic.

**Root cause (verify trực tiếp trong source Arduino core 2.0.17 tại `~/.platformio/packages/`)**:
`stream->readBytes(buffer, 2048)` trên `WiFiClientSecure` đọc **từng byte một**:
1. `WiFiClientSecure`/`WiFiClient` **không override `readBytes()`** → rơi về `Stream::readBytes()`
   (`cores/esp32/Stream.cpp:41-53`) — vòng lặp `timedRead()` **1 byte/vòng**.
2. `Stream::timedRead()` (`Stream.cpp:31`) **busy-spin không nhường CPU**, `_timeout` = **30 giây**
   (`HTTPClient.cpp:1168` đặt `_client->setTimeout((_tcpTimeout+500)/1000)`).
3. `WiFiClientSecure::read()` 1 byte (`:187`) → `read(&data,1)` → **gọi `available()` MỖI LẦN**
   (`:213`) → `data_to_read()` (`ssl_client.cpp:353`) → `mbedtls_ssl_read(ctx,NULL,0)` +
   `mbedtls_ssl_get_bytes_avail()`, rồi mới `get_ssl_receive()` → `mbedtls_ssl_read(ctx,buf,1)`.

→ 1 chunk 2048B = **~4096 lời gọi mbedTLS**; file 2.2MB = **hơn 4 TRIỆU** trên CPU đơn nhân 160MHz.
Đúng bằng trần ~20-25KB/s → 2.2MB mất 100+ giây, phơi kết nối quá lâu.

**Giải thích được ĐÚNG CẢ HAI kiểu lỗi ở vị trí ngẫu nhiên** (điều mà mọi giả thuyết trước không làm được):
- `available()` gọi **`stop()`** ngay khi `data_to_read()` trả âm (`WiFiClientSecure.cpp:247-250`);
  `read(buf,size)` cũng `stop()` khi `get_ssl_receive()` âm (`:233-236`). Gọi 4 triệu lần thì chỉ cần
  **một** lỗi mbedTLS thoáng qua là kết nối bị giết → `DL err (discarded)` ở vị trí ngẫu nhiên.
- Khi buffer mbedTLS cạn giữa chunk, `read()` trả -1 → `timedRead()` **busy-spin tới 30 giây** đốt
  100% CPU, không rút socket, không cập nhật `lastProgressMs` → `dl STALL`.

**Sai lầm của vòng fix 2 (ghi lại để không lặp)**: tài liệu `fix_download_timeout_plan.md` (Giải pháp 2)
nêu **2 việc** — (a) nâng buffer 256→2048B, (b) **đổi `readBytes()` → `read()`**. Vòng 2 chỉ làm (a),
bỏ sót (b) — mà (b) mới là phần quan trọng. Nâng buffer mà vẫn `readBytes()` chỉ khiến mỗi chunk tốn
2048 vòng byte-by-byte thay vì 256, **không giải quyết gì**. Bài học: khi áp dụng khuyến nghị từ tài
liệu ngoài, phải làm ĐỦ các phần của khuyến nghị đó hoặc ghi rõ vì sao bỏ.

**Fix đã áp dụng vòng 3:**
1. `NetworkManager.cpp` — **`stream->readBytes()` → `stream->read()`** ở CẢ 2 vòng lặp tải (video
   ~dòng 1056 và `downloadVoiceSegment()` ~dòng 715). Đây là fix chính. Thêm log
   `[NET] conn DROPPED @ X/Y` khi thoát vòng lặp do `!http.connected()` (trước đây im lặng, phải suy
   ra từ `DL err` nên không phân biệt được "đứt kết nối" với "tải thiếu byte").
2. `NandStorage.cpp` — `writeRaw()` dùng **`SPI.writeBytes()` bulk** thay vòng `SPI.transfer()` từng
   byte, + hằng số mới **`NAND_WRITE_SPI_SETTINGS` 20MHz** riêng cho đường ghi (đường đọc đã chạy
   20MHz ổn định trên đúng bộ dây này; opcode `0x02` của W25Q128JV chịu tới 133MHz). Ghi 1 page 256B:
   ~900µs → ~120µs. **Tách hằng số riêng để revert 1 dòng** nếu breadboard không chịu nổi — dấu hiệu
   là dữ liệu tải về hỏng (ảnh nhiễu / `Bad jpegSize` / audio rè bất thường).
3. **Chặn "ghi thất bại nhưng báo thành công"** (bug thật, phát hiện khi rà soát): `writeRaw()`/
   `eraseRange()`/`eraseSector()` đổi `void` → `bool` (false khi `acquireSPI()` timeout 1000ms —
   trước đây return im lặng, KHÔNG ghi gì mà caller vẫn tưởng xong). `writeChunk()` giờ trả `0` khi
   thất bại thay vì luôn trả `len` → `NetworkManager` thấy `written < c` → `discardWrite()`.
   `writeSlotTable()` và `closeWrite()` cũng log lỗi thay vì nuốt. Nguy hiểm nhất là erase bị skip im
   lặng: NAND chỉ clear bit 1→0, ghi đè lên vùng chưa erase cho ra dữ liệu rác mà chip không báo lỗi.

**Ghi chú**: `lib/NetworkManager/FirebaseClient.cpp:89` cũng dùng `stream->readBytes()` với cùng bug,
nhưng module này là **dead code** (không được gọi ở đâu — đã xác nhận từ `codebase_review.md` §4.1),
nên không sửa. Nếu sau này hồi sinh module đó thì phải sửa cùng cách.

**Chưa build/flash/test trên máy thật.** Cần user xác nhận:
1. **Tốc độ tải** — dòng `[NET] dl X/Y` (in mỗi 16KB) phải chạy dồn dập, 2.2MB xong trong vài giây tới
   ~15s thay vì >100s. Đây là chỉ dấu trực tiếp nhất cho biết fix có trúng hay không.
2. Không còn `dl STALL` / `DL err (discarded)` giữa chừng. Nếu VẪN còn, dòng log mới
   `[NET] conn DROPPED @ X/Y` sẽ cho biết chính xác là kết nối đứt (→ bước tiếp: resume bằng HTTP
   `Range`) hay là ngừng nhận data (→ hướng khác).
3. Toàn vẹn dữ liệu sau khi nâng clock ghi 20MHz (xem dấu hiệu ở mục 2 phần fix).
4. Nếu xuất hiện `[NANDP] ERR: write failed` / `erase-ahead FAILED` → tranh chấp SPI mutex là có thật
   (trước đây bị nuốt im lặng nên chưa từng thấy), cần xử lý riêng.

**Chưa làm, để dành nếu vòng 3 vẫn chưa đủ**: resume/retry bằng HTTP `Range` header (phải phân biệt
206 vs 200, xử lý server không hỗ trợ Range) — chỉ nên làm khi đã có bằng chứng từ log
`conn DROPPED` rằng vấn đề là mạng chứ không phải firmware.

---

### Fix vòng 4 (2026-09-03): vấn đề THẬT nằm ở TẦNG KẾT NỐI, không phải luồng download

**User reframe (rất quan trọng, đổi hẳn hướng điều tra)** — 4 quan sát thực tế:
1. Wi-Fi kết nối chập chờn; ngủ rồi thức dậy có thể **mất luôn kết nối**.
2. Dùng Wi-Fi mặc định không được **dù SSID đúng**, phải nhập lại đúng Wi-Fi đó qua AP mode mới chạy.
3. **Wi-Fi đang báo đã connect nhưng `http.GET()` vẫn trả `-1`.**
4. **Những lúc tải được hẳn thì tải RẤT NHANH.**

Quan sát #4 xác nhận **fix vòng 3 (`readBytes`→`read`) ĐÃ có tác dụng** — đường download không còn là
nút thắt. Nút thắt còn lại là việc thiết lập/duy trì kết nối.

**Root cause (verify trực tiếp trong code, không suy đoán)**:

`NetworkManager::ensureConnected()` có fast-path `if (WiFi.status() == WL_CONNECTED) return true;`.
Sau Light Sleep **`WiFi.status()` RẤT HAY vẫn báo `WL_CONNECTED` dù association đã chết ở phía AP**:
CPU ngủ suốt 5 phút nên driver Wi-Fi không hề xử lý được beacon-loss / deauth event, biến trạng thái
giữ nguyên giá trị cũ. Tin vào nó → bỏ qua reconnect → mọi `http.GET()` sau đó trả `-1`
(**đúng y quan sát #3 của user**).

Tệ hơn — đây là vòng luẩn quẩn khiến box **không bao giờ tự thoát ra được**: sau timer wake box chỉ
thức **2 giây** (`activeSleepTimeoutMs = 2000` trong `main.cpp`), trong khi driver Wi-Fi cần ~6s+ mới
tự phát hiện mất beacon rồi `setAutoReconnect(true)` mới kích hoạt. Box ngủ lại **trước khi** stack kịp
nhận ra mình đã mất kết nối → lặp lại hàng trăm chu kỳ 5 phút → giải thích luôn quan sát #1.

Xác nhận thêm: `esp_light_sleep_start()` (`PowerManager::enterLightSleep`) được gọi khi Wi-Fi vẫn đang
active — **không** `esp_wifi_stop()`, **không** `esp_pm_configure()`, **không** cấu hình PS nào (grep
toàn repo: 0 kết quả). Đây là kiểu dùng light sleep mà ESP-IDF không đảm bảo giữ được association.

**Fix đã áp dụng:**
1. **`ensureConnected()` không còn tin `WiFi.status()`** (`NetworkManager.cpp`):
   - Fast-path giờ đòi **cả** `WL_CONNECTED` **lẫn** IP hợp lệ (`(uint32_t)WiFi.localIP() != 0`) —
     `WL_CONNECTED` chỉ nghĩa là associate+auth xong, chưa chắc đã xin được IP từ DHCP; gửi HTTP khi
     chưa có IP cũng ra `-1`.
   - Thêm cờ `_forceReassociate` + `notifyWakeFromSleep()`: **vừa ngủ dậy thì LUÔN tái lập
     association**, bỏ qua fast-path hoàn toàn. `main.cpp` gọi `notifyWakeFromSleep()` ngay sau
     `enterLightSleep()`.
   - Bỏ `WiFi.reconnect()` (dựa trên chính trạng thái driver đang sai) → luôn `WiFi.disconnect(false)`
     + `WiFi.begin()` sạch, và **chờ cả status lẫn IP** mới coi là thành công.
2. **Timeout `ensureConnected` trong `syncWakeup()`: 5s → 12s** — sau light sleep đây là associate +
   4-way handshake + DHCP hoàn toàn mới, thực tế tốn 3-8s; cắt ở 5s là bỏ dở đúng lúc sắp xong.
   Không tốn pin oan vì `Task_UIController` bị khoá không cho ngủ khi `isSyncing()`.
3. **Retry `-1` giờ có tái kết nối** (`checkAndDownloadNewMessages`): cách cũ chỉ `delay(500)` rồi
   `http.GET()` lại trên cùng client — vô ích khi nguyên nhân là link chết hoặc DNS cũ. Giờ ép
   `_forceReassociate` + `ensureConnected(12000)` trước khi thử lại (việc này cũng xin lại DNS server
   mới từ DHCP).
4. **Fallback creds mặc định** (quan sát #2, `main.cpp`): trước đây hễ NVS có **bất kỳ** SSID nào thì
   `DEFAULT_WIFI_SSID/PASSWORD` trong `config.h` **không bao giờ được thử tới** → box đi thẳng vào AP
   mode dù creds mặc định vẫn dùng được. Giờ NVS creds fail sẽ thử tiếp creds mặc định. Log cũng ghi
   rõ nguồn: `[BOOT] WiFi: <ssid> (NVS|default)` — trước chỉ in SSID nên không phân biệt được "đang
   dùng creds mặc định" với "đang dùng creds cũ còn sót trong NVS".
5. **Log chẩn đoán heap**: `[NET] sync start heap=N` đầu mỗi chu trình sync + heap in kèm khi GET fail
   — để lần sau phân biệt được OOM với lỗi đường truyền (xem mục `setBufferSizes` bất khả thi ở trên).

**Giả thuyết còn lại cho quan sát #2 mà code không sửa được**: có thể **mật khẩu router đã đổi** trong
khi `DEFAULT_WIFI_PASSWORD` trong `config.h` vẫn là giá trị cũ (`config.h:83-84`). User nói "SSID đúng"
chứ không khẳng định mật khẩu. Log mới `[BOOT] WiFi: ... (NVS|default)` sẽ giúp xác định.

**Chưa làm, cân nhắc nếu vòng 4 vẫn chưa đủ**: tắt hẳn Wi-Fi trước khi ngủ
(`esp_wifi_stop()` / `WiFi.mode(WIFI_OFF)`) rồi bật lại sau khi thức, thay vì dựa vào modem sleep giữ
association. §6.B.3 từng tính modem sleep tiết kiệm hơn 28% ở chu kỳ 5 phút — **nhưng phép tính đó giả
định association SỐNG SÓT qua giấc ngủ, mà thực tế cho thấy giả định này sai**. Nếu vòng 4 cho thấy
association chết ở gần như mọi lần wake (xem log `[NET] re-assoc`), thì tắt hẳn Wi-Fi khi ngủ sẽ vừa
đúng hơn vừa tiết kiệm hơn (không tốn 0.4mA rò trong 5 phút cho một association đằng nào cũng chết).

**Chưa build/flash/test.** Cần user xác nhận qua log:
- `[NET] re-assoc (wake=1 st=3)` — `st=3` (WL_CONNECTED) mà vẫn phải re-assoc ⇒ **xác nhận đúng chẩn
  đoán**: status đã nói dối. Đây là dòng log đáng chú ý nhất.
- `[NET] WiFi OK (Nms)` — thời gian tái lập thật sự là bao nhiêu (để chỉnh timeout 12s cho hợp lý).
- Sau wake, sync có chạy trọn (`updateFirebaseStatus` → flags → messages) mà không còn `-1` không.
- `[BOOT] WiFi: <ssid> (NVS|default)` — SSID đang dùng có đúng là mạng nhà không.

---

### Gotcha treo: I2S sample rate không được reset khi đổi bài (2026-09-03, CHƯA sửa)

User báo audio phát nhanh hơn hình, **reset box thì tự hết** nên đã dừng truy cứu. Ghi lại vì "reset
là hết" khớp đúng với một bug tiềm ẩn tìm được dọc đường, và nó sẽ tái xuất hiện:

`AudioPlayer::stop()` đặt lại biến theo dõi `_sampleRate = AUDIO_SAMPLE_RATE` (8000) **nhưng không đặt
lại tốc độ I2S phần cứng**. Trong khi `loadFromStorage()` chỉ gọi `i2s_set_sample_rates()` khi
`sampleRate != _sampleRate`. Hậu quả:
- Phát bài 16kHz → HW = 16000×4 = 64000, `_sampleRate` = 16000
- `stop()` → `_sampleRate` = 8000, **HW vẫn 64000**
- Phát bài 8kHz → `8000 == 8000` → **bỏ qua set rate** → HW giữ 64000 trong khi cần 32000 → phát nhanh 2x

Reset box làm `init()` mở lại I2S ở rate mặc định nên triệu chứng biến mất — đúng như quan sát.

**Dữ liệu thật đã đo** (file user gửi, đọc header RIFF): các message cũ là **16000 Hz**, các message
mới là **8000 Hz** → đúng kịch bản trên. Lưu ý trung thực: cơ chế này cho ra sai lệch **2x**, user mô
tả "4x" — nên có thể chưa phải toàn bộ câu chuyện, hoặc "4x" là ước lượng cảm quan.

**Không phải do các thay đổi trong phiên 2026-09-02/03**: `git show bc0f80a --stat` xác nhận chỉ
`MediaPlayer.cpp` bị đụng (118 thêm / 1 xoá, dòng xoá là `decodeOneFrame(false)` ở nhánh ảnh tĩnh);
`AudioPlayer.cpp`, `AudioPlayer.h`, `config.h` **không hề bị sửa**. Đây là bug có sẵn từ trước.

**Cách sửa khi nào quay lại**: bỏ điều kiện `sampleRate != _sampleRate`, luôn gọi
`i2s_set_sample_rates(I2S_NUM_0, sampleRate * AUDIO_OVERSAMPLE)` trong `loadFromStorage()`; hoặc cho
`stop()` reset luôn HW về `AUDIO_SAMPLE_RATE * AUDIO_OVERSAMPLE` cho khớp với biến theo dõi.

#### Cần user xác nhận trên máy thật (chưa build/flash/deploy)
1. Card cũ (video/ảnh/voice/text riêng lẻ) không bị regression.
2. Card "Tin nhắn tĩnh" — từng tổ hợp riêng lẻ (chỉ ảnh/chỉ text/chỉ nhạc nền) và tổ hợp 2-3 thành phần.
3. Combo ảnh+voice (kể cả từ card cũ) giờ có tiếng — trước đây câm.
4. Tải lỗi/stall với audio/text-only: slot phải bị `discardWrite()` sạch, không để lại slot rác.
5. Sau khi nạp firmware NSL3 lần đầu: tin nhắn cũ (nếu còn) bị xoá 1 lần — xác nhận đúng dự kiến.
6. Message tạo từ card mới xuất hiện trên Firebase với `type:"image"` (không phải `"static"`) và có
   `bg_music_url` khi có đính kèm audio.

---

## 12. PHASE 4 — Hoàn thiện tầng lưu trữ THẺ SD (2026-09-04, CHƯA flash/test máy thật)

> Đánh số **12** để chừa §10/§11 cho nhánh `security-hardening` đang viết song song — hai nhánh cùng
> append vào cuối file này, trùng số sẽ thành xung đột đúng vùng đã được dặn tránh.

Bối cảnh: module SD sắp hàn **thay thế** W25Q128 trên đúng bộ chân cũ (kể cả CS = GPIO 8), hai chip
không bao giờ cùng nằm trên bo. `SDStorageProvider` trước đó mới là scaffold Phase 3A, **không chạy được**.

### Quyết định đã CHỐT với user (2026-09-04)
- **20 slot** trên thẻ (NAND giữ 3 vì bị giới hạn 16MB).
- **Trạng thái hàng chờ nằm trên THẺ** (`/media/index.bin`), KHÔNG dùng NVS — để trạng thái đi theo dữ
  liệu khi rút/cắm thẻ, tránh cảnh NVS báo "có tin chưa đọc" mà file đã biến mất theo thẻ.
- Làm trên nhánh `main` tại worktree gốc. `ACTIVE_STORAGE_TYPE` **giữ `STORAGE_TYPE_NAND`** khi commit.

### Vì sao 20 slot KHÔNG cần đụng class cha
`IStorageProvider` trao đổi hoàn toàn bằng **chuỗi identifier**, không có hàm nào trả về slot index hay
bitmask. `_unreadBitmask` là private member của riêng `NandStorageProvider` (`NandStorageProvider.h:56`).
Bản SD dùng **1 byte cờ `unread` mỗi slot** trong manifest nên vượt trần 8 thoải mái.
Ràng buộc thật sự duy nhất: `NetworkManager.cpp:1043,1178` khai báo `char writeSlotId[16]` → identifier
phải ≤ 15 ký tự (đang dùng thập phân trần `"0"`…`"19"`, 2 ký tự).

### Bug NGHIÊM TRỌNG đã tìm ra và sửa: không có thẻ = treo cứng box
`main.cpp:398-404` chạy `while (1) { delay(100); }` khi `storage->init()` trả `false`.
`NandStorage::init()` **không bao giờ** trả false nên nhánh này chưa từng chạy trong đời.
`SD.begin()` thì trả false mỗi khi thẻ vắng/lỏng/không phải FAT — tình huống **bình thường** với thẻ rút
được. Bản cũ `SDStorageProvider::init()` trả thẳng kết quả mount ra ngoài.
→ **`init()` giờ LUÔN trả `true`**; không mount được thì chạy ở chế độ rỗng (`isFull()` trả true để hệ
thống không cố tải, `hasUnreadMessage()`/`getUnreadCount()` trả 0).

### Xung đột SPI mode (nguy cơ nhiễu hình lớn nhất) — đã xử lý
Thư viện `SD` của Arduino-ESP32 **hardcode `SPI_MODE0`** (`sd_diskio.cpp`, struct `AcquireSPI`, cả 2
constructor) và `SD.begin()` **không có tham số mode** → phía SD không dời được. Đã kiểm chứng trực tiếp
trong source `~/.platformio/packages/framework-arduinoespressif32/`.
→ Thêm `SPI_BUS_MODE` vào `config.h`, gate bằng `ACTIVE_STORAGE_TYPE`: **0 cho SD, 3 cho NAND**.
`DisplayDriver.h:19` đọc hằng số này. Bản NAND commit ra cấu hình LovyanGFX **giống hệt trước**.
`Panel_ST7789` của LovyanGFX vốn mặc định mode 0 nên đây không phải hạ cấp.
Comment `Mode 3 (obligatory)` ở `DisplayDriver.h:9` là **SAI**, đã sửa (xem đính chính ở §2).

**Bẫy đã tránh:** NOP hack ở `NandStorage::acquireSPI()` mở `SPISettings(..., SPI_MODE3)`. Copy nguyên
sang `SDCardManager` là **tái tạo đúng cú lật CPOL đang muốn khử**. Bản SD dùng `SPI_BUS_MODE`.

> ❌ **HƯỚNG "KÉO CẢ BUS VỀ MODE0" Ở TRÊN ĐÃ THẤT BẠI trên máy thật (2026-09-17).**
> Nạp bản SD MODE0 → màn hình đen hoàn toàn (đèn nền/touch/bíp vẫn chạy); ép MODE3 → hiển thị lại.
> Giả định "Panel_ST7789 mặc định mode 0 nên không phải hạ cấp" là SAI cho panel CS-less này: nó
> **bắt buộc MODE3**. Với màn hình MODE3 mà thư viện SD vẫn MODE0 thì box đứng hình ở "Booting..."
> (lệch khung byte khi truy cập thẻ).
> **Hướng thay thế đã làm:** chép thư viện SD của framework (6 file, Apache 2.0) vào `lib/SD`, đổi đúng
> 2 dòng `SPI_MODE0` → `SPI_MODE3` trong struct `AcquireSPI` (`lib/SD/src/sd_diskio.cpp`) — mọi lưu
> lượng SPI của thư viện đi qua đó. Xác nhận bằng `pio run -v`: LDF resolve `SD @ 2.0.0` về
> `lib\SD`, không dùng bản framework. `SPI_BUS_MODE` giờ là `3` cố định, bỏ cổng `#if`.
> ✅ **Đã kiểm chứng máy thật 2026-09-17** (bo vẫn còn NOR, chưa cắm thẻ): bản SD với `lib/SD` MODE3
> boot vào tới màn hình chờ bình thường — xác nhận việc đứng ở "Booting..." trước đó là do thư viện SD
> MODE0 làm lệch khung byte màn hình, không phải treo.
> **Chưa kiểm chứng thẻ SD thật chạy được MODE3** (cả hai mode đều lấy mẫu sườn lên nên thường
> được, nhưng phải thử). Nếu nâng cấp framework-arduinoespressif32, phải so lại `lib/SD` với bản mới.

### Tổ chức thư mục trên thẻ
```
/media/index.bin      manifest 488B (hàng chờ + metadata 20 slot), giữ trong RAM
/media/slot_NN.bin    media — layout GIỐNG HỆT slot NAND:
                        [4B kích thước][header container 16B][payload][AUDC + audio]
/media/slot_NN.txt    caption sidecar (chỉ tạo khi tin có text)
```
- **Audio nối vào CÙNG file** với video (như NAND) → `readAt(dataSize + k)` chỉ là đọc offset tuyệt đối,
  **`AudioPlayer` không phải sửa dòng nào**, không rủi ro regression bản NAND.
- **Caption để file sidecar** chứ không nhét manifest: 256B × 20 = 5KB RAM thường trú, quá đắt trên
  ESP32-C3 nơi §8 đang giành từng KB cho TLS handshake.
- Mọi đường dẫn dựng từ **index đã parse**, không bao giờ từ chuỗi thô → diệt tận gốc bug cũ:
  `buildFilePath()` map `"0"`→`/media/0.bin` nhưng `"slot_0"`→`/media/slot_0.bin`, trong khi đường ghi
  trả `"slot_0"` còn `getFirstValidIdentifier()` trả `"0"` → **ghi và đọc trỏ 2 file khác nhau**.

### Các bug khác của bản SD cũ đã sửa
| Bug | Hậu quả |
|---|---|
| `seek()` là hàm rỗng | Toàn bộ đường đọc `MediaPlayer` chạy bằng `seek()` → **không phát được gì** |
| `readAt()` không override (mặc định trả 0) | `AudioPlayer` fail ở bước kiểm magic `AUDC` → **câm vĩnh viễn** |
| `isFull()` cứng `false` + `getNextWriteSlotIdentifier()` luôn trả `"slot_0"` | **Mọi lượt tải ghi đè cùng 1 file** |
| `getItemInfo()` cứng `type=VIDEO, fps=15`, `dataSize` = cả file | Sai metadata; còn gọi `getFileSize()` (I/O thật) **mỗi frame** vì `main.cpp:183` gọi nó mỗi vòng `player.update()` |
| `getNextValidIdentifier()` hardcode `% 5` | Sai với mọi slot count khác 5 |
| `Serial.println` nhưng `main.cpp` không `Serial.begin()` | **Mọi lỗi SD vô hình** → đã đổi hết sang `DLOG` |

### Chi tiết cài đặt đáng nhớ
- **`_hdrPeek`**: chụp 16 byte header container vào RAM ngay trong `writeChunk` khi con trỏ ghi còn dưới
  20, thay vì đọc ngược từ file lúc `closeWrite()` như NAND (NAND đọc lại được vì ghi thẳng flash; SD
  còn buffer stdio xen giữa). Sentinel `dataSize == 4` rơi ra miễn phí: nhánh text-only không ghi gì →
  `_hdrPeek` toàn 0 → nhánh `else` → `VIMG/4/fps=1/frames=1`, đúng y bản NAND.
- **Back-patch 4 byte tiền tố**: `seek(0)` trên chính handle `"w"` đang mở rồi ghi 4 byte. `"w"` là
  `O_TRUNC` — cắt file xảy ra lúc **open**, không phải lúc write, nên ghi đè đầu file không làm ngắn file.
  Phương án dự phòng nếu sai: đóng rồi mở lại mode `"r+"`.
- **`openForAppend()` seek tới `slots[idx].dataSize`, KHÔNG phải EOF** → header `AUDC` rơi đúng offset mà
  `AudioPlayer::loadFromStorage()` dò (`readAt(dataSize, ...)`), kể cả sentinel `dataSize == 4`.
- **`readAt()` dùng file handle THỨ HAI** (`_atFile` trong `SDCardManager`). Seek-rồi-seek-lại trên một
  handle chung chính là bug mà comment ở `IStorageProvider.h:44-47` tồn tại để chặn — mỗi vòng
  `MediaPlayer::update()` chạy `readAt`→`readData`→`readAt` liên tục.
- **`closeWrite()` và `discardWrite()` đều XOÁ file `.txt`**: NAND miễn nhiễm vì `setSlotInfo()` `memset`
  cả `SlotEntry` (giết luôn `textLen`); sidecar không có ràng buộc đó nên caption tin cũ sẽ hiện đè lên
  tin mới dùng lại slot.
- **`SD.begin()` mặc định 4MHz** → quá chậm cho video 15fps. Đang đặt `SD_SPI_FREQ_HZ = 20MHz`.
- **`discardWrite()` có 2 nhiệm vụ** (giống NAND): huỷ phiên chưa commit, VÀ undo slot **đã commit** —
  đường "tin nhắn tĩnh" gọi `closeWrite()` trước rồi mới biết audio có tải được không.

### Quy tắc đã áp dụng cho code mới (đừng phá khi sửa sau)
- `DLOG` **phải nằm ngoài** vùng giữ mutex: `ScreenLogger::render()` lấy chính `spiMutex` (không đệ quy,
  timeout 50ms). Một `DLOG` đặt nhầm trong `writeChunk` (chạy mỗi 2KB) tốn 50ms/chunk và **trông y hệt
  lỗi mạng**. Vì vậy `writeChunk`/`appendChunk` cố tình không có log nào ở nhánh thành công.
- Mọi lời gọi `SD.*` / `File.*` phải nằm trong `acquireSPI()/releaseSPI()`; không `acquireSPI()` lồng nhau.
- `getItemInfo()` và `isFull()` **thuần RAM, zero I/O** (bị gọi mỗi frame / mỗi tick UI).
- **KHÔNG dùng `File::size()`** để tính `dataSize`: `VFSFileImpl::size()` gọi `stat()` → trả kích thước
  trên đĩa, bỏ sót phần còn trong buffer stdio. Phải đếm bằng giá trị `fwrite`/`write` **trả về**.
- `lib/NandStorage/*` phải có **0 dòng thay đổi** — đừng "dọn" 4 literal `SPI_MODE3` ở đó sang hằng số mới.

### Đã cân nhắc và LOẠI (đừng đào lại)
- `index.bak` / temp+rename cho manifest: manifest cụt đã tự fail magic check và rơi về "hàng chờ rỗng,
  file còn nguyên" — backup cũ dẫn tới đúng trạng thái đó chỉ sau 1 tin nhắn, không đáng thêm code.
- **Dựng lại manifest bằng cách quét file trên thẻ**: không tách được `dataSize` khỏi `audioSize` từ file
  → cho ra playback **sai một cách tự tin** (audio câm + frame rác) thay vì "không có tin" trung thực.
- Trần dung lượng mỗi slot trong `writeChunk`: giới hạn thật của SD là dung lượng trống, `fwrite` trả
  short count là tín hiệu tự nhiên (NAND cần `_slotCapacity` vì slot là vùng flash cố định).

### CHƯA build/flash/test — cần user xác minh
> **Không tháo NOR cho tới khi xác minh xong Phase A của nhánh bảo mật.**

1. **Bản NAND sau khi sửa `DisplayDriver.h`**: màn hình/đồng hồ/video/audio y như cũ (`SPI_BUS_MODE` = 3).
2. Bản SD, thẻ trắng: có thể thấy chớp nhiễu ngắn lúc `SD.begin()` — đó là NOP hack đang chạy, không phải
   lỗi. Lần redraw kế tiếp phải sạch.
3. **Phép thử phân biệt lệch khung byte**: phát tin **ảnh tĩnh + voice** (state `SHOWING`, nơi overlay
   `ScreenLogger` vẫn bật — `MediaPlayer.cpp:308` chỉ tắt cho `PLAYING`). Nhìn chữ overlay render sạch
   30s+ trong lúc audio chạy. Tin video che mất triệu chứng này hoàn toàn.
4. Boot **không thẻ**: standby vẫn vẽ, **không treo**, hiện `[SDP] khong co the`.
5. Hexdump `/media/slot_00.bin` sau khi tải video: byte 0..3 = LE (filesize − audioSize − 4); byte 4..7 =
   `SLBX`/`VJPG`/`VIMG`; tại offset `dataSize` có ASCII `AUDC`. Một phép kiểm này xác thực cùng lúc
   back-patch, parse `_hdrPeek`, và gốc append.
6. Tin chỉ text/voice: file đúng `4 + 10 + audio` byte, `dataSize == 4`, phát ra màn đen + chữ + tiếng,
   **không** lỗi `Bad jpegSize`.
7. Tải 20 tin không đọc → tin thứ 21 báo full. Đọc 1 tin → lượt tải kế rơi vào **đúng slot đó**.
8. Ép lỗi giữa chừng (rút Wi-Fi ~50%): `slot_NN.bin` **và** `.txt` biến mất, sync sau retry **đúng slot cũ**.
9. Tái dùng slot: tin có caption vào slot 3 → đánh dấu đã đọc → tin không caption vào slot 3 →
   **không còn caption cũ trên màn hình**.
10. Tự chữa lành, **hai kiểu hỏng khác nhau**, phải thử cả hai:
    - **Xoá** 1 file `.bin` trên máy tính rồi cắm lại → `getNextUnreadIdentifier()` bỏ cờ unread, đi tiếp.
    - **Cắt ngắn** 1 file `.bin` (giữ file nhưng xén bớt byte) → `openForRead()` phải trả false với log
      `slot N cut:`. Đây là kiểu hỏng mà `fileExists()` KHÔNG thấy; nếu lọt thì mỗi frame sẽ đâm vào
      `Read short` + `delay(2000)` của MediaPlayer, treo hình từng nhịp 2 giây.
11. `Read short` / `Bad jpegSize` khi phát trên SD = độ trễ đọc, **không phải lỗi logic** → nghi can đầu
    là `SD_SPI_FREQ_HZ` (thử hạ 10MHz), thứ hai là class thẻ. `[NET] dl STALL` chỉ xuất hiện ở bản SD →
    thử bỏ dòng `setBufferSize(512)` trong `SDCardManager::openFileForWrite()`.

### Rủi ro còn treo (đo, đừng thiết kế vòng quanh)
- **Tốc độ nạp audio**: `AudioPlayer::tick()` gọi tới ~6 lần `readAt` 256B, 2 lần mỗi frame. Đã thêm bước
  bỏ qua seek khi đúng vị trí (`_atPos`) + readahead stdio, nhưng đây là dự đoán thông lượng, chỉ phần
  cứng mới chốt được. Cần lever đầu tiên: `SD_SPI_FREQ_HZ`.
- **Heap**: mỗi `File` mở cấp 1 buffer stdio; kích thước mặc định 4096 chỉ áp dụng **có điều kiện**
  (`vfs_api.cpp:301`, khi `st_blksize == 0`) nên chi phí thật **chưa kiểm chứng**. Có 2 read handle sống
  cùng lúc với `_jpegBuffer` 32KB của `MediaPlayer`. Nếu `[PLAY] JPEG buf alloc fail` xuất hiện ở bản SD
  mà không có ở NAND thì đây là nguyên nhân → gọi `setBufferSize()` cho các read handle.

---

## 10. Vá bảo mật theo `code_review_2_9_gemini_38.md` — Phase A: bật xác thực TLS (2026-09-03)

Kế hoạch đầy đủ (Phase A→D + phát hiện ngoài báo cáo) nằm ở
`C:\Users\phamp\.claude\plans\t-i-c-n-b-n-c-sequential-treasure.md`.
Phạm vi user chốt: **bỏ OTA** (VULN-02/12 — chỉ test local, chấp nhận rủi ro) và **bỏ VULN-04**
(erase 5.5MB — đã fix ở vòng 2).
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

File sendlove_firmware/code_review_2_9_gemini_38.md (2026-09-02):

# BÁO CÁO KIỂM TOÁN MÃ NGUỒN VÀ BẢO MẬT FIRMWARE (CODE REVIEW)
**Ngày thực hiện:** 02/09/2026  
**Thực hiện bởi:** Gemini 3.8 Flash (Autonomous Code Security Audit)  
**Mục tiêu:** Quét toàn bộ codebase `sendlove_firmware` (ESP32-C3), phân tích thuần túy trên mã nguồn C/C++, phát hiện các lỗ hổng bảo mật, lỗi logic phần cứng, xung đột bộ nhớ và rủi ro vận hành.

---

## 1. TỔNG QUAN ĐÁNH GIÁ (EXECUTIVE SUMMARY)

Hệ thống firmware được xây dựng theo mô hình Event-driven trên nền FreeRTOS với sự phân tầng rõ ràng (Storage Abstraction `IStorageProvider`, Display Driver LovyanGFX, Audio/Video Media Player). Tuy nhiên, qua quá trình kiểm tra sâu mã nguồn, phát hiện 12 điểm yếu kỹ thuật thuộc nhiều mức độ nghiêm trọng:
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

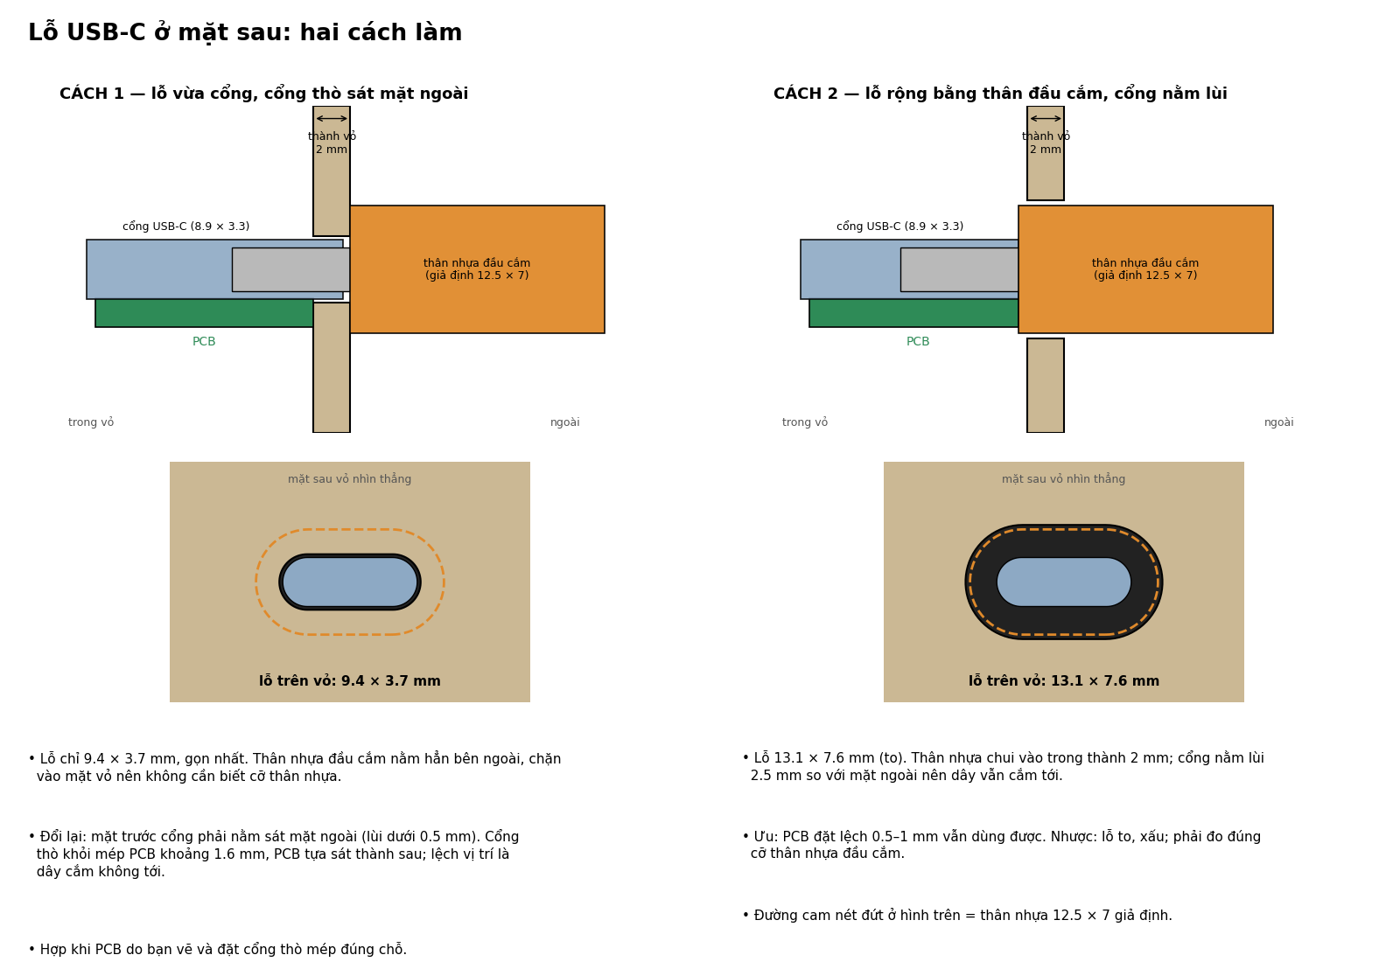
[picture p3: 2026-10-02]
sendlove_enclosure/breadcat/usb_hai_cach.png

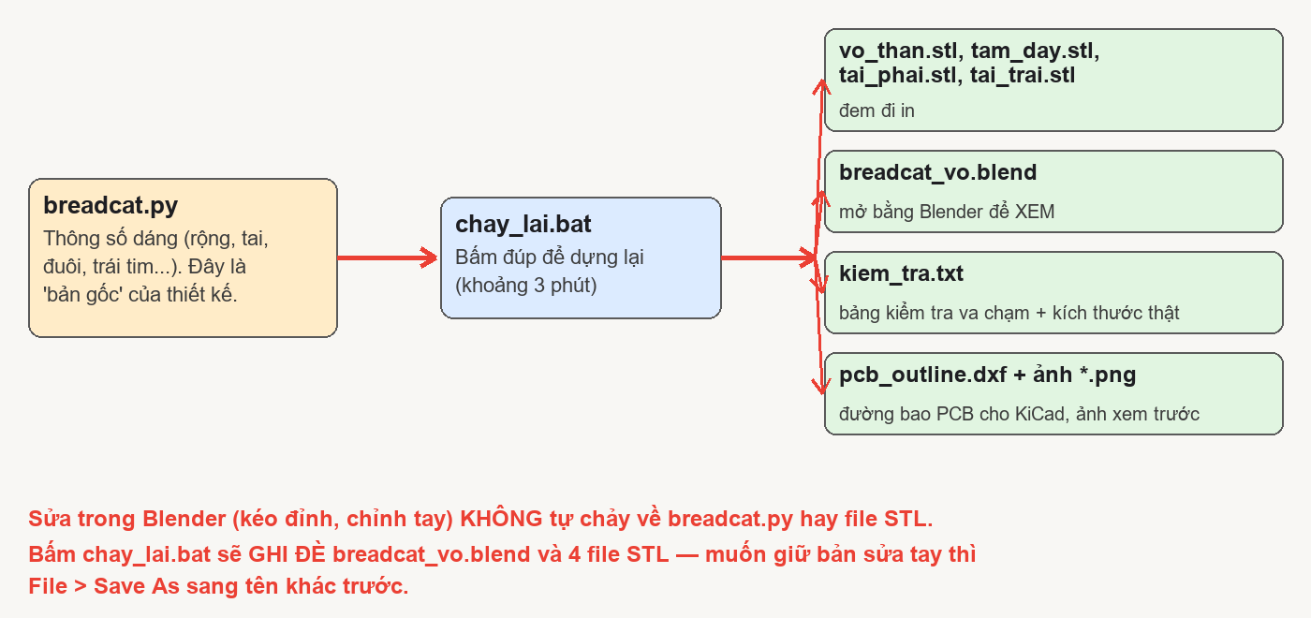
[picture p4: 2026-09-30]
sendlove_enclosure/breadcat/huong_dan/H01_so_do_file.png

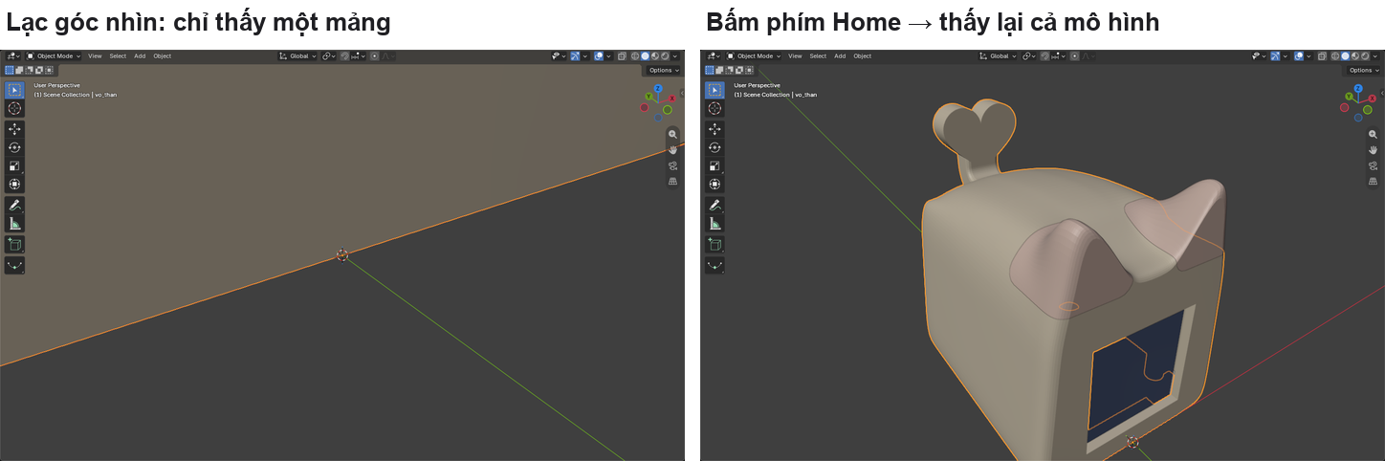
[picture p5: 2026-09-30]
sendlove_enclosure/breadcat/huong_dan/H06_lac_home.png

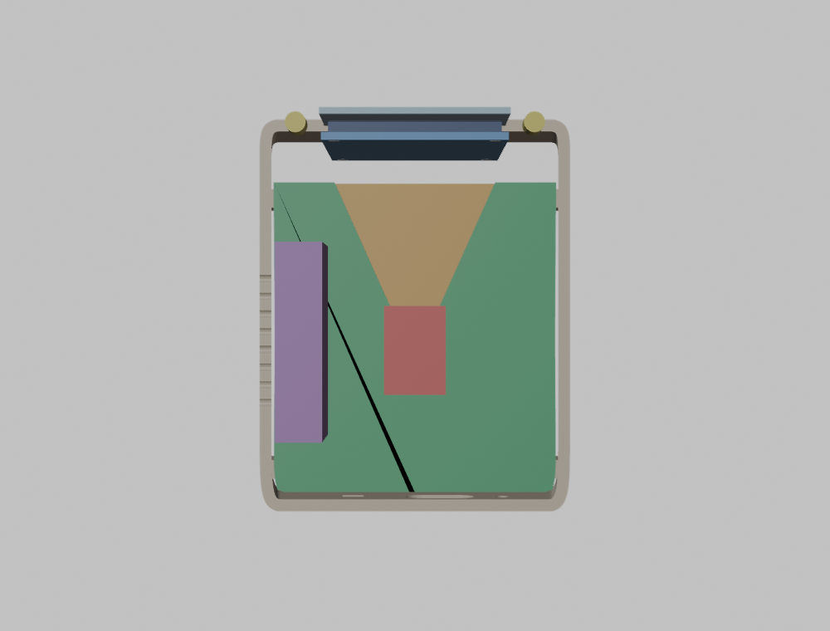
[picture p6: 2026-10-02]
sendlove_enclosure/breadcat/ky_thuat_cat_ngang.png

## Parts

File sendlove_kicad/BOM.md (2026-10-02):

# SendLove Box — danh sách linh kiện (rút từ firmware v2.1.0)

Nguồn: `sendlove_firmware/include/config.h`, `platformio.ini`, `lib/*`. Schematic `main/main.kicad_sch` đã vẽ đủ các khối (2026-09-26, ERC 0 lỗi); reference trong bảng dưới chưa ghi, xem trực tiếp schematic.

Giả định:
- Dùng **module** ESP32-C3, không vẽ SoC rời + thạch anh + anten.
- Bộ nhớ media là **thẻ microSD** (`ACTIVE_STORAGE_TYPE = STORAGE_TYPE_SD`).
- **Không đo pin** ở bản này. GPIO3 giữ nguyên cho đèn nền, không phải đổi chân.

## 1. Sơ đồ chân

| GPIO | Chức năng | Nguồn | Ghi chú mạch |
|---|---|---|---|
| 0 | I2S BCLK → MAX98357A | config.h:163 | |
| 1 | I2S LRC → MAX98357A | config.h:164 | |
| 2 | I2S DOUT → MAX98357A DIN | config.h:165 | **Strapping**: phải HIGH lúc boot → kéo lên 10k |
| 3 | TFT BLK (PWM 44.1kHz, 9-bit) | config.h:15, DisplayDriver.cpp:9 | Giữ LOW khi ngủ bằng `gpio_hold_en` |
| 4 | SPI SCK (chung TFT + SD) | config.h:9 | SPI MODE3 bắt buộc |
| 5 | SPI MISO (chỉ SD dùng) | config.h:8 | Kéo lên 10k (DAT0 thẻ SD) |
| 6 | SPI MOSI | config.h:7 | TFT 40MHz, SD 10MHz |
| 7 | TFT DC | config.h:13 | |
| 8 | SD CS | config.h:22, 202 | **Strapping** → kéo lên 10k (cũng là pull-up CS) |
| 9 | TFT RST | config.h:14 | **Strapping/BOOT**: LOW lúc boot = vào chế độ nạp → kéo lên 10k. Nút BOOT nối qua R 1k (xem mục Vi điều khiển) |
| 10 | Touch TTP223 OUT (active HIGH, đánh thức light sleep) | config.h:26, PowerManager.cpp:98 | Firmware bật pull-down nội |
| 18/19 | USB D-/D+ | | Nạp code + Serial (USB CDC) |
| 20 | **Bật/tắt ampli** → MAX98357A SD_MODE | *mới, chưa có trong firmware* | HIGH = phát, LOW = shutdown |
| 21 | **LED thông báo** | *mới*, config.h:27 (`PIN_LED` dự trữ) | Active HIGH. Là U0TXD nên LED chớp nhẹ lúc ROM in log khởi động, chấp nhận được |

Không còn GPIO trống.

## 2. BOM

### Vi điều khiển
| SL | Linh kiện | Gợi ý mã | Ghi chú |
|---|---|---|---|
| 1 | Module ESP32-C3, flash 4MB | ESP32-C3-MINI-1-N4 | `partitions_ota.csv` cần 4MB |
| 1 | Tụ 10µF | 0603 | Sát chân 3V3 module |
| 1 | Tụ 100nF | 0402 | Sát chân 3V3 module |
| 1 | R 10k + C 1µF | | Mạch RC cho chân EN |
| 2 | Nút nhấn SMD (hoặc 2 cặp pad hàn) | | RESET: EN→GND. BOOT: GPIO9→R 1k→GND |
| 1 | R 1k nối tiếp nút BOOT | | GPIO9 đang xuất HIGH cho TFT RST; nhấn BOOT không có R này là chập chân ra xuống GND |
| 3 | R 10k pull-up | | GPIO2, GPIO8, GPIO9 |

Nạp code qua USB GPIO18/19 hầu như không cần nút BOOT; nút chỉ để cứu chip.

### Màn hình
| SL | Linh kiện | Gợi ý mã | Ghi chú |
|---|---|---|---|
| 1 | LCD IPS 240×240 ST7789, **không có chân CS** | 1.3" hoặc 1.54" | `invert=true`, `rgb_order=true`, offset 0 (DisplayDriver.h:44-52) |
| 1 | Header 1×7 2.54mm hoặc đầu FPC theo panel | | Module: GND VCC SCL SDA RES DC BLK |
| 1 | N-MOSFET đèn nền | AO3400 / 2N7002 | Chỉ cần nếu dùng panel trần (dòng LED vượt khả năng GPIO). **Schematic hiện dùng module, không vẽ** |
| 1 | R 100Ω gate + R 100k gate→GND | | Kéo xuống để đèn tắt lúc boot. Không vẽ, cùng lý do trên |

### Bộ nhớ media
| SL | Linh kiện | Gợi ý mã | Ghi chú |
|---|---|---|---|
| 1 | Khe microSD push-push | Hirose DM3AT / Molex 503398 | SPI 10MHz, 20 slot tin nhắn |
| 4 | R 10k pull-up | | CMD(MOSI), DAT0(MISO), DAT1, DAT2 |
| 1 | Tụ 10µF + 100nF | | Cấp nguồn thẻ |

Không cắt nguồn thẻ SD khi ngủ: SCK/MOSI dùng chung với màn hình và nghỉ ở HIGH (MODE3), thẻ sẽ bị cấp điện ngược qua diode bảo vệ. Thẻ chờ (CS HIGH) ăn vài chục–vài trăm µA tuỳ loại, nên đo thực tế khi chọn thẻ.

Phương án thay thế (không lắp cùng lúc, chung CS GPIO8): W25Q128JVSIQ SOIC-8 + 100nF — chỉ 3 slot.

### Âm thanh
| SL | Linh kiện | Gợi ý mã | Ghi chú |
|---|---|---|---|
| 1 | Ampli I2S class-D | MAX98357AETE+ (TQFN-16) | VDD nối thẳng VBAT/VSYS (2.5–5.5V), không qua LDO 3.3V |
| 1 | R 680k: GPIO20 → SD_MODE | | Cùng R kéo xuống 100k bên trong ampli: HIGH → ~0.42V = chế độ (L+R)/2 (dải 0.16–0.77V); LOW → shutdown <1µA. Tiết kiệm ~2mA khi không phát |
| 1 | R_GAIN: footprint 0603 từ chân GAIN xuống GND | Không lắp / 0Ω / 100k | Chọn độ lợi bằng linh kiện lắp vào: **không lắp = 9dB**, **0Ω = 12dB**, **100k = 15dB**. Chốt 2026-09-24 (xem ghi chú dưới bảng) |
| 1 | Tụ 10µF | | Sát VDD ampli |
| 1 | Tụ 100nF | | Sát VDD ampli |
| 1 | Loa 8Ω 1W, 28–36mm | | Cần buồng kín phía sau, không thì mất bass (SHOULD_READ.md:58) |
| 1 | Đầu JST-PH 2 pin | | Nối loa |

Firmware xuất stereo `RIGHT_LEFT` với hai kênh giống nhau, nên chế độ kênh nào của ampli cũng phát đúng.

**Vì sao để pad chọn GAIN (chốt 2026-09-24):** firmware sắp có cài đặt âm lượng và nhạc báo thức, nhưng âm lượng phần mềm chỉ **giảm** được (nhân mẫu PCM với hệ số ≤ 1). Mức 100% trên web chính là mức của chân GAIN. Nếu 9dB không đủ to cho báo thức thì chỉ việc lắp 0Ω hoặc 100k, không phải sửa mạch. Chọn mức thấp nhất vẫn đủ to: 15dB ở âm lượng 100% có thể vượt 1W của loa khi pin đầy. Bảng nối chân theo trang pinout của Adafruit cho board MAX98357: 100k xuống GND = 15dB, nối GND = 12dB, để hở = 9dB, nối Vin = 6dB, 100k lên Vin = 3dB.

### LED thông báo
| SL | Linh kiện | Gợi ý mã | Ghi chú |
|---|---|---|---|
| 1 | LED 0603/0805 | | GPIO21 → R → LED → GND |
| 1 | R hạn dòng 1k | | ~1–2mA là đủ sáng trong hộp; LED sáng liên tục ăn pin ngang cả hộp đang ngủ |

### Cảm ứng
| SL | Linh kiện | Gợi ý mã | Ghi chú |
|---|---|---|---|
| 1 | IC cảm ứng điện dung | TTP223-BA6 (SOT-23-6) | TOG=0 (direct), AHLB=0 (active HIGH). Firmware đo thời gian giữ nên **không** được dùng chế độ toggle |
| 1 | Tụ Cs 0–50pF | | Chỉnh độ nhạy |
| 1 | Tụ 100nF | | Nguồn IC |
| 1 | Pad đồng cảm ứng trên PCB | | Schematic tạm dùng footprint TestPoint 4mm; vẽ pad thật (~10–15mm) ở bước PCB |

### Nguồn
| SL | Linh kiện | Gợi ý mã | Ghi chú |
|---|---|---|---|
| 1 | Cổng USB-C 16 pin (USB 2.0) | | D+/D- → GPIO19/18 |
| 2 | R 5.1k | | CC1, CC2 xuống GND |
| 1 | ESD cho USB | USBLC6-2SC6 | |
| 1 | IC sạc LiPo 1 cell | **TP4056-42-ESOP8** (chốt 2026-09-26) | Chân CHRG chỉ nối LED sạc (không còn GPIO để đọc). CE nối VBUS, STDBY bỏ trống |
| 1 | R PROG 2k | | Dòng sạc ~580mA (không để 1A: IC tuyến tính toả ~1.5W) |
| 1 | NTC 10k B3950 + R 6.2k 1% | | Chân TEMP: 6.2k từ VBUS xuống TEMP, NTC từ TEMP xuống GND, dán NTC lên thân pin. Ngưỡng 45%/80% VCC (đã đối chiếu datasheet TP4056-42 rev 2.4) → với B3950, cửa sổ sạc ~6–41°C |
| 2 | Tụ 10µF | | VBUS (đầu vào sạc) và VBAT |
| 1 | LED sạc + R 1k | | Chỉ sáng khi cắm USB, không ăn pin |
| 1 | Pin LiPo 3.7V ~1000mAh có mạch bảo vệ | | MEMORY.md tính theo 1000mAh |
| 1 | (Nếu pin không có PCM) DW01A + FS8205A | | |
| 1 | P-MOSFET + Schottky làm power-path | AO3401 + SS14 | Cắm USB thì chạy nguồn USB. VBUS → SS14 → VPATH; AO3401: D = VBAT, S = VPATH, G = VBUS |
| 1 | R 100k cổng P-MOSFET → GND | | Rút USB thì cổng về 0V để MOSFET mở cho pin cấp điện |
| 1 | LDO 3.3V, ≥500mA, Iq thấp | **RT9080-33GJ5** (chốt 2026-09-26) | Wi-Fi TX đỉnh ~350mA. EN nối VSYS. Gói TSOT-23-5: 1 VIN, 2 GND, 3 EN, 4 NC, 5 VOUT (datasheet DS9080-09) |
| 1 | Công tắc trượt nguồn | SPDT, PCM12 | VPATH → VSYS: tắt máy vẫn sạc được |
| 2 | Tụ 10µF | | In/out LDO |

Không vẽ LED báo nguồn nối cứng (MEMORY.md mục C: làm pin 1000mAh từ 52 ngày còn 9 ngày).

## 3. Firmware phải sửa theo mạch này

1. **Bật USB CDC**: bỏ comment `-D ARDUINO_USB_CDC_ON_BOOT=1` và `-D ARDUINO_USB_MODE=1` trong `platformio.ini`. Không bật thì Serial vẫn chiếm GPIO20/21 (UART0).
2. **Chân ampli** (GPIO20): kéo LOW ngay đầu `setup()`, chỉ HIGH trong lúc phát âm thanh (AudioPlayer), giữ LOW khi ngủ bằng `gpio_hold_en`.
3. **LED thông báo** (`PIN_LED` = 21): code LED đã bị xoá 2026-09-18 (UIController.h:16), phải viết lại. Muốn LED "thở" lúc light sleep thì LEDC phải chạy clock RC_FAST; nếu không, chỉ sáng tĩnh bằng `gpio_hold_en`.
4. **Pin**: `getBatteryPercentage()` vẫn trả cứng 60, `isCharging()` trả `false` (PowerManager.cpp:37). Icon pin và số % gửi lên Firebase là giả, cần ẩn trên UI/web hoặc ghi chú rõ.

## 4. Giữ giờ: bản này KHÔNG có RTC ngoài (chốt 2026-09-22)

Dùng bộ đếm RTC nội của ESP32-C3 (dao động RC ~136kHz, không có thạch anh 32.768kHz). Chấp nhận:
- Mất giờ khi tắt nguồn, pin cạn, brownout. Có giờ lại sau lần sync NTP đầu tiên sau boot.
- Giờ trôi trong lúc ngủ, được bù ở mỗi lần thức sync NTP.

Bản sau muốn giờ độc lập: chip RTC I2C (PCF8563T + thạch anh 32.768kHz CL 12.5pF, hoặc RV-3028-C7) + pin CR1220 qua BAT54C. Cần 2 GPIO: SCL = GPIO9 (nối TFT RST vào net EN để giải phóng), SDA = GPIO21 (LED thông báo chuyển sang CLKOUT của RTC).

## 5. Nếu sau này muốn đo pin

Chuyển đèn nền sang GPIO20 (LEDC ra được mọi chân), dùng GPIO3 (ADC1, không phải strapping) cho cầu chia, và giải phóng GPIO9 cho chân bật ampli bằng cách nối TFT RST vào net EN. Linh kiện thêm: 2 R 1MΩ 1% (BAT+ → GPIO3 → GND) + tụ 100nF tại GPIO3. Lấy áp ở BAT+, không lấy ở VSYS.

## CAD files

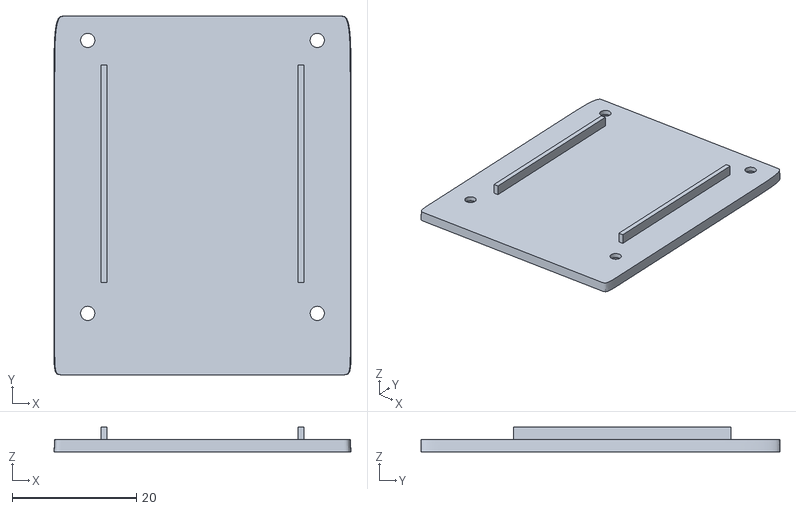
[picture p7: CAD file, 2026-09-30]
sendlove_enclosure/breadcat/tam_day.stl
47.9 x 57.8 x 4.00

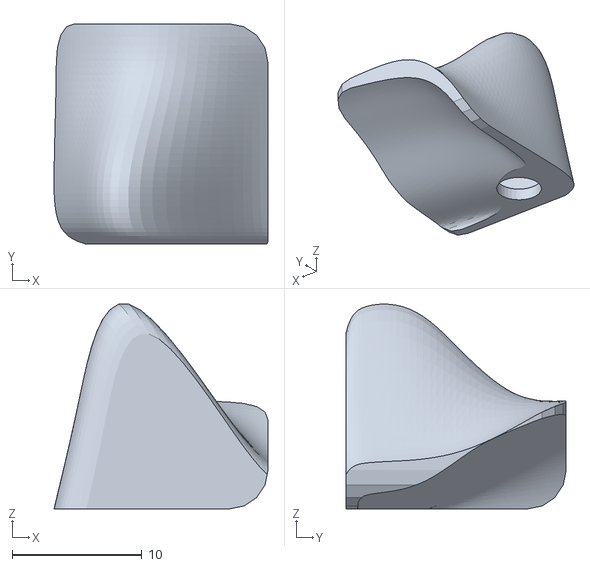
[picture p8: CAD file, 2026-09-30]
sendlove_enclosure/breadcat/tai_trai.stl
16.5 x 17.0 x 15.8

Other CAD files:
sendlove_enclosure/breadcat/pcb_outline.dxf
sendlove_enclosure/breadcat/tai_phai.stl
sendlove_enclosure/breadcat/breadcat_shape.blend
sendlove_enclosure/breadcat/breadcat_vo.blend
sendlove_enclosure/breadcat/breadcat_vo_ban_truoc.blend

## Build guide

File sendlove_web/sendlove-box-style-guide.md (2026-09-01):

# SendLove Box — Style Guide

Khung phong cách thiết kế cho web app (và app native sau này). Đây là nguồn sự thật duy nhất. Mọi giá trị hardcode nằm ngoài file này đều là bug.

Phạm vi: **chỉ giao diện phần mềm**. Màn hình TFT 1.77" trên thiết bị là hệ riêng, không áp dụng file này.

---

## 0. Nguyên tắc dẫn dắt

**Web app là bao bì, không phải món quà.** Vai trò của nó là làm quá trình chuẩn bị quà đáng nhớ, rồi lùi ra nhường chỗ cho chiếc hộp.

Ba hệ quả:

1. **Trau chuốt nằm ở chuyển động và chi tiết nhỏ, không ở độ trang trí.** Transition mượt tạo cảm giác chăm chút mạnh hơn gradient hay hoa văn.
2. **Ít màn hình nhưng mỗi màn hình hoàn thiện.** App chỉ có 4–6 màn hình — đủ ngân sách để polish sâu từng cái.
3. **Mô hình sandwich cảm xúc.** Cảm xúc ở đầu (landing) và cuối (xác nhận đã gửi); ở giữa (luồng upload) là công cụ thuần tuý, tối giản triệt để.

**Phong cách chốt: Warm Minimalism + Motion-led delight.**

---

## 1. Layout

| Thuộc tính | Giá trị | Lý do |
|---|---|---|
| Cấu trúc | Một cột, căn giữa | Port sang native app không phải thiết kế lại |
| Chiều rộng nội dung tối đa | 480px | Giữ tỷ lệ mobile-first ngay cả trên desktop |
| Padding ngang (mobile) | 20px | |
| Padding ngang (desktop) | 24px | |
| Hành động chính mỗi màn hình | Tối đa 1 | Chống rối, dẫn hướng rõ |

Không dùng layout 2–3 cột rộng. Không dùng sidebar.

---

## 2. Typography

### Fonts

| Font | Vai trò | Weight |
|---|---|---|
| Dancing Script | Display duy nhất — landing, màn hình xác nhận gửi thành công | 700 |
| Quicksand | Toàn bộ phần còn lại: heading, body, label, số liệu | 400, 500, 600, 700 |

**Quy tắc khoá cứng:** Dancing Script CHỈ tồn tại ở bậc `display`, và chỉ xuất hiện ở landing + màn hình xác nhận. Tuyệt đối không dùng trong luồng upload, form, nút bấm, caption.

**Số liệu:** Quicksand + `font-variant-numeric: tabular-nums`. Không dùng monospace.

Import (bắt buộc có subset vietnamese):

```
https://fonts.googleapis.com/css2?family=Dancing+Script:wght@700&family=Quicksand:wght@400;500;600;700&display=swap&subset=vietnamese
```

### Type scale

| Token | Vai trò | Mobile | Desktop | Weight | Line-height |
|---|---|---|---|---|---|
| `display` | Landing, xác nhận gửi (Dancing Script) | 40 | 56 | 700 | 1.15 |
| `numeric-hero` | % upload, số liệu điểm nhấn | 30 | 40 | 700 | 1.2 |
| `title` | Tiêu đề màn hình | 22 | 28 | 700 | 1.2 |
| `heading` | Tiêu đề mục / bước | 17 | 20 | 600 | 1.3 |
| `body` | Nội dung chính, mô tả | 15 | 16 | 400 | 1.6 |
| `label` | Nút bấm, label form, tên file | 14 | 15 | 500–600 | 1.4 |
| `caption` | Dung lượng, thời lượng, hint, lỗi | 12 | 13 | 400 | 1.4 |

### Ràng buộc

1. **Sàn 12px.** Nếu buộc nhỏ hơn, tăng weight lên 500 bù độ mảnh của Quicksand.
2. **Line-height body tối thiểu 1.5**, khuyến nghị 1.6 — tiếng Việt có dấu trên và dưới ký tự.
3. **Chỉ weight 400, 500, 600, 700.** Không dùng 300.
4. **Không tạo bậc mới.** Cần size lạ thì chọn bậc gần nhất.
5. Phân cấp heading vs body dựa vào **weight**, không chỉ size.

### Kiểm tra tiếng Việt (bắt buộc trước ship)

```
Kỷ niệm — Yêu thương — Đầu tiên — Những ngày ấy
Chúng mình — Hạnh phúc — Đã gửi — Đang tải lên
ĐĂNG KÝ — Ừm — Ơn giời — Tuyệt vời
```

Dancing Script rủi ro lỗi dấu cao hơn. Nếu lỗi, thay bằng font script khác có Vietnamese subset đầy đủ.

---

## 3. Color

### Phân bổ diện tích

| Nhóm | % màn hình |
|---|---|
| Neutral + Surface | 85–90% |
| Brand (Rose + Caramel) | 5–10% |
| Semantic | 1–3% |

Màu brand vượt 20% màn hình = lạm dụng.

### Ramp: Rose (accent chính)

| Stop | Hex | Gốc |
|---|---|---|
| `rose-50` | `#FDF0EF` | |
| `rose-100` | `#FAD6D3` | Misty Rose |
| `rose-200` | `#F7BCBE` | |
| `rose-300` | `#F4A3AF` | |
| `rose-400` | `#F28AA1` | Salmon Pink |
| `rose-500` | `#E0758E` | |
| `rose-600` | `#C55A73` | |
| `rose-700` | `#9E3A52` | |
| `rose-800` | `#7A2A3D` | |
| `rose-900` | `#4F1A27` | |

### Ramp: Caramel (brand ấm)

| Stop | Hex | Gốc |
|---|---|---|
| `caramel-50` | `#FDF8F3` | |
| `caramel-100` | `#F6DFB3` | Wheat |
| `caramel-200` | `#EFCB93` | |
| `caramel-300` | `#E7AE75` | Fawn |
| `caramel-400` | `#D4915A` | |
| `caramel-500` | `#B87548` | |
| `caramel-600` | `#9E6244` | |
| `caramel-700` | `#83513E` | Bole |
| `caramel-800` | `#603A2C` | |
| `caramel-900` | `#3D2A20` | |

### Ramp: Neutral (xám ám nâu)

Bắt buộc xám ấm. Không dùng xám thuần hay xám ám xanh — sẽ lệch tông với brand chocolate.

| Stop | Hex |
|---|---|
| `neutral-0` | `#FFFFFF` |
| `neutral-25` | `#FDF8F3` |
| `neutral-50` | `#F7F1EA` |
| `neutral-100` | `#EAE0D6` |
| `neutral-200` | `#D9C9BB` |
| `neutral-300` | `#C4B5A9` |
| `neutral-400` | `#A89689` |
| `neutral-500` | `#8A7767` |
| `neutral-600` | `#7A6558` |
| `neutral-700` | `#5C4A3E` |
| `neutral-800` | `#3D2A20` |
| `neutral-900` | `#241812` |

### Semantic

Bắt buộc tách khỏi brand. Không dùng Salmon Pink cho lỗi.

| Vai trò | fill | bg | text |
|---|---|---|---|
| success | `#4A7C59` | `#E3F0E7` | `#2F5C3D` |
| error | `#C4443C` | `#FBE6E4` | `#8E2F29` |
| warning | `#D89B3C` | `#FBF0DC` | `#8A5F16` |

### Purpose tokens — LIGHT

Component chỉ được tham chiếu lớp này, không tham chiếu trực tiếp ramp stop.

**Text**

| Token | Giá trị |
|---|---|
| `--text-primary` | `#3D2A20` (caramel-900) |
| `--text-secondary` | `#7A6558` (neutral-600) |
| `--text-muted` | `#A89689` (neutral-400) |
| `--text-disabled` | `#C4B5A9` (neutral-300) |
| `--text-accent` | `#9E3A52` (rose-700) |
| `--text-brand` | `#83513E` (caramel-700) |

**Surface**

| Token | Giá trị | Dùng cho |
|---|---|---|
| `--surface-0` | `#FDF8F3` | Nền trang toàn app |
| `--surface-1` | `#FFFFFF` | Card |
| `--surface-2` | `#FFFFFF` | Panel, bottom sheet |
| `--surface-3` | `#FFFFFF` | Popover, modal |
| `--surface-warm` | `#F6DFB3` | Vùng nhấn ấm, empty state |

**Border**

| Token | Giá trị |
|---|---|
| `--border` | `#EAE0D6` (neutral-100) |
| `--border-strong` | `#D9C9BB` (neutral-200) |
| `--border-accent` | `#F4A3AF` (rose-300) |

**Fill (bề mặt điều khiển)**

| Token | Giá trị | Chữ đi kèm |
|---|---|---|
| `--fill-accent` | `#F28AA1` | `--on-accent` = `#3D2A20` |
| `--fill-accent-hover` | `#E0758E` | `#3D2A20` |
| `--fill-brand` | `#83513E` | `#FDF8F3` |
| `--fill-brand-hover` | `#603A2C` | `#FDF8F3` |
| `--fill-disabled` | `#EAE0D6` | `--text-disabled` |

**Background tint (nền thông tin)**

| Token | Giá trị | Chữ đi kèm |
|---|---|---|
| `--bg-accent` | `#FAD6D3` | `#9E3A52` |
| `--bg-brand` | `#F6DFB3` | `#83513E` |

**Phân biệt fill và bg:** `fill-*` là màu đậm cho bề mặt điều khiển (nút, checkbox, toggle) — đi với chữ tương phản mạnh. `bg-*` là tint nhạt cho nền thông tin (badge, banner, card highlight) — đi với chữ cùng họ ở stop 700.

**Lưu ý ngược trực giác:** chữ trên nút hồng `#F28AA1` phải là nâu đen `#3D2A20` (≈7:1), không phải trắng (chỉ ≈2.4:1).

### Purpose tokens — DARK

Không đảo ngược cơ học. Palette thiên sáng nên phải định nghĩa lại.

| Token | Hex |
|---|---|
| `--surface-0` | `#1A1210` |
| `--surface-1` | `#241A16` |
| `--surface-2` | `#2D211C` |
| `--surface-3` | `#362822` |
| `--surface-warm` | `#3A2A1E` |
| `--text-primary` | `#F5E9DE` |
| `--text-secondary` | `#C4B0A0` |
| `--text-muted` | `#94806F` |
| `--text-disabled` | `#6B5A4D` |
| `--text-accent` | `#F7BCBE` |
| `--text-brand` | `#EFCB93` |
| `--border` | `#3D2E27` |
| `--border-strong` | `#4F3C33` |
| `--border-accent` | `#7A2A3D` |
| `--fill-accent` | `#F28AA1` (giữ nguyên) |
| `--on-accent` | `#3D2A20` |
| `--fill-brand` | `#B87548` (sáng hơn light mode — Bole biến mất trên nền tối) |
| `--bg-accent` | `#5A2333` |
| `--bg-brand` | `#4A3524` |

Semantic dark: fill giữ nguyên; bg đổi sang `#1F3527` / `#3D1E1B` / `#3A2C14`; text đổi sang `#8FCBA3` / `#F0A09A` / `#EBC77E`.

### Ràng buộc màu

1. **Tương phản tối thiểu 4.5:1** chữ thường, 3:1 chữ ≥18px. Kiểm tra cả hover và disabled.
2. **Không ghép hai stop cùng vùng sáng.** Chữ trên tint phải dùng stop 700+ của cùng ramp.
3. **Tối đa 1 điểm nhấn màu bão hoà mỗi màn hình.**
4. **Tối đa 3 màu brand xuất hiện đồng thời.**
5. **Màu không được là kênh thông tin duy nhất** — trạng thái phải kèm icon hoặc chữ.
6. **Đặt tên token theo vai trò**, không theo màu.
7. **`caramel-300` (Fawn) chỉ trang trí** — icon phụ, divider, viền. Không đặt chữ lên nó.

### Gradient

**Được phép:** landing/onboarding, nền một card điểm nhấn duy nhất, overlay trên ảnh/video preview để chữ nổi lên.

**Không dùng cho:** nền toàn app, nút bấm, bất kỳ nền nào chứa text dài.

**Nếu dùng:** cùng họ màu, chênh lệch nhỏ. An toàn: `#FAD6D3 → #F6DFB3`. Tránh: `rose-400 → caramel-700`.

---

## 4. Spacing

Thang 4px. Chỉ dùng các bậc sau, không dùng giá trị lẻ.

| Token | px | Dùng cho |
|---|---|---|
| `space-1` | 4 | Khoảng cách icon–text |
| `space-2` | 8 | Trong component (padding nút nhỏ) |
| `space-3` | 12 | Giữa các dòng liên quan |
| `space-4` | 16 | Padding card, gap list item |
| `space-5` | 20 | Padding ngang màn hình (mobile) |
| `space-6` | 24 | Giữa các nhóm nội dung |
| `space-8` | 32 | Giữa các section |
| `space-10` | 40 | Trên/dưới hành động chính |
| `space-12` | 48 | Khoảng thở lớn (landing, xác nhận) |

**Nguyên tắc:** khoảng cách giữa các nhóm phải lớn hơn khoảng cách trong nhóm. Nếu hai phần tử cách nhau bằng nhau, mắt không phân biệt được nhóm.

---

## 5. Corner radius

| Token | px | Dùng cho |
|---|---|---|
| `radius-sm` | 8 | Nút, input, checkbox, badge |
| `radius-md` | 12 | Card, panel |
| `radius-lg` | 20 | Preview ảnh/video, modal |
| `radius-full` | 999 | Avatar, progress bar, pill tag |

Bo tròn vừa phải hợp với Quicksand. Không dùng radius lớn hơn 20px cho card — sẽ trượt sang cảm giác "trẻ con".

---

## 6. Elevation & Border

**Không dùng shadow** cho card và panel. Phân lớp bằng chênh lệch nền + hairline.

| Lớp | Cách thể hiện |
|---|---|
| Nền trang | `--surface-0` `#FDF8F3` |
| Card | `--surface-1` `#FFFFFF` + `0.5px solid var(--border)` |
| Bottom sheet / Panel | `--surface-2` + border-top |
| Popover / Modal | `--surface-3` + shadow nhẹ `0 8px 24px rgba(61,42,32,0.12)` |

Shadow **chỉ** dùng cho popover và modal. Tối đa 2 lớp nổi cùng lúc.

Viền mặc định `0.5px`, không dùng 1px trừ khi cần nhấn mạnh. Dùng viền tiết chế — nhiều viền là nguyên nhân chính gây rối mắt.

---

## 7. Motion

**Đây là nơi đầu tư chính của phong cách này.**

| Loại | Duration | Easing |
|---|---|---|
| Micro (hover, press, toggle) | 150ms | `ease-out` |
| Chuyển trạng thái component | 250ms | `cubic-bezier(0.4, 0, 0.2, 1)` |
| Chuyển màn hình | 300ms | `cubic-bezier(0.4, 0, 0.2, 1)` |
| Feedback thành công | 400ms | `ease-out` |

**Nguyên tắc:**

- Không dùng bounce/spring — dễ thành "cute quá đà", lệch với tông tối giản.
- Mọi chuyển động phải có mục đích: cho biết cái gì vừa thay đổi, hoặc cái gì đến từ đâu.
- Tôn trọng `prefers-reduced-motion: reduce` — tắt toàn bộ transition không thiết yếu.
- Progress bar không bao giờ đứng im. Nếu không biết % thật, dùng indeterminate animation.

---

## 8. Iconography

| Thuộc tính | Giá trị |
|---|---|
| Kiểu | Outline (không filled) |
| Stroke width | 1.75px |
| Đầu nét | Bo tròn (round cap, round join) |
| Kích thước | 16 / 20 / 24px — chỉ 3 bậc |
| Màu mặc định | `--text-secondary` |

Filled icon quá nặng so với palette nhạt và font bo tròn. Icon chỉ dùng filled khi biểu thị trạng thái active.

---

## 9. Media

| Thuộc tính | Giá trị |
|---|---|
| Bo góc preview | `radius-lg` 20px |
| Tỷ lệ ưu tiên | 4:5 hoặc 1:1 |
| Placeholder khi loading | Nền `--surface-warm`, không dùng skeleton xám lạnh |
| Overlay trên media | `linear-gradient(transparent, rgba(61,42,32,0.6))` |

Tránh 16:9 — chiếm ít chiều cao trên mobile, lãng phí không gian.

---

## 10. Component conventions

### Button

| Loại | Nền | Chữ | Dùng cho |
|---|---|---|---|
| Primary | `--fill-accent` | `--on-accent` | Hành động chính duy nhất mỗi màn |
| Secondary | `--surface-1` + border | `--text-primary` | Hành động phụ |
| Ghost | trong suốt | `--text-secondary` | Huỷ, quay lại |
| Destructive | `error.fill` | `#FFFFFF` | Xoá, huỷ gửi |

Chiều cao: 44px (mobile) / 40px (desktop). Radius `radius-sm`. Font `label` weight 600.

### Input

Nền `--surface-1`, viền `--border`, focus đổi viền sang `--border-accent` + ring `0 0 0 3px rgba(242,138,161,0.2)`. Chiều cao 44px. Label luôn hiện phía trên, không dùng placeholder thay label.

### States bắt buộc thiết kế

Mọi component tương tác phải có đủ: `default`, `hover`, `focus-visible`, `active`, `disabled`, `loading`, `error`.

`focus-visible` bắt buộc có ring rõ ràng — không được `outline: none` mà không thay thế.

---

## 11. Ưu tiên polish

Xếp theo mức ảnh hưởng tới cảm nhận chất lượng:

1. **Trạng thái upload/xử lý** — người dùng nhìn lâu nhất. Phải phân biệt rõ từng giai đoạn (đang nén ≠ đang tải lên), có ước lượng thời gian, không bao giờ đứng im.
2. **Màn hình xác nhận đã gửi** — điểm cảm xúc cao nhất. Dancing Script, animation, palette được phép toả sáng ở đây.
3. **Empty state và error state** — với app xử lý file, lỗi xảy ra thường xuyên (file quá lớn, sai định dạng, mất mạng). Error state tử tế nâng cảm giác chất lượng rất nhiều.
4. **Drag & drop / chọn file** — tương tác đầu tiên, tạo ấn tượng ban đầu.
5. **Preview** — cho người gửi thấy trước quà sẽ trông thế nào.

---

## 12. Triển khai

### Figma

- Text Styles theo 7 token, tách `Mobile/` và `Desktop/`.
- Color Variables 2 lớp: lớp ramp (`rose/400`) và lớp purpose (`text/primary`) alias tới ramp.
- 2 mode `Light` / `Dark` — chỉ lớp purpose có 2 mode, lớp ramp giữ nguyên.
- Variables cho spacing và radius.
- Không tạo layer nào không gắn Style/Variable.
- Bật Vietnamese subset khi load Google Fonts.

### Coding agent

- Toàn bộ token trong một file theme duy nhất. Không hardcode hex/px trong component.
- Component chỉ tham chiếu purpose token (`--text-primary`, `--fill-accent`), không tham chiếu ramp stop (`--rose-400`).
- Dark mode override purpose token dưới `[data-theme="dark"]` và `@media (prefers-color-scheme: dark)`.
- `font-variant-numeric: tabular-nums` cho mọi element hiển thị số liệu, dung lượng, thời lượng, %.
- Viền mặc định `0.5px solid var(--border)`.
- Container chính: `max-width: 480px; margin: 0 auto;`.
- Hỗ trợ `prefers-reduced-motion`.

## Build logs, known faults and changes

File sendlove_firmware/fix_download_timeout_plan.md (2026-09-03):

# Kế hoạch Khắc phục Lỗi Download Message Bị Đứng 10% và Timeout

## 1. Mô tả Vấn đề & Triệu chứng

Trên thiết bị Sendlove Box (ESP32-C3), khi có tin nhắn media mới (video/ảnh từ Firebase Storage), quá trình tải xuống gặp lỗi lặp đi lặp lại:
- Thiết bị bắt đầu tải được khoảng **10% đầu tiên** (tương đương khoảng 100KB - 220KB của file 2.2MB).
- Ngay sau đó, tiến trình dừng lại hoàn toàn ("đứng hình"), không nhận thêm byte nào.
- Sau đúng 10 giây, log báo lỗi: `[NET] dl STALL ...` và `[NET] DL err: ... (discarded)`.
- Tin nhắn không được cập nhật timestamp NVS (`[NET] ts fail`), khiến thiết bị liên tục thử tải lại tin nhắn này mỗi khi thức dậy hoặc sau chu kỳ đồng bộ 10s, tạo thành vòng lặp lỗi vô tận.

---

## 2. Phân Tích Nguyên Nhân Gốc Rễ (Root Cause Analysis)

Qua việc rà soát toàn bộ luồng mạng (`NetworkManager.cpp`), driver Flash NAND (`NandStorageProvider.cpp`, `NandStorage.cpp`), và kiến trúc TCP/TLS của ESP32 lwIP/mbedTLS, chúng tôi đã xác định được **5 nguyên nhân tương hỗ** dẫn đến lỗi này:

```mermaid
sequenceDiagram
    autonumber
    participant App as Sendlove Firmware
    participant Flash as NAND W25Q128
    participant TCP as ESP32 lwIP/mbedTLS
    participant CDN as Firebase Storage CDN

    App->>CDN: HTTP GET (URL media .bin)
    CDN-->>App: 200 OK (Content-Length: ~2.2MB)
    Note over CDN,TCP: CDN bắt đầu đẩy gói tin TCP với tốc độ cao
    TCP-->>TCP: Đệm nhận TCP (5.7KB) & mbedTLS đầy
    App->>Flash: openForWrite() -> eraseRange(5.5MB)
    Note over App,Flash: ĐÓNG BĂNG CPU 15-25 GIÂY<br/>Xóa 85 block 64KB đồng bộ!
    TCP-->>CDN: TCP Zero-Window (win=0, quá tải)
    CDN-->>CDN: CDN tạm dừng, kích hoạt Persist Probe Timer
    Note over App,Flash: 25 giây sau: Erase xong!
    App->>TCP: Đọc dữ liệu đã đệm sẵn (buffer 256B, 1 byte/lần)
    Note over App: Tải được ~10% (dữ liệu đệm cũ trước khi nghẽn)
    Note over TCP: Hết sạch dữ liệu đệm, stream->available() = 0
    Note over App: Chờ CDN gửi tiếp... nhưng CDN đang Backoff
    Note over App: Sau 10s: DOWNLOAD_STALL_TIMEOUT_MS kích hoạt!
    App->>App: Báo lỗi STALL -> Huỷ phiên tải (discardWrite)
```

### Nguyên nhân 1: Xóa toàn bộ 5.5MB Flash đồng bộ ngay sau khi mở kết nối (Thủ phạm chính)
- Trong [`NetworkManager.cpp`](file:///P:/coddd/sendove-box/sendlove_firmware/lib/NetworkManager/NetworkManager.cpp#L1000-L1020), thứ tự thực thi hiện tại:
  1. `http.GET()` gửi yêu cầu lên Firebase Storage.
  2. Server phản hồi `HTTP_CODE_OK` (200), socket kết nối thành công và bắt đầu stream dữ liệu.
  3. Code gọi `storage->openForWrite(writeSlotId)`.
- Trong [`NandStorageProvider.cpp:125`](file:///P:/coddd/sendove-box/sendlove_firmware/lib/Storage/NandStorageProvider.cpp#L125):
  ```cpp
  _nand.eraseRange(NAND_SLOT_ADDRS[_activeSlot], _slotCapacity);
  ```
  `_slotCapacity` là dung lượng trọn vẹn 1 slot = **5,570,560 bytes (~5.5MB)** (85 block 64KB).
- Mỗi block 64KB mất 150ms - 400ms để xóa. Tổng thời gian xóa 85 block mất từ **15 đến 25 giây**! Trong suốt thời gian này, hàm `waitBusyInternal()` liên tục thăm dò thanh ghi trạng thái SPI trong vòng lặp bận.
- **Hậu quả mạng**: Trong 15-25 giây này, socket TCP đã mở nhưng firmware không hề gọi `read()`. Bộ đệm TCP của ESP32 (`CONFIG_LWIP_TCP_WND_DEFAULT = 5760` bytes) và mbedTLS lập tức bị đầy ứ. lwIP gửi gói tin TCP `Window: 0` (Zero Window). Google CDN buộc phải dừng truyền và chuyển sang cơ chế TCP Persist Probe (thăm dò cửa sổ với thời gian chờ cấp số nhân: 1s, 2s, 4s, 8s, 16s...).

### Nguyên nhân 2: Tại sao luôn đứng lại ở mốc "khoảng 10%"?
- Khi lệnh xóa 5.5MB kết thúc sau 20-25 giây, firmware bắt đầu vào vòng lặp tải `while (http.connected())`.
- Firmware đọc lượng dữ liệu **đã nằm sẵn trong bộ đệm mạng** của ESP32 trước đó. Lượng dữ liệu này chiếm khoảng **10% - 20%** dung lượng file (khoảng 100KB - 220KB).
- Sau khi đọc hết lượng dữ liệu đệm này, `stream->available()` trở về `0`.
- Phía Google CDN lúc này đang ở trạng thái Persist Backoff hoặc kết nối socket đã bị đứt gãy ngầm do thời gian nghẽn 25s quá lâu. Phải mất nhiều giây CDN mới gửi lại gói probe.

### Nguyên nhân 3: Timeout Stall quá ngắn (10 giây)
- Hằng số `DOWNLOAD_STALL_TIMEOUT_MS = 10000` (10 giây) trong [`NetworkManager.cpp:430`](file:///P:/coddd/sendove-box/sendlove_firmware/lib/NetworkManager/NetworkManager.cpp#L430):
  ```cpp
  if (millis() - lastProgressMs > DOWNLOAD_STALL_TIMEOUT_MS) {
      DLOG("[NET] dl STALL %d/%d", totalRead, initialLen);
      writeError = true;
      break;
  }
  ```
- Khi `stream->available()` trả về 0 sau khi hết buffer 10%, firmware đếm ngược 10 giây. Do Google CDN chưa kịp cấp lại dữ liệu, bộ đếm 10 giây lập tức nổ, đánh dấu `writeError = true` và hủy phiên tải.

### Nguyên nhân 4: Cổ chai đọc dữ liệu 1 byte/lần và kích thước Buffer 256 bytes
- `uint8_t buffer[256]` quá nhỏ so với kích thước gói tin mạng (1436 bytes) và bản ghi TLS (lên tới 16KB).
- `stream->readBytes(buffer, toRead)` trong Arduino Core gọi `Stream::readBytes()` kế thừa từ `Stream.cpp`. Hàm này gọi `timedRead()` đọc **từng byte một**!
  Mỗi byte tốn 4 lời gọi hàm qua mbedTLS (`WiFiClientSecure::read` -> `available` -> `data_to_read` -> `mbedtls_ssl_read`). Đối với file 2.2MB, hệ thống phải thực hiện **hơn 8.8 triệu lời gọi hàm** trên CPU đơn nhân 160MHz của ESP32-C3!
- Cứ sau mỗi 256 bytes đọc được, code lại gọi `delay(1)`. Trên ESP32 FreeRTOS (`CONFIG_FREERTOS_HZ = 100`), `delay(1)` tương đương `vTaskDelay(0)` (không ngủ, quay vòng 100% CPU khi `sizeAvail == 0`, bỏ đói luồng mạng lwIP) hoặc trễ 10ms nếu tick trùng nhịp, khiến tốc độ tải tụt xuống chỉ còn ~20 KB/s.

### Nguyên nhân 5: Wi-Fi Modem Sleep gây trễ gói tin
- Mặc định Wi-Fi trên Arduino ESP32 bật chế độ Modem Sleep (`WIFI_PS_MIN_MODEM`). Khối RF định kỳ tắt giữa các khung beacon DTIM, làm gia tăng tỷ lệ trễ hoặc mất gói tin TCP Window Update trong quá trình tải luồng tốc độ cao.

---

## 3. Đánh Giá An Toàn RAM & Bộ Nhớ Khi Nâng Buffer Lên 2048 Bytes (2 KB)

> [!IMPORTANT]
> **Khẳng định chắc chắn: Việc nâng buffer từ 256 bytes lên 2048 bytes (2 KB) HOÀN TOÀN AN TOÀN và TUYỆT ĐỐI KHÔNG LÀM TRÀN RAM khi tải.**

1. **Bản chất Streaming Cuốn Chiếu (Constant Memory Footprint - Không tích lũy dữ liệu)**:
   - Buffer này hoạt động như một **"chiếc gàu múc nước"**, không phải là nơi chứa toàn bộ file.
   - Luồng chạy: Múc 2048B từ socket mạng -> Ghi đè ngay lập tức vào chip Flash NAND W25Q128 -> Tái sử dụng lại đúng 2048B đó cho lượt đọc tiếp theo.
   - **Dù file media nặng 1MB, 2.2MB hay 10MB**, dung lượng RAM tiêu thụ **luôn là hằng số cố định duy nhất (2 KB)**, hoàn toàn không tăng thêm theo kích thước file tải về.

2. **Ngân sách Stack của Task `WakeSync`**:
   - Tiến trình tải chạy trên FreeRTOS background task `WakeSync` được cấp phát stack: **12,288 bytes (12 KB)** (tại [`NetworkManager.cpp:459`](file:///P:/coddd/sendove-box/sendlove_firmware/lib/NetworkManager/NetworkManager.cpp#L459)).
   - Mức tiêu thụ stack hiện tại của hàm `checkAndDownloadNewMessages()` là ~2.5 KB.
   - Khi dùng buffer **2048 bytes (2 KB)**: Stack chỉ tiêu thụ ~4.3 KB, vẫn còn **dư an toàn gần 8 KB**.
   - Hoàn toàn nằm sâu trong vùng an toàn của FreeRTOS, không có rủi ro Stack Overflow.

3. **Ngân sách Heap RAM của ESP32-C3**:
   - Ở trạng thái `STATE_STANDBY` (khi đang tải tin nhắn): Buffer giải mã video `_jpegBuffer` (32 KB) **đã được giải phóng hoàn toàn** (`free()`).
   - Tổng Free Heap ở Standby đạt **~130 KB - 140 KB** (trên tổng ~200 KB heap khả dụng của ESP32-C3).
   - Tiến trình TLS Handshake của mbedTLS chỉ tiêu thụ ~35 KB - 40 KB động.
   - Trong suốt quá trình tải, Free Heap luôn duy trì ở mức **~90 KB - 100 KB**.
   - Do đó, 2 KB buffer chỉ chiếm chưa tới **2%** lượng RAM nhàn rỗi hiện có.

4. **Tác động tích cực đến mbedTLS & TCP Window**:
   - Việc đọc cả khối 2KB giúp giải phóng nhanh bộ đệm mạng của mbedTLS và lwIP TCP, giữ cho TCP Receive Window luôn rộng mở, ngăn chặn triệt để tình trạng TCP Zero-Window gây đứt luồng kết nối.

---

## 4. Giải Pháp Kiến Trúc Đề Xuất

### Giải pháp 1: Cơ chế Erase cuốn chiếu (Incremental Block Erase 64KB)
Thay vì xóa toàn bộ 5.5MB (~85 block 64KB, mất 25 giây) trong `openForWrite()`, ta chuyển sang cơ chế xóa cuốn chiếu:
1. Trong `NandStorageProvider::openForWrite()`: Chỉ xóa duy nhất **1 block 64KB đầu tiên** tại địa chỉ bắt đầu slot.
   - Thời gian xóa: **~150ms** (nhanh gấp **160 lần** so với 25 giây).
   - Socket mạng không bị nghẽn, Google CDN tiếp tục truyền dữ liệu mượt mà, không bị Zero-Window.
   - Lưu lại mốc `_erasedUpToAddr = slotStartAddr + 65536U`.
2. Trong `NandStorageProvider::writeChunk()`:
   - Khi con trỏ ghi `_writeOffset + len` sắp vượt qua `_erasedUpToAddr`, hệ thống tự động xóa block 64KB tiếp theo.
   - Mỗi lần xóa chỉ mất 150ms một lần sau mỗi 64KB dữ liệu tải về, hoàn toàn không gây timeout mạng.
   - Tiết kiệm 60-70% số chu kỳ xóa/ghi Flash (Wear Leveling), chỉ xóa đúng số block cần thiết thay vì xóa thừa 3.5MB.
3. Đồng bộ tương tự cho `openForAppend()` khi ghi audio nối tiếp.

### Giải pháp 2: Nâng cấp Buffer lên 2048B & Dùng `stream->read()` đọc theo khối
1. Tăng kích thước buffer tải trong `NetworkManager.cpp` từ 256B lên **2048B (2 KB)**.
2. Thay thế `stream->readBytes(buffer, toRead)` bằng `stream->read(buffer, toRead)`:
   - Đọc trực tiếp cả khối 2KB từ buffer mbedTLS chỉ bằng **1 lời gọi hàm** thay vì 2048 lần lặp byte-by-byte.
   - Giảm 99% tải CPU cho ESP32-C3.
3. Ghi vào Flash qua `storage->writeChunk(buffer, c)`: `NandStorage::writeRaw()` đã có sẵn vòng lặp chia page 256B, sẽ tự động ghi 8 page liên tục trong **1 phiên SPI duy nhất** (tiết kiệm 8 lần acquire/release SPI mutex).
4. Tốc độ tải dự kiến tăng từ **20 KB/s lên ~600 - 800 KB/s** (file 2.2MB tải xong trong **3 - 4 giây** thay vì hơn 100 giây).

### Giải pháp 3: Kiểm soát Luồng và Điều tiết Task Delay chuẩn xác
- Khi có dữ liệu (`c > 0`): **Không delay**, tiếp tục vòng lặp để hút sạch dữ liệu từ socket, giữ TCP Window luôn mở rộng tối đa.
- Khi không có dữ liệu (`stream->available() == 0`): Gọi `vTaskDelay(pdMS_TO_TICKS(10))` (nghỉ 10ms) để nhường hoàn toàn CPU cho FreeRTOS Scheduler, luồng `tiT` (lwIP TCP/IP) và driver Wi-Fi nhận các gói tin mới từ router.

### Giải pháp 4: Nâng thời gian Timeout Stall lên 30 giây
- Tăng `DOWNLOAD_STALL_TIMEOUT_MS` từ `10000` (10s) lên `30000` (30 giây), đồng bộ với `http.setTimeout(30000)`.
- Giúp thiết bị chống chịu tốt với độ trễ mạng Wi-Fi thực tế mà không bị ngắt ngang xương.

### Giải pháp 5: Vô hiệu hóa Modem Sleep trong suốt quá trình Download
- Khi bắt đầu tải media: `WiFi.setSleep(false)` (giữ RF luôn bật ở chế độ hiệu năng cao nhất, không bỏ lỡ gói tin).
- Khi kết thúc tải (thành công hoặc thất bại): `WiFi.setSleep(true)` (khôi phục tiết kiệm điện).

### Giải pháp 6: Tách biệt phiên `HTTPClient` Video và Audio
- Gọi `http.end()` của luồng video ngay khi tải xong video, TRƯỚC KHI bắt đầu gọi `downloadVoiceSegment()`.
- Tránh việc hai phiên HTTP lồng nhau chia sẻ cùng một đối tượng `WiFiClientSecure` khi socket cũ chưa đóng hoàn toàn.

---

## 5. Chi Tiết Thay Đổi Code Cụ Thể (Proposed Changes)

### Component: Storage Provider (`lib/Storage/`)

#### [MODIFY] [`lib/Storage/NandStorageProvider.h`](file:///P:/coddd/sendove-box/sendlove_firmware/lib/Storage/NandStorageProvider.h)
- Thêm biến thành viên theo dõi địa chỉ đã được xóa: `uint32_t _erasedUpToAddr = 0;`

```cpp
    int8_t _activeSlot = 0;
    uint32_t _writeOffset = 0;
    uint32_t _slotCapacity = 0;
    uint32_t _erasedUpToAddr = 0; // Mốc địa chỉ vật lý đã được xóa (Erase cuốn chiếu)
```

#### [MODIFY] [`lib/Storage/NandStorageProvider.cpp`](file:///P:/coddd/sendove-box/sendlove_firmware/lib/Storage/NandStorageProvider.cpp)
1. Trong `openForWrite()`:
```cpp
    _activeSlot = slot;
    _writeOffset = 4;
    _slotCapacity = slotSpan(slot);

    // Erase cuốn chiếu: chỉ xóa 1 block 64KB đầu tiên (~150ms thay vì 25s cho toàn bộ 5.5MB)
    uint32_t slotStartAddr = NAND_SLOT_ADDRS[_activeSlot];
    uint32_t initialEraseLen = min((uint32_t)65536U, _slotCapacity);
    _nand.eraseRange(slotStartAddr, initialEraseLen);
    _erasedUpToAddr = slotStartAddr + initialEraseLen;

    DLOG("[NANDP] open write slot %d", _activeSlot);
    return true;
```

2. Trong `writeChunk()`:
```cpp
size_t NandStorageProvider::writeChunk(const uint8_t* data, size_t len) {
    if (!data || len == 0) return 0;

    uint32_t slotStartAddr = NAND_SLOT_ADDRS[_activeSlot];
    uint32_t startAddr = slotStartAddr + _writeOffset;
    uint32_t endAddr = startAddr + len;

    if (_slotCapacity == 0 || (uint64_t)_writeOffset + (uint64_t)len > _slotCapacity) {
        DLOG("[NANDP] ERR: write exceed cap");
        return 0;
    }

    // Erase cuốn chiếu: xóa tiếp các block 64KB khi con trỏ ghi chuẩn bị vượt qua vùng đã xóa
    while (_erasedUpToAddr < endAddr && _erasedUpToAddr < slotStartAddr + _slotCapacity) {
        uint32_t toErase = 65536U;
        if (_erasedUpToAddr + toErase > slotStartAddr + _slotCapacity) {
            toErase = slotStartAddr + _slotCapacity - _erasedUpToAddr;
        }
        _nand.eraseRange(_erasedUpToAddr, toErase);
        _erasedUpToAddr += toErase;
    }

    _nand.writeRaw(startAddr, data, len);
    _writeOffset += len;

    return len;
}
```

3. Trong `openForAppend()`:
```cpp
    _activeSlot   = slot;
    _writeOffset  = _lastWrittenOffset;
    _slotCapacity = slotSpan(slot);

    // Vùng đã xóa trước đó trong phiên ghi video: được làm tròn lên ranh giới 64KB tiếp theo
    uint32_t slotStartAddr = NAND_SLOT_ADDRS[_activeSlot];
    uint32_t currentPos = slotStartAddr + _writeOffset;
    _erasedUpToAddr = ((currentPos + 65535U) / 65536U) * 65536U;
    if (_erasedUpToAddr > slotStartAddr + _slotCapacity) {
        _erasedUpToAddr = slotStartAddr + _slotCapacity;
    }
```

4. Trong `discardWrite()`:
```cpp
    _writeOffset = 0;
    _slotCapacity = 0;
    _erasedUpToAddr = 0;
```

---

### Component: Network & HTTP Download (`lib/NetworkManager/`)

#### [MODIFY] [`lib/NetworkManager/NetworkManager.cpp`](file:///P:/coddd/sendove-box/sendlove_firmware/lib/NetworkManager/NetworkManager.cpp)
1. Tăng timeout stall lên 30 giây:
```cpp
static const uint32_t DOWNLOAD_STALL_TIMEOUT_MS = 30000;
static const size_t DOWNLOAD_CHUNK_SIZE = 2048;
```

2. Tối ưu hóa vòng lặp `checkAndDownloadNewMessages()`:
- Bật `WiFi.setSleep(false)` khi bắt đầu tải và `WiFi.setSleep(true)` khi kết thúc.
- Nâng `uint8_t buffer[DOWNLOAD_CHUNK_SIZE]` (2048 bytes).
- Đọc theo khối bằng `stream->read(buffer, toRead)`.
- Chỉ delay `vTaskDelay(pdMS_TO_TICKS(10))` khi `sizeAvail == 0`.
- Gọi `http.end()` trước khi gọi `downloadVoiceSegment()`.

3. Áp dụng các tối ưu tương tự cho `downloadVoiceSegment()`:
- Dùng `uint8_t abuf[DOWNLOAD_CHUNK_SIZE]` (2048 bytes).
- Dùng `aStream->read(abuf, tr)`.
- Chỉ delay khi `av == 0`.

---

## 6. Kế hoạch Kiểm Thử & Xác Minh (Verification Plan)

> [!NOTE]
> Theo **Session Rule (2026-09-02)** ghi trong `MEMORY.md`: Agent **không tự chạy lệnh build PlatformIO (`pio run`)** để tiết kiệm tài nguyên. Việc build, nạp và test trên máy thật sẽ do User đảm nhiệm sau khi duyệt kế hoạch.

### Các bước kiểm thử trên máy thật:
1. **Kiểm tra thời gian mở slot (`open write slot`)**:
   - Quan sát log màn hình / serial: Thời gian từ khi `[NET] GET OK` đến khi `[NET] writing slot` giảm từ ~20-25 giây xuống còn **dưới 0.5 giây**.
2. **Kiểm tra tiến độ tải (`[NET] dl X/Y`)**:
   - Tiến độ tải nhảy đều đặn: `16KB -> 64KB -> 200KB -> 500KB -> 1MB -> 2.2MB` mà không bị khựng lại ở 10%.
   - Tổng thời gian tải file 2.2MB giảm từ >100s (thất bại) xuống còn **khoảng 3 - 5 giây** (thành công 100%).
3. **Kiểm tra cập nhật Timestamp (`[NET] TS updated`)**:
   - Tải xong hiển thị `[NET] DL OK`, timestamp được lưu vào NVS, không còn bị lặp lại lỗi tải ở chu kỳ sau.
4. **Kiểm tra phát lại Media (`MediaPlayer`)**:
   - Sau khi tải xong, hộp phát video và âm thanh mượt mà từ đầu đến cuối, không bị lỗi `Bad jpegSize` hay mất tiếng.

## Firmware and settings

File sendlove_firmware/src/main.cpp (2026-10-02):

#include "AlarmClock.h"
#include "ConfigManager.h"
#include "DisplayDriver.h"
#include "IStorageProvider.h"
#include "NandStorageProvider.h"
#include "SDStorageProvider.h"
#include "LayoutEngine.h"
#include "MediaPlayer.h"
#include "NetworkManager.h"
#include "OtaHandler.h"
#include "PowerManager.h"
#include "ScreenLogger.h"
#include "UIController.h"
#include "Settings.h"
#include "SdLog.h"
#include "SdStore.h"
#include "MusicStore.h"
#include "ThemeStore.h"
#include "config.h"
#include <Arduino.h>
#include <SPI.h>
#include <atomic>
#include <esp_ota_ops.h>
#include <esp_timer.h>

// SENDLOVE BOX firmware. Event-driven FreeRTOS tasks:
//   Task_MediaPlayer       — state machine, playback, alarms
//   Task_UIController      — touch sensor, sleep
//   Task_NetworkController — WebServer / captive portal
// TOUCH_OTA_TOGGLE: a 6s hold (TOUCH_OTA_HOLD_MS), the last step of the OTA touch sequence.
enum class SystemEvent : uint8_t { NONE, TOUCH_SHORT, TOUCH_LONG, TIMEOUT_AUTO_NEXT, TOUCH_OTA_TOGGLE };

struct AppContext {
  DisplayDriver display;
  IStorageProvider* storage = nullptr;
  MediaPlayer player;
  UIController ui;
  NetworkManager network;
  LayoutEngine layoutEngine;
  OtaHandler otaHandler;
  PowerManager powerManager;
  ConfigManager configManager;
};

static AppContext appCtx;

static uint32_t lastUserActivity = 0;
static volatile bool forceStandbyRedraw = false;

static SemaphoreHandle_t spiMutex = nullptr;
static QueueHandle_t eventQueue = nullptr;

// A play command waiting for sync to finish (1-slot queue). Set/cleared by
// Task_MediaPlayer; Task_UIController reads it to stay awake.
// Why wait: playback (~74KB) plus a TLS session (35-45KB) don't fit together and
// caused reboots (MEMORY.md §8, §21). Do NOT fold this into isPlaybackActive(): the
// sync would abort without setting _hasPendingMessages.
static std::atomic<bool> s_pendingPlay{false};

// An alarm is ringing WITH MUSIC (continuous card reads). Counts as
// isPlaybackActive() so sync and downloads stop: a card busy writing makes the
// music crackle (mandatory case, MEMORY.md §28). The beep doesn't read the card.
static std::atomic<bool> s_alarmMusicOn{false};

// ---- Rollback after OTA ----
// Returning true stops Arduino from marking the new image VALID at boot; the
// firmware confirms it itself after OTA_VERIFY_DELAY_MS (Task_UIController). A reset
// before that leaves it PENDING_VERIFY and the bootloader falls back to the old image.
// MUST be extern "C": the weak original has C linkage.
extern "C" bool verifyRollbackLater() { return true; }

static volatile bool s_otaPendingVerify = false;

// OTA web server command: +1 start, -1 stop, 0 nothing. Written by Task_MediaPlayer,
// executed by Task_NetworkController: WebServer calls MUST stay on the task running
// handleClient() (stopWebServer() deletes the server -> use-after-free otherwise).
static volatile int8_t s_otaServerCmd = 0;
static esp_timer_handle_t s_otaGuardTimer = nullptr;

// Safety net for a new image that HANGS: rollback needs a reset, and no watchdog
// resets a hung task in this configuration. esp_timer still fires when app tasks are dead.
static void otaGuardFire(void*) { esp_restart(); }

// No Serial: logging goes to the ScreenLogger overlay (no blocking without a USB host).

// STATE_ALARM: ringing; blocks sleep, accepts touches even while downloading.
// STATE_OTA: flashing mode (3s, 3s, 6s hold sequence): no sleep, sync, playback or
// alarms (product decision; the OTA screen reminds the user to exit).
enum class AppState { STATE_STANDBY, STATE_VIDEO, STATE_ALARM, STATE_OTA };

// Shared by 3 tasks, hence atomic. NOT lock-free on the ESP32-C3 (ESP-IDF emulates
// it by disabling interrupts): never touch it from an ISR.
std::atomic<AppState> currentAppState{AppState::STATE_STANDBY};

// The standby theme is not compiled in: it lives in the `theme` flash partition
// (ThemeStore, see MEMORY.md §28). Without one, LayoutEngine draws a black fallback.

void Task_MediaPlayer(void *pvParameters) {
  DLOG("[PLAY] task started");
  char currentId[32] = "";
  uint32_t lastClockRender = 0;
  uint32_t playStartTime = 0;

  if (appCtx.storage && appCtx.storage->getFirstValidIdentifier(currentId, sizeof(currentId))) {
    if (currentAppState == AppState::STATE_VIDEO) {
      appCtx.player.playItem(currentId);
      playStartTime = millis();
    }
  }

  auto drawToast = [](const char* msg) {
      appCtx.layoutEngine.renderStandbyScreen(&appCtx.display, &appCtx.network, true);
      if (appCtx.display.acquireSPI()) {
          appCtx.display.getTFT()->fillRect(0, 200, 240, 40, TFT_BLACK);
          appCtx.display.getTFT()->setTextColor(TFT_WHITE);
          appCtx.display.getTFT()->setTextDatum(lgfx::middle_center);
          appCtx.display.getTFT()->setTextSize(1);
          appCtx.display.getTFT()->drawString(msg, 120, 220);
          appCtx.display.releaseSPI();
      }
  };

  // OTA mode screen. ASCII only (the font has glyphs 32-126).
  auto drawOtaScreen = []() {
      if (!appCtx.display.acquireSPI()) return;
      LGFX* tft = appCtx.display.getTFT();
      char line[48];
      tft->fillScreen(TFT_BLACK);
      tft->setTextDatum(lgfx::middle_center);
      tft->setTextColor(TFT_YELLOW);
      tft->setTextSize(2);
      tft->drawString("CHE DO NAP OTA", 120, 30);
      tft->setTextColor(TFT_WHITE);
      tft->setTextSize(1);
      snprintf(line, sizeof(line), "http://%s.local/", OTA_HOSTNAME);
      tft->drawString(line, 120, 75);
      snprintf(line, sizeof(line), "IP: %s", WiFi.localIP().toString().c_str());
      tft->drawString(line, 120, 95);
      snprintf(line, sizeof(line), "FW %s", FW_VERSION);
      tft->drawString(line, 120, 115);
      if (appCtx.otaHandler.isUpdating()) {
          snprintf(line, sizeof(line), "Dang nap %u%% - dung rut dien", (unsigned)appCtx.otaHandler.progressPercent());
      } else {
          snprintf(line, sizeof(line), "Cho nap...");
      }
      tft->setTextColor(TFT_GREEN);
      tft->drawString(line, 120, 150);
      // The only reminder that alarms are off in this mode.
      tft->setTextColor(TFT_RED);
      tft->drawString("BAO THUC DANG TAT", 120, 190);
      tft->setTextColor(TFT_WHITE);
      tft->drawString("Thoat: giu 3s, 3s, roi 6s", 120, 210);
      appCtx.display.releaseSPI();
  };

  auto enterOtaMode = [&drawOtaScreen, &drawToast]() {
      // OTA is LAN-only: no Wi-Fi, no server.
      if (!appCtx.network.isConnected()) {
          DLOG("[OTA] khong co Wi-Fi -> khong vao che do");
          appCtx.display.turnOn();
          drawToast("OTA: can Wi-Fi");
          vTaskDelay(pdMS_TO_TICKS(1500));
          forceStandbyRedraw = true;
          return;
      }
      appCtx.player.stop();
      s_otaServerCmd = 1;  // picked up by Task_NetworkController within 50ms
      currentAppState = AppState::STATE_OTA;
      appCtx.display.turnOn();
      drawOtaScreen();
      DLOG("[OTA] vao che do: http://%s.local/ %s", OTA_HOSTNAME, WiFi.localIP().toString().c_str());
  };

  auto exitOtaMode = []() {
      // No exit mid-flash (second latch; Task_UIController already swallows touches).
      if (appCtx.otaHandler.isUpdating()) return;
      s_otaServerCmd = -1;
      currentAppState = AppState::STATE_STANDBY;
      forceStandbyRedraw = true;
      lastUserActivity = millis();
      DLOG("[OTA] thoat che do");
  };

  static constexpr const char* ALARM_HINT = "Cham: bao lai 5p - Giu: tat";
  char alarmTime[6] = "";
  AlarmItem ringItem;            // the ringing alarm: music, volume, ramp
  uint32_t alarmStartMs = 0;
  uint32_t lastBeepMs = 0;
  uint32_t lastAlarmPollMs = 0;
  // OTA touch sequence: hold 3s, 3s, then 6s. Not one long hold: the TTP223
  // recalibrates after 7-8s of touch. Only LONGs received in STANDBY or OTA count.
  uint8_t  otaSeqStep = 0;      // 0 idle · 1 first hold done · 2 second hold done (prompt showing)
  uint32_t otaSeqStep2Ms = 0;   // when the second hold completed
  uint32_t otaSeqDeadline = 0;

  // Bottom strip y 200-239 (covers the progress bar area).
  auto drawOtaPrompt = []() {
      if (!appCtx.display.acquireSPI()) return;
      LGFX* tft = appCtx.display.getTFT();
      tft->fillRect(0, 200, 240, 40, TFT_BLACK);
      tft->setTextDatum(lgfx::middle_center);
      tft->setTextSize(1);
      tft->setTextColor(TFT_YELLOW);
      tft->drawString(currentAppState == AppState::STATE_OTA ? "Giu them 6s de THOAT OTA"
                                                             : "Giu them 6s de vao OTA", 120, 214);
      appCtx.display.releaseSPI();
  };

  auto resetOtaSeq = [&otaSeqStep, &drawOtaScreen]() {
      bool hadPrompt = (otaSeqStep == 2);
      otaSeqStep = 0;
      if (!hadPrompt) return;
      if (currentAppState == AppState::STATE_STANDBY) forceStandbyRedraw = true;
      else if (currentAppState == AppState::STATE_OTA) drawOtaScreen();
  };

  // ---- Play command waiting for sync (see s_pendingPlay) ----
  uint32_t pendingPlaySinceMs = 0;
  uint32_t pendingPlayDeadline = 0;
  bool     pendingSawIdle = false;     // sync seen idle since it was last busy
  uint32_t pendingIdleSinceMs = 0;     // see PENDING_PLAY_SETTLE_MS

  // Bottom strip; redrawn by the STANDBY loop after each render, like drawOtaPrompt.
  auto drawPendingHint = []() {
      if (!appCtx.display.acquireSPI()) return;
      LGFX* tft = appCtx.display.getTFT();
      tft->fillRect(0, 200, 240, 40, TFT_BLACK);
      tft->setTextDatum(lgfx::middle_center);
      tft->setTextSize(1);
      tft->setTextColor(TFT_WHITE);
      tft->drawString("Dang dong bo, se tu phat...", 120, 220);
      appCtx.display.releaseSPI();
  };

  // The deadline counts from the FIRST touch.
  auto armPendingPlay = [&pendingPlaySinceMs, &pendingPlayDeadline, &pendingSawIdle]() {
      if (s_pendingPlay) return;
      pendingSawIdle = false;
      pendingPlaySinceMs = millis();
      pendingPlayDeadline = pendingPlaySinceMs + PENDING_PLAY_MAX_WAIT_MS;
      s_pendingPlay = true;
      DLOG("[PLAY] pending: sync dang chay");
  };

  auto cancelPendingPlay = []() {
      if (!s_pendingPlay) return;
      s_pendingPlay = false;
      if (currentAppState == AppState::STATE_STANDBY) forceStandbyRedraw = true;
      DLOG("[PLAY] pending huy");
  };

  // Play the next unread message from STANDBY. fromPending = running the queued command.
  auto startNextUnread = [&currentId, &playStartTime, &drawToast, &armPendingPlay](bool fromPending) {
      char unreadId[32] = "";
      // Ask the STORAGE, not the RAM counter: after a reset while full the counter
      // stays 0 and the box would dead-end (MEMORY.md §23).
      if (appCtx.storage && appCtx.storage->getNextUnreadIdentifier(unreadId, sizeof(unreadId))) {
         // VIDEO before playItem(): blocks a new sync while playback buffers are allocated.
         currentAppState = AppState::STATE_VIDEO;
         appCtx.display.clear();
         strncpy(currentId, unreadId, sizeof(currentId) - 1);
         if (appCtx.player.playItem(currentId)) {
             playStartTime = millis();
         } else {
             DLOG("[PLAY] FAIL -> STANDBY");
             currentAppState = AppState::STATE_STANDBY;
             forceStandbyRedraw = true;
         }
      } else if (appCtx.network.hasPendingMessages()) {
         // The last download stopped for lack of slots; reading freed space, so fetch more.
         DLOG("[PLAY] no local unread, downloading...");
         appCtx.player.stop();
         drawToast("Downloading...");
         uint8_t batPercent = appCtx.powerManager.getBatteryPercentage();
         bool isCharging = appCtx.powerManager.isCharging();
         appCtx.network.triggerFirebaseSync(batPercent, isCharging, appCtx.storage);
         // Auto-play once downloaded — but wait only if a sync really started.
         if (appCtx.network.isSyncing()) {
             // Keep the ORIGINAL deadline: extending it on each failed sync would retry forever.
             if (fromPending) s_pendingPlay = true;
             else armPendingPlay();
         }
      } else {
         appCtx.display.turnOn();
         drawToast("No new messages");
         vTaskDelay(1000);
         forceStandbyRedraw = true;
      }
  };

  for (;;) {
    // Alarms: polled every 500ms in every state, except while ringing or in OTA.
    if (currentAppState != AppState::STATE_ALARM && currentAppState != AppState::STATE_OTA &&
        !appCtx.otaHandler.isUpdating() &&
        millis() - lastAlarmPollMs >= 500) {
      lastAlarmPollMs = millis();
      if (AlarmClock::instance().pollDue(time(nullptr), alarmTime, sizeof(alarmTime), &ringItem)) {
        if (currentAppState == AppState::STATE_VIDEO) appCtx.player.stop();
        currentAppState = AppState::STATE_ALARM;
        // Music if it is on the card; every other case takes ONE branch: the beep.
        s_alarmMusicOn = false;
        if (ringItem.musicId[0] && MusicStore::has(ringItem.musicId)) {
          char musicPath[48];
          MusicStore::pathFor(ringItem.musicId, musicPath, sizeof(musicPath));
          uint8_t startVol = ringItem.ramp ? (uint8_t)(ringItem.volume * ALARM_RAMP_START_PCT / 100)
                                           : ringItem.volume;
          if (appCtx.player.startAlarmMusic(musicPath, startVol)) {
            s_alarmMusicOn = true;
            MusicStore::touch(ringItem.musicId);
          }
        }
        // A touch queued earlier must not dismiss the alarm that just started.
        xQueueReset(eventQueue);
        // Nor may a message auto-play after the alarm is dismissed.
        s_pendingPlay = false;
        // After a timer wake the screen is still off.
        appCtx.display.turnOn();
        // At least ALARM_MIN_BRIGHTNESS: the user's setting may be as low as 5%.
        appCtx.display.setBacklight(Settings::alarmBacklight());
        appCtx.layoutEngine.renderAlarmScreen(&appCtx.display, alarmTime, ALARM_HINT);
        alarmStartMs = millis();
        lastBeepMs = 0;
        lastUserActivity = millis();
      }
    }

    // OTA sequence timeout — but a final hold already in progress may complete.
    if (otaSeqStep != 0 && (int32_t)(millis() - otaSeqDeadline) > 0 &&
        appCtx.ui.getTouchHoldMs() == 0) {
      resetOtaSeq();
    }

    SystemEvent event = SystemEvent::NONE;
    while (xQueueReceive(eventQueue, &event, 0) == pdTRUE) {
      // event loop — no logging here, to avoid spamming the screen

      if (currentAppState == AppState::STATE_ALARM) {
        // Short touch = snooze 5 minutes; 3s hold = dismiss.
        if (event == SystemEvent::TOUCH_SHORT) {
          AlarmClock::instance().snooze(time(nullptr));
          appCtx.layoutEngine.renderAlarmScreen(&appCtx.display, alarmTime, "Bao lai sau 5 phut");
          vTaskDelay(pdMS_TO_TICKS(1500));
        } else if (event == SystemEvent::TOUCH_LONG) {
          AlarmClock::instance().dismiss();
        } else {
          continue;
        }
        // Free the 24KB I2S DMA that beep() keeps between beeps.
        appCtx.player.stop();
        s_alarmMusicOn = false;
        currentAppState = AppState::STATE_STANDBY;
        appCtx.display.setBacklight(Settings::currentBacklight());
        forceStandbyRedraw = true;
        lastUserActivity = millis();
        continue;
      }

      // A hold = the user is done watching. Still falls through to the OTA sequence.
      if (event == SystemEvent::TOUCH_LONG) cancelPendingPlay();

      // ---- OTA touch sequence (see otaSeqStep) ----
      bool otaSeqState = (currentAppState == AppState::STATE_STANDBY ||
                          currentAppState == AppState::STATE_OTA);
      if (event == SystemEvent::TOUCH_LONG && otaSeqState) {
        if (otaSeqStep == 0) {
          otaSeqStep = 1;
          otaSeqDeadline = millis() + OTA_SEQ_STEP_WINDOW_MS;
        } else if (otaSeqStep == 1) {
          otaSeqStep = 2;
          otaSeqStep2Ms = millis();
          otaSeqDeadline = millis() + OTA_SEQ_FINAL_WINDOW_MS;
          drawOtaPrompt();
        }
        // Step 2: the LONG at second 3 of the final hold; keep waiting for 6s.
        continue;
      }
      if (event == SystemEvent::TOUCH_OTA_TOGGLE) {
        // The 6s hold must have started AFTER step 2, or stretching the second hold
        // would shorten the sequence to two steps.
        bool freshHold = (int32_t)((millis() - TOUCH_OTA_HOLD_MS) - otaSeqStep2Ms) > 0;
        if (otaSeqStep == 2 && freshHold && otaSeqState) {
          otaSeqStep = 0;  // enter/exit redraw the screen themselves
          if (currentAppState == AppState::STATE_OTA) exitOtaMode();
          else enterOtaMode();
        }
        continue;
      }
      if (event == SystemEvent::TOUCH_SHORT && otaSeqStep == 2) {
        resetOtaSeq();  // prompt showing: a short touch cancels
        continue;
      }
      if (event == SystemEvent::TOUCH_SHORT) {
        otaSeqStep = 0;  // cancel silently; the touch still works normally
      }
      // OTA mode only accepts the exit sequence above; every other event is ignored.
      if (currentAppState == AppState::STATE_OTA) continue;

      if (event == SystemEvent::TOUCH_SHORT) {
        if (currentAppState == AppState::STATE_STANDBY) {
           if (appCtx.network.isDownloadingMedia()) {
               // Product decision: a touch WHILE DOWNLOADING is ignored, not queued.
               appCtx.player.stop();
               drawToast("Downloading...");
           } else if (appCtx.network.isSyncing()) {
               // Sync may hold a TLS session: queue instead of playing over it.
               armPendingPlay();
               appCtx.display.turnOn();
               drawToast("Dang dong bo, se tu phat...");
           } else {
               startNextUnread(false);
           }
        } else if (currentAppState == AppState::STATE_VIDEO) {
           if (event == SystemEvent::TOUCH_SHORT) {
               appCtx.storage->markAsRead(currentId);
               appCtx.network.decrementNewMsgCount();
           }

           char unreadId[32] = "";
           // Storage, not the RAM counter, is the source of truth.
           if (appCtx.storage && appCtx.storage->getNextUnreadIdentifier(unreadId, sizeof(unreadId))) {
               strncpy(currentId, unreadId, sizeof(currentId) - 1);
               if (appCtx.player.playItem(currentId)) {
                   playStartTime = millis();
               } else {
                   DLOG("[PLAY] FAIL -> STANDBY");
                   currentAppState = AppState::STATE_STANDBY;
                   forceStandbyRedraw = true;
               }
           } else if (appCtx.network.hasPendingMessages()) {
               appCtx.player.stop();
               currentAppState = AppState::STATE_STANDBY;
               drawToast("Downloading...");
               uint8_t batPercent = appCtx.powerManager.getBatteryPercentage();
               bool isCharging = appCtx.powerManager.isCharging();
               appCtx.network.triggerFirebaseSync(batPercent, isCharging, appCtx.storage);
               // Auto-play once downloaded (same condition as startNextUnread).
               if (appCtx.network.isSyncing()) armPendingPlay();
           } else {
               appCtx.player.stop();
               if (appCtx.display.acquireSPI()) {
                   appCtx.display.getTFT()->fillRect(0, 200, 240, 40, TFT_BLACK);
                   appCtx.display.getTFT()->setTextColor(TFT_WHITE);
                   appCtx.display.getTFT()->setTextDatum(lgfx::middle_center);
                   appCtx.display.getTFT()->setTextSize(1);
                   appCtx.display.getTFT()->drawString("Reached newest msg", 120, 220);
                   appCtx.display.releaseSPI();
               }
               vTaskDelay(1500);
               currentAppState = AppState::STATE_STANDBY;
               forceStandbyRedraw = true;
           }
        }
      } else if (event == SystemEvent::TOUCH_LONG || event == SystemEvent::TIMEOUT_AUTO_NEXT) {
        if (currentAppState == AppState::STATE_VIDEO) {
           appCtx.player.stop();
           currentAppState = AppState::STATE_STANDBY;
           forceStandbyRedraw = true;
           lastUserActivity = millis();
        }
      }
    }

    // Queued play command, polled every loop (syncWakeup() has ~12 exits, so no
    // callback). The Wi-Fi setup AP does NOT count as busy (product decision).
    // The PENDING_PLAY_SETTLE_MS pause is COUNTED in the loop: never block this task
    // (and `sleep(2000)` is POSIX sleep in SECONDS).
    if (s_pendingPlay && currentAppState == AppState::STATE_STANDBY) {
      if (appCtx.network.isSyncing()) {
        pendingSawIdle = false;
        if ((int32_t)(millis() - pendingPlayDeadline) > 0) {
          s_pendingPlay = false;
          forceStandbyRedraw = true;
          DLOG("[PLAY] pending het han %lus", (unsigned long)(PENDING_PLAY_MAX_WAIT_MS / 1000));
        }
      } else if (!pendingSawIdle) {
        pendingSawIdle = true;
        pendingIdleSinceMs = millis();
      } else if (millis() - pendingIdleSinceMs >= PENDING_PLAY_SETTLE_MS) {
        s_pendingPlay = false;
        pendingSawIdle = false;
        DLOG("[PLAY] pending fire waited=%lums heap=%u maxblk=%u",
             (unsigned long)(millis() - pendingPlaySinceMs), (unsigned)ESP.getFreeHeap(),
             (unsigned)ESP.getMaxAllocHeap());
        startNextUnread(true);
      }
    }

    // Brightness changed from the web: apply now if the screen is on (the alarm
    // screen keeps its own floor).
    static uint32_t seenBrightnessEpoch = 0;
    if (seenBrightnessEpoch != Settings::brightnessEpoch.load()) {
      seenBrightnessEpoch = Settings::brightnessEpoch.load();
      if (!appCtx.display.isSleeping()) {
        appCtx.display.setBacklight(currentAppState == AppState::STATE_ALARM
                                        ? Settings::alarmBacklight()
                                        : Settings::currentBacklight());
      }
    }
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
void loop() { vTaskDelay(pdMS_TO_TICKS(500)); }

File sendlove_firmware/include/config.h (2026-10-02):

#ifndef CONFIG_H
#define CONFIG_H

#include <Arduino.h>

// Hardware SPI2 Bus (Shared between TFT and NAND Flash)
static constexpr uint8_t PIN_SPI_MOSI = 6;
static constexpr uint8_t PIN_SPI_MISO = 5;
static constexpr uint8_t PIN_SPI_SCK = 4;

// TFT Display (ST7789 240x240 IPS, CS-less)
static constexpr int8_t PIN_TFT_CS = -1;
static constexpr uint8_t PIN_TFT_DC = 7;
static constexpr uint8_t PIN_TFT_RST = 9;
static constexpr uint8_t PIN_TFT_BLK = 3;

static constexpr uint16_t SCREEN_WIDTH = 240;
static constexpr uint16_t SCREEN_HEIGHT = 240;

// NAND Flash W25Q128 (Shared Hardware SPI2)
static constexpr uint8_t PIN_NAND_CS = 8;

// --- Touch Sensor (TTP223) --------------------------------------------------
static constexpr uint8_t PIN_TOUCH = 10; // Active HIGH (INPUT_PULLDOWN)

// Not wired yet: PIN_LED (breathing LED), PIN_BATTERY_ADC + divider.

// Timing & Power Constants
static constexpr uint64_t SLEEP_TIMER_US = 5ULL * 60 * 1000000;
static constexpr uint32_t INACTIVITY_SLEEP_TIMEOUT_MS = 60000; // TODO: Increase to 60000-300000 for production
static constexpr uint32_t WIFI_CONNECT_TIMEOUT_MS = 15000;
// A touch during a sync queues the play command for at most this long (product decision).
static constexpr uint32_t PENDING_PLAY_MAX_WAIT_MS = 60000;
// Idle time required after a sync before the queued command plays (product decision).
static constexpr uint32_t PENDING_PLAY_SETTLE_MS = 10000;

// Display Backlight
static constexpr uint8_t BACKLIGHT_DAY_PERCENT = 100;

// User settings from the web, stored in NVS (they survive a faulty SD card).
// Default volume 100 = the level the box always used (product decision). The "do NOT
// dim the backlight" rule (MEMORY.md §4) doesn't apply to a user-chosen level (§28).
static constexpr uint8_t SETTINGS_DEFAULT_BRIGHTNESS = 100;
static constexpr uint8_t SETTINGS_DEFAULT_VOLUME = 100;
// Brightness floor: at 0 the screen is black and the box looks dead.
static constexpr uint8_t SETTINGS_MIN_BRIGHTNESS = 5;
// Minimum brightness of the alarm screen.
static constexpr uint8_t ALARM_MIN_BRIGHTNESS = 60;
// MAX98357A SD_MODE pin (HIGH = play, LOW = shutdown; used at volume 0).
// -1 = not wired (breadboard). Set to 20 on the PCB (BOM.md).
static constexpr int8_t PIN_AMP_SD = -1;

// Media Playback
static constexpr uint8_t TARGET_FPS = 15;
static constexpr uint32_t FRAME_DURATION_MS = 1000 / TARGET_FPS;

// NAND Slot Config
static constexpr uint8_t NAND_SLOT_COUNT = 3;
static constexpr uint32_t NAND_SLOT_ADDRS[NAND_SLOT_COUNT] = {
    0x010000, 0x560000, 0xAB0000};

// Size cap for one media download: an early exit with a clear log for an endless
// stream or a lying Content-Length. On SD it is the only cap; on NAND writeChunk()
// also stops at the slot capacity (5,570,560 bytes).
static constexpr uint32_t MAX_MEDIA_BYTES = 25500000;

// Firebase configuration (kept in config_secrets.h so keys never reach Git)
#include "config_secrets.h"

static constexpr uint32_t FIREBASE_TIMEOUT_MS = 10000;

// Sync period while awake. Each cycle costs 3 TLS handshakes (~40KB of heap each),
// see MEMORY.md §21. Product decision: 20s.
static constexpr uint32_t SYNC_INTERVAL_MS = 20000;
static constexpr const char *NVS_KEY_LAST_DOWNLOAD_TS = "last_dl_ts";
static constexpr uint8_t MAX_ALARMS = 10;

// Ringing alarm (product decision): touch = snooze 5 min, hold = dismiss, stops after 1 min.
static constexpr uint32_t ALARM_SNOOZE_SEC = 5 * 60;
static constexpr uint32_t ALARM_RING_MAX_MS = 60000;
static constexpr uint32_t ALARM_BEEP_PERIOD_MS = 1000;

// Alarm music (MEMORY.md §28, product decision): 10 tracks, 5-60s, 16 kHz mono (the
// 8 kHz rule is lifted for alarm music ONLY). 60s × 16000 × 2 B fits the 2MB cap;
// do NOT use AUDIO_MAX_PCM_BYTES (the message limit) here.
static constexpr size_t   ALARM_MUSIC_MAX_TRACKS = 10;
static constexpr uint32_t ALARM_MUSIC_MAX_BYTES  = 2000000;
// Per sync cycle; a longer cycle would outlast a queued play command (§27).
static constexpr uint8_t  ALARM_MUSIC_PER_SYNC   = 2;
// Ramp: from 30% of the chosen level to full over 20s.
static constexpr uint32_t ALARM_RAMP_MS          = 20000;
static constexpr uint8_t  ALARM_RAMP_START_PCT   = 30;

// 1 = verify the TLS certificate on every Firebase connection (root CAs in
// firebase_root_ca.h). 0 = setInsecure(): EMERGENCY FALLBACK only, open to MITM.
#define FIREBASE_TLS_VERIFY 1

// 1 = authenticate with the box's own idToken (the `auth.uid === $box_id` rules apply);
// 0 = fall back to the admin Database Secret.
// Set 1 ONLY when all three hold, or the box loses its connection entirely:
//   (a) Email/Password sign-in is enabled in the Firebase Console
//   (b) scripts/provision_box_auth.js was run and BOX_AUTH_* are in config_secrets.h
//   (c) database.rules.json is deployed
#define FIREBASE_USE_IDTOKEN 1
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

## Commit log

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2026-07-26 refector - phase 3: add NVS storage & captive portal provisioning - Save Wi-Fi credentials to NVS - Add Captive Portal setup AP & UI - Prevent sleep while provisioning AP is active
    [config.h, main.cpp]
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2026-07-30 fix: resolve crash when entering sleep while viewing images (SPI/RAM race condition)
    [main.cpp]
2026-08-02 feat: Enhance NandStorage with range erase functionality and improve OTA architecture
    - Added eraseRange method to NandStorage for efficient block and sector erasure.
    - Updated write operations to utilize eraseRange for better performance.
    - Improved error handling and logging in NetworkManager for better debugging.
    - Introduced detailed logging in UIController for touch events and state changes.
    - Implemented a dual-flag OTA architecture for safer firmware updates.
    - Added multi-tap touch algorithm for OTA activation via TTP223.
    - Enhanced main setup process with comprehensive debug output for easier troubleshooting.
    - Created a new documentation file outlining the OTA architecture design.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
    [config.h, main.cpp]
2026-08-02 feat: Update inactivity sleep timeout, enhance NVS logging, and improve media playback error handling
    [config.h, main.cpp]
2026-08-02 feat: Enhance NandStorage and NetworkManager for improved message handling and display time
    - Updated NandStorage to include maxDisplayTime in slot metadata.
    - Modified NetworkManager to sort messages by timestamp and handle max display time for media.
    - Enhanced IStorageProvider interface to support maxDisplayTime during write operations.
    - Implemented new methods in NandStorageProvider and SDStorageProvider for unread message count.
    - Improved UIController to handle touch events for short and long presses.
    - Updated media encoding logic to support new dimensions and duration limits for videos.
    - Added image cropping functionality in ImageInput component for better image handling.
    - Adjuste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
    [main.cpp]
2026-08-02 feat: Enhance media handling and storage efficiency with improved timeout, sorting, and error handling
    [main.cpp]
2026-08-08 feat: Implement ScreenLogger for on-screen logging and replace Serial logging
    - Added ScreenLogger class to handle logging directly to the TFT display.
    - Updated NandStorageProvider to use ScreenLogger for logging instead of Serial.
    - Refactored UIController to utilize ScreenLogger for touch event logging.
    - Removed Serial initialization and related debug prints from main setup.
    - Enhanced Task_MediaPlayer and Task_UIController to log events using ScreenLogger.
    - Adjusted platformio.ini to comment out Serial monitor settings.
    - Improved code readability and maintainability by consolidating logging functionality.
    [config.h, main.cpp]
2026-08-31 feat(backend): box config endpoint, sender message access, lock down rules
    - Add PUT /boxes/:boxId/config for led_state / display_brightness /
    playback_volume, delivered to the device via a new config_flag on the
    existing flag-polling mechanism.
    - requireRole() now accepts an array; GET /messages and GET /messages/:msgId
    are open to sender as well as receiver. Guard against unpaired boxes.
    - database.rules.json: ".read"/".write" were "auth != null || true", which
    always evaluates true and left the Realtime Database open to unauthenticated
    read and write. Set to false; all access goes through the Admin SDK.
    - storage.rules: drop the authenticated-read allowance; signed URLs issued b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
2026-09-01 fixx rẹt rẹt
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2026-09-02 fix: discard failed/stalled downloads instead of committing corrupted slots
    Also drop the "local unread exists -> defer sync" shortcut; always
    check Cloud for new messages unless storage is full.
    [main.cpp]
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2026-09-03 security: bat xac thuc TLS + chuan bi idToken thay Database Secret
    Phase A (da code, CHUA build/flash):
    - include/firebase_root_ca.h: GTS Root R1 (RSA) + R4 (ECC), ban self-signed tu
    pki.goog, han 2036-06-22. Phai co CA HAI vi da do chain that: RTDB ->
    GTS WR1 -> Root R1, firebasestorage -> GTS WE2 -> Root R4.
    - Thay ca 5 cho setInsecure() bang configureTlsClient() -> setCACert().
    Khong dung setCACertBundle(): core 2.0.17 khong nhung san bundle mac dinh.
    - Chot chan thoi gian trong syncWakeup(): VERIFY_REQUIRED gap RTC 1970 se ra
    BADCERT_FUTURE lam moi handshake fail -> retry NTP 15s roi abort co log rieng.
    - Log chan doan lastError() o 6 diem fail + heap sau handshake.
    - Co lui FIRE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
    [config.h]
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2026-09-03 fix: bảng thuộc tính theme không đóng được, xem trước nói dối, lockfile lệch
    ThemeEditor: selectedId khởi tạo 'clock_time' và modal render trên {sel && …},
    nên bảng thuộc tính mở vĩnh viễn — danh sách widget và hàng "Thêm widget" bên
    dưới không bao giờ chạm tới được. Thêm nút đóng đặt selectedId về null.
    ThemePicker: BoxScreen luôn nhận DEFAULT_WIDGETS trong khi nhãn thẻ đọc theo
    giao diện vừa chọn. Bấm "Đồng hồ lớn" thì chữ đổi mà hình không đổi — màn hình
    nói sai. Bố cục thật chỉ đọc được cho giao diện mặc định (defaultLayoutJson),
    hai cái kia chưa tồn t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
2026-09-03 fix: đối chứng lại Figma — appbar, dark mode, Dashboard/Login/PairBox
    Đợt UI phase trước dựng không đối chiếu Figma trực tiếp (MCP hết quota giữa
    chừng) — appbar và Dashboard/Login/PairBox viết từ trí nhớ style guide, không
    từ cây node thật. Đã dùng đúng 1 lượt use_figma (read-only) đọc lại appbar
    thật (create-content-dialog for video/image — frame sender đã được khen "làm
    rất tốt") + 4 frame còn thiếu (login signup, maindashboard-share-page-empty,
    new-box, account-popover).
    Sửa primitive dùng chung (Screen.jsx + sendlove.css) — một chỗ, đúng ở mọi màn:
    .sl-appbar padding [16,20,16,20] gap12,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
2026-09-03 fix: box-card Dashboard gom sai nhóm, sai màu viền, add-box thiếu viền đứt
    Dùng đúng 1 lượt use_figma (read-only) dump lại chi tiết box-card (2 biến
    thể sender/receiver) + add-box-card trong maindashboard-share-page, xác nhận
    byte-for-byte theo phản hồi trực tiếp của người dùng.
    Ba lỗi đã sửa:
    1. Sai nhóm: pill vai trò từng nằm chung nhóm với tên hộp (bên trái). Đúng
    ra pill + chevron GỘP CHUNG một khối, neo bên phải card nhờ
    space-between — khớp left_box-card trong Figma chứa cả hai.
    2. Sai màu viền: trước đây mọi card dùng chung caramel-300. Xác nhận khớp
    tuyệt đối: s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
2026-09-03 fix: rà soát lại 5 màn so với dữ liệu Figma đã lưu — 10 sai lệch
    Đọc lại kỹ 6 file JSON (login-signup, maindashboard-share-page ×2 biến thể,
    new-box, account-popover, box-list-detailed) đối chiếu từng field với code
    hiện tại. Tìm được 10 sai lệch cụ thể, đều có toạ độ Figma làm bằng chứng:
    Login:
    - Logo "SendloveBox" dùng font Dancing Script trong Figma, code cũ để thừa
    hưởng Quicksand — bị gỡ nhầm khỏi index.html ở đợt dọn dẹp trước, thêm lại
    (chỉ riêng logo, không ảnh hưởng phần còn lại của app).
    - .sl-login-logo/.sl-login-terms dùng token đổi theo theme (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
2026-09-03 fix: TypeError messages.map khi mở trang receiver — sai hợp đồng API
    Backend (message.controller.ts:41) trả:
    { success: true, data: { messages: Message[], pagination: {...} } }
    Nhưng api/message.js ghi chú (sai) là `data: Message[]` — mọi nơi gọi
    getMessages() đều tin theo comment đó (setMessages(res.data) rồi .map thẳng),
    nên object {messages, pagination} lọt vào state thay vì mảng.
    Lỗi này CRASH NGAY khi có phản hồi thành công đầu tiên, bất kể có tin nhắn
    hay không (object không có .length nên messages.length === 0 cũng sai, rơi
    thẳng vào nhánh .map()). Không lộ ra trong lúc dev vì backend bị tắt
    (request rejec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
2026-09-03 chore: dọn lint warning (import/biến chết, thiếu dependency)
    4 warning oxlint từng thấy suốt phiên, chưa ai dọn:
    firebase.js: 3 import chết (signInWithPopup/signOut/onAuthStateChanged) —
    còn sót từ trước khi logic auth chuyển hẳn sang api/auth.js.
    mediaUploader.js: biến totalUploadedBytes khai báo rồi bỏ, tiến độ thật
    tính qua fileProgress/currentTotalUploaded ngay bên dưới.
    ErrorBoundary.jsx: tham số error của getDerivedStateFromError không dùng
    trong thân hàm (React không bắt buộc nhận nó nếu không cần).
    VoiceInput.jsx: useEffect thiếu dependency stopRecording — KHÔNG thêm
    thẳng vào m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
2026-09-04 storage: hoan thien SDStorageProvider (20 slot, manifest tren the)
    Ban cu moi la scaffold Phase 3A, KHONG CHAY DUOC. Sua toan bo:
    BUG NGHIEM TRONG NHAT - khong co the = TREO CUNG BOX.
    main.cpp:398-404 chay while(1){delay(100)} khi storage->init() tra false.
    NandStorage::init() KHONG BAO GIO tra false nen nhanh do chua tung chay
    trong doi. SD.begin() thi tra false moi khi the vang/long/khong phai FAT -
    tinh huong BINH THUONG voi the rut duoc. Ban cu tra thang ket qua mount ra
    ngoai. Gio init() LUON tra true, khong mount duoc thi chay che do rong
    (isFull() tra true de he thong khong co tai ve hu khong).
    Cac bug con lai cua ban cu:
    - seek() la HAM RONG, trong khi toan bo duong doc MediaPlayer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
2026-09-04 docs: ghi lai thiet ke tang luu tru the SD (MEMORY.md muc 12)
    Danh so 12 de chua muc 10/11 cho nhanh security-hardening dang viet song
    song - hai nhanh cung append vao cuoi file nay, trung so se thanh xung dot
    dung vung da duoc dan tranh.
    Kem dinh chinh muc 2: con so SPI_MODE3 KHONG bat buoc, cai bat buoc la ca
    bus dung chung mot mode. Giu nguyen dong goc, chi them ghi chu - theo dung
    CLAUDE.md ("sua lai MEMORY.md khi phat hien no ghi sai, danh dau cho sai,
    dung xoa lich su").
    Noi dung muc 12: quyet dinh da chot (20 slot, manifest tren the, MODE0 cho
    SD), bug treo box khi khong co the, bang cac bug cua ban SD cu, chi tiet cai
    dat dang nho, cac huong da can nhac va LOAI (index.bak, dung lai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
2026-09-04 security(B1): log khi bo qua nhay den vi SPI ban + chinh 2 claim sai
    B1 tao ra mot duong that bai im lang: acquireSPI() timeout thi bo qua ca doan
    nhay, ma day la chi bao timer-wake DUY NHAT con lai. Khong log thi trieu chung
    la "flash xong den het nhay" va ket luan tu nhien se la B1 lam hong den. Them
    nhanh else DLOG("[WAKE] blink skip: spi busy"), theo dung idiom san co o
    DisplayDriver.cpp:198.
    Chinh 2 claim sai:
    - Comment B1 ghi "chi phi ~160ms" - thieu phan cho. Xau nhat la 160ms giu
    mutex CONG toi da 1000ms cho (timeout mac dinh cua acquireSPI).
    - MEMORY.md muc 13: uxTaskGetStackHighWaterMark tra ve muc trong thap nhat
    trong TOAN BO doi task, khong phai cua rieng khung showWrappedT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
    [main.cpp]
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2026-09-04 docs: muc 14 - nhat ky truy loi giat video/audio, ghi ro cai da LOAI TRU
    Ghi lai de phien sau khong test lai nhung gi da loai:
    1. Ca 4 thay doi Phase B (B1-B4), tung cai mot voi ly do cu the.
    2. Bug I2S sample rate o muc 9: user da tat nguon han roi bat lai, KHONG het
    giat. Bug do co dac trung "reset la het" nen khong phai thu pham lan nay.
    (Van con nguyen trong code, van can sua, nhung khong lien quan.)
    3. "Revert ve flash 1 van loi" KHONG loai duoc duong ghi - vi 7c1ac23 la CON
    cua eb3c9b2 nen flash 1 cung chua ban ghi 20MHz, va byte hong da nam san
    tren NAND.
    Ghi ca mot phep thu HONG de khong ai dung lai: soi overlay log luc phat de tim
    "Bad jpegSize" la vo dung, vi video da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
2026-09-05 fix: idToken phai di qua ?auth=, RTDB tu choi moi header (muc 17)
    Sua loi chan da do o muc 17: fbAuthQuery() o che do idToken tra chuoi RONG va
    addAuthHeader() gan "Bearer", nhung RTDB tu choi ca Bearer lan Firebase - chi
    nhan ?auth=. Bat FIREBASE_USE_IDTOKEN 1 voi code cu = moi request RTDB tra 401.
    Thay doi:
    - Bo han addAuthHeader() va fbAuthQuery(). Thay bang appendAuth(char sep) noi
    "?auth=<token>" / "&auth=<token>" vao cuoi URL, chay dung o CA HAI che do.
    - Them thanh vien _url[FIREBASE_URL_MAX_LEN=1792] dung chung cho moi request,
    thay cho cac bien cuc bo url[256]/url[384]/authQ[64]. Phai lam vay vi idToken
    ~945 byte nam trong URL; de tren stack thi moi ham ton them ~1.8KB trong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
    [config.h]
2026-09-05 fix: endpoint auth Google tra chunked - doc bang getString khong phai stream tho
    Trieu chung tren may that: "auth: thieu idToken" + "sync abort", KHONG kem
    "signIn fail" (nen POST da tra 200) va KHONG kem "auth JSON err" (nen parse
    khong he loi). Parse thanh cong ma truong token rong - do chinh la manh moi.
    Nguyen nhan: parseAuthResponse() doc qua http.getStreamPtr(), la stream THO
    chua giai ma chunked. Do that:
    identitytoolkit (signInWithPassword) -> Transfer-Encoding: chunked
    securetoken (refresh) -> chunked
    RTDB firebasedatabase.app -> Content-Length
    Voi chunked, stream tho co nguyen dong kich thuoc chunk dang hex truoc JSON
    ("4a1\r\n{...}"). ArduinoJson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
2026-09-05 fix: day slot khong duoc lam ngung heartbeat/co/bao thuc
    Cong "het slot" nam sai cho: no chan CA chu ky sync thay vi rieng buoc tai tin.
    Hai noi:
    main.cpp sync dinh ky 10s : `&& !isStorageFull` trong dieu kien
    main.cpp sync sau wakeup : if (isFull()) DLOG("post-wakeup sync skip: FULL")
    Hau qua: khi 3 slot day, box im hoan toan - mat heartbeat, mat doc co, mat dong
    bo bao thuc, mat OTA va pairing flag. Chi khi mot slot trong ra thi moi chay
    lai, nen trong nhu the "phai co tin moi thi co sync_alarms_flag moi ve false".
    Y dinh ban dau ("day roi thi khoi tai tin cho phi") la dung, nhung dieu kien
    dat o ngoai cung. checkFirebaseFlags() la buoc 4, checkAndDownloadNewMessages()
    la buoc 5 - c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
    [main.cpp]
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2026-09-17 vendor: chep nguyen goc thu vien SD cua framework-arduinoespressif32 vao lib/SD
    Ban sao KHONG SUA GI tu ~/.platformio/packages/framework-arduinoespressif32/
    libraries/SD (version 2.0.0, Apache License 2.0, giu nguyen header ban quyen).
    Tach commit rieng de commit ke tiep cho thay CHINH XAC nhung dong da doi so voi
    upstream - can khi nang cap framework sau nay.
    PlatformIO LDF uu tien lib/ cua project hon thu vien cung ten trong framework
    (da xac nhan bang `pio run -v`: SD @ 2.0.0 resolve ve lib\SD).
2026-09-17 fix(sd): chay thu vien SD o SPI_MODE3, bo huong keo ca bus ve MODE0
    Commit 6c38466 gia dinh sai rang panel ST7789 chay duoc MODE0. Thu tren may
    that 2026-09-17:
    - Ban SD voi bus MODE0 -> man hinh DEN HOAN TOAN (den nen, touch, tieng bip van
    chay). Panel CS-less nay BAT BUOC MODE3; comment goc "Mode 3 (obligatory)" la
    dung tu thuc nghiem.
    - Ep man hinh ve MODE3 nhung thu vien SD van MODE0 -> dung hinh o "Booting..."
    (lat CPOL moi lan truy cap the -> lech khung byte man hinh).
    Sua: doi 2 dong SPI_MODE0 -> SPI_MODE3 trong struct AcquireSPI cua ban sao
    lib/SD (commit truoc la ban goc nen diff nay chinh la phan da doi so voi
    upstream). Moi luu luong SPI cua thu vien di qua struct do.
    SPI_B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
    [config.h]
2026-09-18 feat(alarm): bao thuc keu tren hop + portal AP + dong bo hai chieu
    CHUA FLASH, CHUA TEST MAY THAT (chi qua syntax check bang toolchain that).
    - lib/AlarmClock: giu danh sach + quyet dinh luc nao keu (mutex rieng, 3 task dung).
    - Keu theo so sanh gio, khong theo ESP_SLEEP_WAKEUP_TIMER; chong keu lai bang
    minute-key. Cham ngan = snooze 5', giu 3s = tat, 1 phut khong cham = tu tat.
    - AppState::STATE_ALARM: chan ngu, nhan cham ca khi dang tai tin.
    - Doc dung co a_flag (truoc doc sync_alarms_flag, khong ai ghi - MEMORY.md §20).
    - Reset co TRUOC khi GET alarm_list de khong nuot lan sua xen giua.
    - syncFirebaseAlarms: payload "null" = web da xoa het -> xoa luon trong hop.
    - AlarmItem.id 16 -> 2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
    [config.h, main.cpp]
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2026-09-20 fix: resolve deadlock wait when reset box, count msg variables reset 0 but still full slot
    [config.h, main.cpp]
2026-09-21 feat(fw): che do OTA do nguoi dung kich hoat + rollback that
    - Go duong kich hoat OTA bang co cloud (emergency_ota/normal_ota): khong
    ben nao ghi hai co nay, va cua so 10 phut buoc hop thuc cho mot viec
    co the khong bao gio toi.
    - STATE_OTA rieng: vao/ra bang chuoi cham giu 3s, 3s roi 6s (TTP223 tu
    hieu chuan sau 7-8s cham lien tuc nen khong dung duoc mot cu giu dai).
    Trong che do: chi cho va nap, khong ngu, khong sync, khong bao thuc.
    Dang nap thi chan moi cu cham.
    - Rollback: override verifyRollbackLater(), ban moi phai song 60s moi
    duoc xac nhan; luoi an toan esp_timer reset o giay 90 cho ban bi treo
    (treo khong gay reset nen khong tu rollback). Chan ngu trong 60s thu.
    - Ota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
    [config.h, main.cpp]
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2026-09-22 fix(web): sập thẻ ghi âm/tin tĩnh do TDZ trong VoiceInput
    stopRecording (useCallback) bị đọc trong mảng deps của useEffect trước khi
    khai báo -> ReferenceError khi mount. Lỗi do commit dọn lint b4c84e8.
    Kèm: vòng vẽ waveform đọc ref thay vì state cũ trong closure, dừng thu ở
    effect riêng thay vì trong updater của setTime, đếm đúng tới 15s, revoke
    blob URL, tắt mic khi rời màn giữa chừng.
2026-09-22 fix(web): nút quay lại ở bước chọn loại tin, 'Lịch sử tin nhắn' trỏ đúng màn lịch sử của hộp
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2026-09-22 fix(web): rà soát FE - bỏ trạng thái hộp giả, báo lỗi thay vì im lặng
    - Dashboard: bỏ 'Online / 100%' viết cứng cho mọi hộp; đọc trạng thái thật
    từng hộp (lần đồng bộ suy từ last_seen + % pin). syncTone dùng chung.
    - AuthContext có profileError; Dashboard báo 'chưa tải được danh sách hộp'
    kèm Thử lại, thay vì hiện như tài khoản chưa có hộp nào.
    - ErrorBoundary: bỏ trang chữ đỏ tiếng Anh + stack trace; màn tiếng Việt
    đúng phong cách, 'Tải lại trang' / 'Về trang chủ', chi tiết gập lại.
    - ReceiverAlarms: hiện tên hộp thay vì mã, modal đóng được bằng nền/Esc,
    dùn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
2026-09-22 fix(web): fmtTime làm tròn sai ở mép giây (59.96s hiện 0:59)
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2026-09-22 fix(web): chặn tin quá trần của firmware hiện tại để không kẹt hàng đợi của hộp
    Firmware huỷ tải file > MAX_MEDIA_BYTES (5,5MB) rồi KHÔNG tăng
    last_download_ts ('ts fail' -> break): tin đó bị tải lại mãi, chặn mọi tin
    sau. Giữ trần thời lượng 60s cho hộp SD như đã chốt, nhưng chặn file bin
    vượt trần hộp (status.max_media_bytes nếu firmware báo, không thì 5,5MB)
    trước khi tải lên, kèm gợi ý số giây vừa.
    Tin thoại/nhạc nền kẹp theo trần PCM firmware phát được (600KB = 37s ở
    8kHz) - vượt thì AudioPlayer phát câm.
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2026-09-23 revert(web): trả light theme về đúng giao diện gốc, giữ dark rượu vang
    Người dùng thấy light mới mất chất brand. Light trỏ lại mọi token vai trò về
    giá trị cũ (viền caramel, Tips hồng, chip hồng, thẻ hộp tô theo vai trò,
    neutral-400/500 gốc, toggle giao diện tối caramel). Các chỗ hai theme cần
    khác nhau tách token riêng (--tip-*, --rolepill-*, --boxcard-line-*,
    --chevron-*, --add-*, --shell-line, --toggle-accent-on) nên dark giữ nguyên.
    Kiểm tự động: so từng selector+thuộc tính màu đã giải var() giữa CSS
    65cd60d~1 và hiện tại ở light -> 0 khác biệt (trừ class của mục Cài đặt đã
    ẩ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
2026-09-23 fix(web): bỏ chặn theo trần firmware (5,5 MB, 37s), chỉ giữ trần máy chủ 25 MB
    Firmware sẽ được nâng trần sau; web không giới hạn thay firmware nữa.
2026-09-23 fix(fw): thu mount the SD 3 lan luc boot
    Reset mem (RST, OTA, WDT) khong ngat dien the, lan SD.begin() dau sau reset
    hay fail du the van tot -> hop chay rong: isFull() = true, unread = 0, log
    "msg skip: het slot, unread=0" moi chu ky sync. Thu toi da 3 lan cach 200ms,
    khong giu spiMutex luc cho. Sua comment "unread=0" o NetworkManager cho dung
    nghia (the khong mount, khong phai con tro ghi tro nham). MEMORY.md §26.
2026-09-23 feat(fw): cham phat tin luc dang sync thi xep hang, sync xong tu phat
    Cham ngan luc sync dang chay (Wi-Fi, NTP, co, status, khe giua hai tin) tung
    goi playItem() ngay: phat (~74KB) chong len phien TLS (35-45KB) tren chip mot
    loi -> giat, va da thay reboot that. Nay bat co s_pendingPlay (hang doi 1 cho),
    hien "Dang dong bo, se tu phat...", Task_MediaPlayer quet moi vong va phat khi
    !isSyncing(). Nhanh hasPendingMessages() cung cho tai xong tu phat.
    User chot 2026-09-24: han cho 60s (PENDING_PLAY_MAX_WAIT_MS), cham luc dang
    tai media van bo qua, che do AP cau hinh Wi-Fi khong tinh la ban. Huy cho khi
    het han, bao thuc keu, cham giu; chan ngu luc dang cho. MEMORY.md §27.
    Kem trong config.h: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
    [config.h, main.cpp]
2026-09-24 fix(fw): bo sleep(2000) chan task phat, nghi sau sync bang cach dem
    sleep() cua newlib tinh bang GIAY nen dong sleep(2000) lot vao b1388d8 chan
    Task_MediaPlayer ~33 phut: khong phat, cham khong ai xu ly, thuc day man den.
    Gio lenh phat cho doi sync ranh lien tuc PENDING_PLAY_SETTLE_MS (10s) roi moi
    phat, dem trong vong lap, sync chay lai thi dem tu dau.
    [config.h, main.cpp]
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2026-09-26 feat(hw): schematic khoi vi dieu khien ESP32-C3-MINI-1
    - 3V3: 10uF 0603 + 100nF 0402 sat chan. EN: 10k len 3V3 + 1uF xuong GND,
    nut RESET keo EN xuong GND.
    - Strapping: 10k keo len o GPIO2 (I2S_DOUT), GPIO8 (SD_CS), GPIO9 (TFT_RST).
    Nut BOOT noi GPIO9 qua 1k (GPIO9 dang xuat HIGH cho TFT RST).
    - Nhan net theo chuc nang dung bang chan BOM.md: I2S_BCLK/LRC/DOUT (0/1/2),
    TFT_BLK (3), SPI_SCK/MISO/MOSI (4/5/6), TFT_DC (7), SD_CS (8), TFT_RST (9),
    TOUCH_OUT (10), USB_DN/DP (18/19), AMP_EN (20), LED_NOTIFY (21).
    Cac nhan ngoai vi chua co dau kia; se noi o cac khoi sau.
    [main.kicad_sch]
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2026-09-26 fix(hw): RT9080 dung footprint TSOT-23-5, ghi ket qua doi chieu datasheet
    - RT9080-33GJ5 la goi TSOT-23-5 (datasheet DS9080-09), doi footprint tu SOT-23-5.
    So do chan 1 VIN, 2 GND, 3 EN, 4 NC, 5 VOUT khop symbol da tao.
    - TP4056-42: nguong TEMP 45%/80% VIN da doi chieu datasheet rev 2.4. Voi NTC
    B3950 + 6.2k, cua so sac thuc te ~6-41 do C (truoc ghi ~5-45).
    - Da doi 15 cap GPIO <-> nhan net cua U4 voi bang chan BOM.md: khop het.
    [main.kicad_sch]
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2026-09-30 fix(fw): đọc cài đặt bằng khoảng khoá thay shallow, bíp to hơn; cập nhật MEMORY.md
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2026-09-30 fix(web): trang sửa giao diện sập vì widget pin bị coi là widget phông
    isVlw trả true cho loại không có phông (undefined === undefined), widgetProblem
    đọc PX_RANGE[battery_icon] -> TypeError, bố cục mặc định luôn có pin.
2026-09-30 fix(backend): lưu Wi-Fi không gửi mật khẩu thì giữ mật khẩu đã lưu
    Trước đây mỗi lần lưu ghi đè pwd = '' vì web không đọc lại được mật khẩu.
    pwd undefined -> chỉ đổi ssid; pwd '' -> mạng mở (người dùng chọn rõ).
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2026-09-30 fix(web): cuộn lên đầu khi đổi trang và khi đổi bước gửi tin
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2026-09-30 feat(web): ảnh thu nhỏ trên dòng tin nhắn; người nhận xem được nội dung chữ ngay trong danh sách
    Dòng tin dùng chung MessageRow cho cả hai phía. Không có thumbnail (tin chữ/thoại,
    backend chưa deploy, URL hết hạn) thì về icon như cũ. Thêm icon play/pause/stop/
    pencil/replace.
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2026-09-30 fix(web): popup ghim theo màn hình, không còn nằm ở đáy trang dài ngoài tầm nhìn
    .sl-scrim absolute theo .sl-shell (cao bằng cả trang) -> fixed theo viewport.
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2026-09-30 fix(web): thanh gửi nền không che nút Lưu ở Cài đặt hộp
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2026-10-01 fix(web): iPhone không còn tự phóng to trang khi chạm vào ô nhập
    Safari iOS zoom cả trang khi ô nhập có chữ < 16px. Nâng lên 16px chỉ trên iOS
    (@supports -webkit-touch-callout); Android/desktop giữ 15px theo thiết kế.
    Chưa thử được trên iPhone thật.
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2026-10-02 refactor(fw): gộp code lặp trong NetworkManager (đọc timestamp, dựng URL Storage)
    - messageTimestamp() thay 2 bản sao trong comparator của std::sort;
    messageTimestampOrNow() (thêm bước lùi về giờ NTP / millis()) thay 2 bản
    sao ở vòng đếm và vòng tải. Bước lùi cố ý không nằm trong comparator.
    - resolveMediaUrl() dùng cho media và voice; storageDownloadUrl() dùng thêm
    cho downloadFile(), vốn không chuẩn hoá gs:// hay dấu / đầu.
    Hành vi không đổi: test trên máy tính so đoạn cũ với hàm mới (20 dạng
    timestamp x 4 mốc đồng hồ, không lệch), agent review đối chiếu từng chỗ
    gọi, pio run thành cô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
